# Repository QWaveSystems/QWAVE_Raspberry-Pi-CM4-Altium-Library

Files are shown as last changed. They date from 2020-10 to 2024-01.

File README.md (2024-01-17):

# QWAVE_Raspberry-Pi-CM4-Altium-Library
Raspberry Pi Compute Module 4 (CM4) Full Library, Design Template&amp;Guideline for Altium Designer

**If you find this package is useful, please consider supporting me.

# Contact me if you want customization. 
** Amornthep Phunsin amornthep@qwavesys.com

# Note:
**This library has been fully tested with various projects that I made refer below.**

# Demo Project: CM4 IoT Gateway,PCIe M2.SSD,Modbus 485/TCP,NB-IoT,GPS,WiFi,BT,DI/DO,Relay,AI (0-5/10)V.
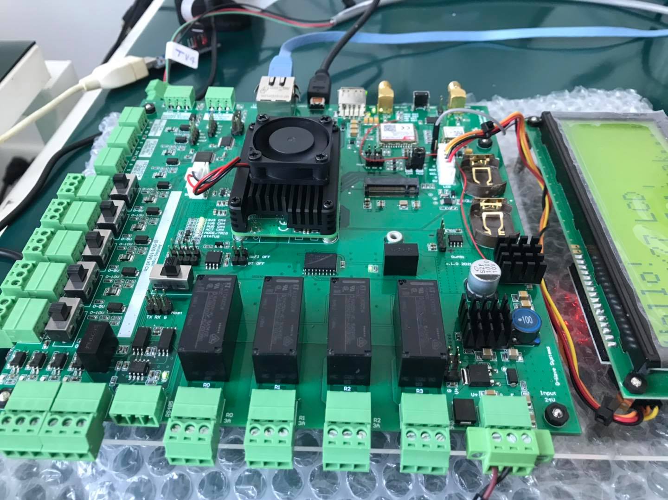
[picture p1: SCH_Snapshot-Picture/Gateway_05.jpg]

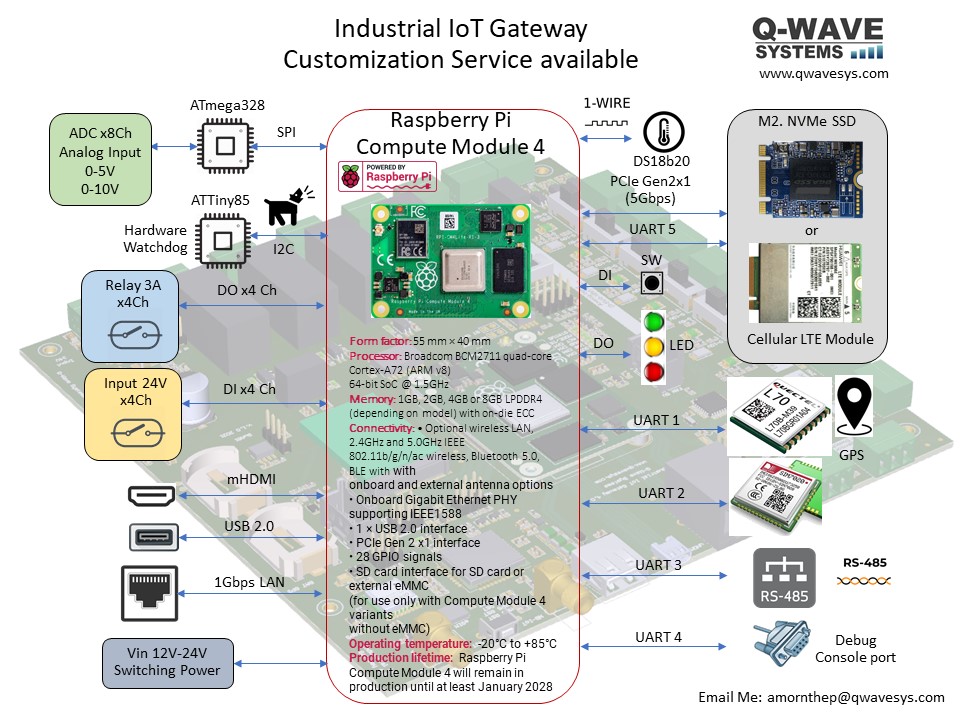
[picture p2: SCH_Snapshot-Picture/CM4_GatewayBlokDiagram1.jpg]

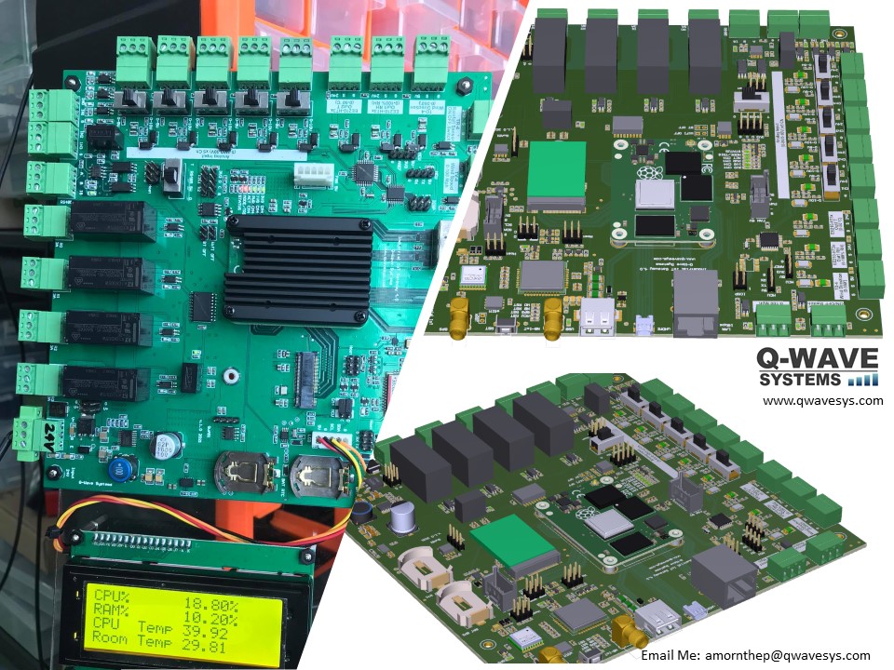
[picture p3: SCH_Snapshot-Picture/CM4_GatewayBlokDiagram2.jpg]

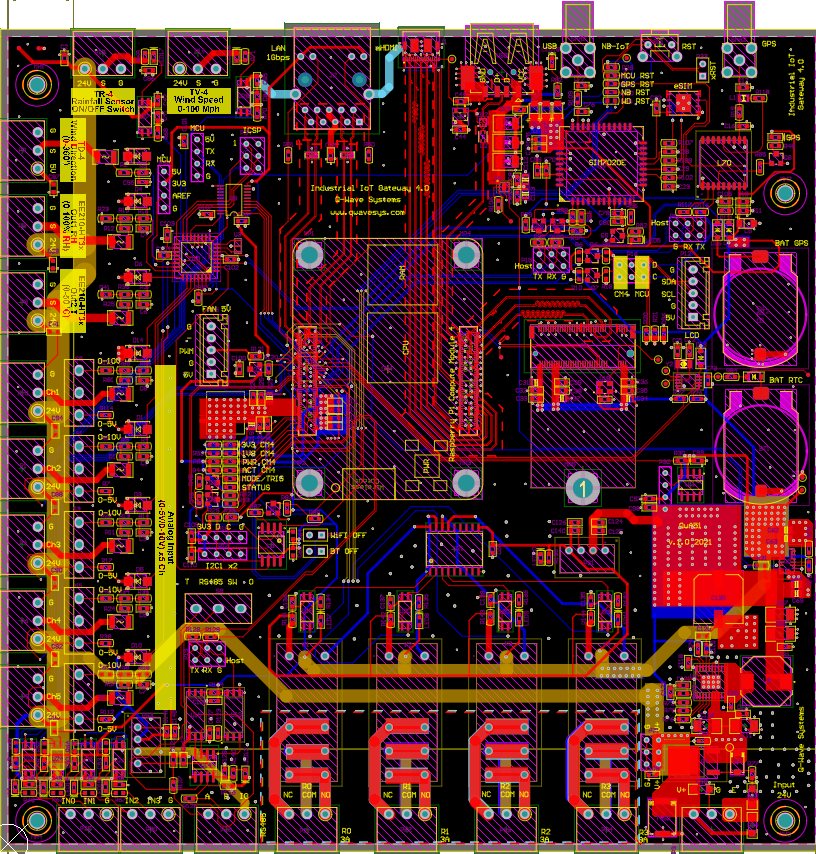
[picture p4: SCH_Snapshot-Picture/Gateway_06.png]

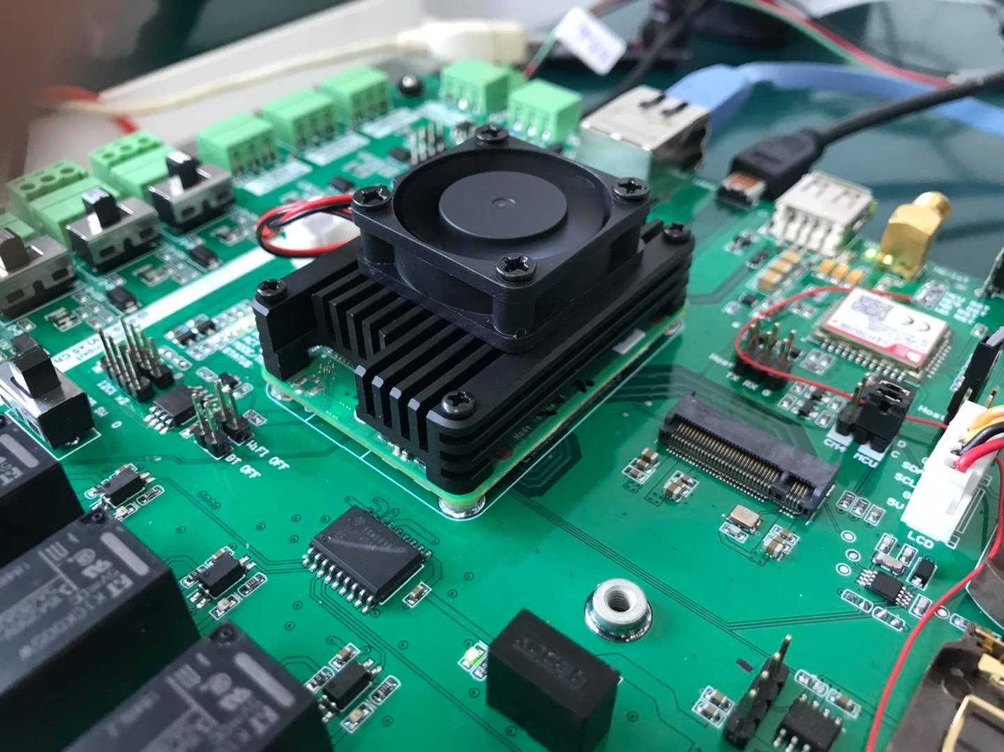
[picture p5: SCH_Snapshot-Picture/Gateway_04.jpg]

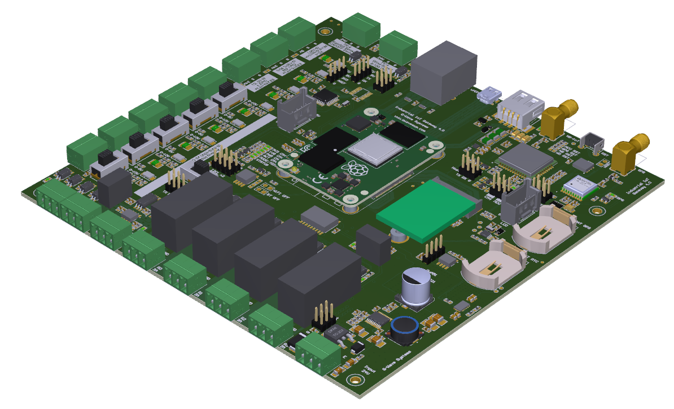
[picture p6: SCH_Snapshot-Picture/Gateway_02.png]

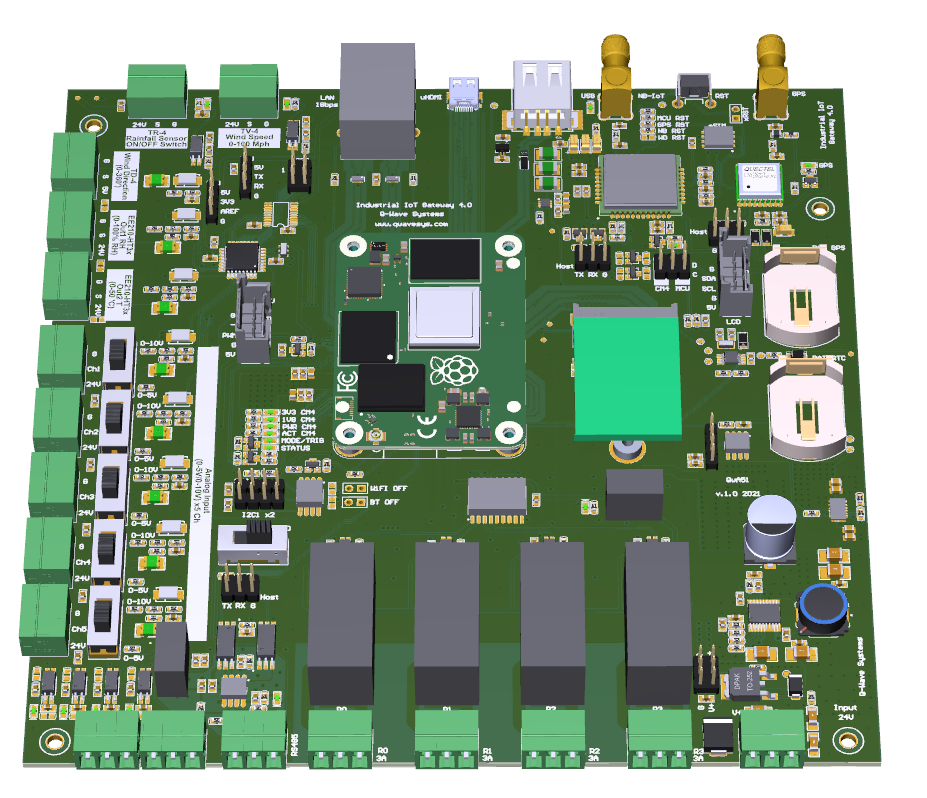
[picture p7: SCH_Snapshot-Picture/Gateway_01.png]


# Demo Project: CatsEYE Flasher - USB Flasher for CM4.
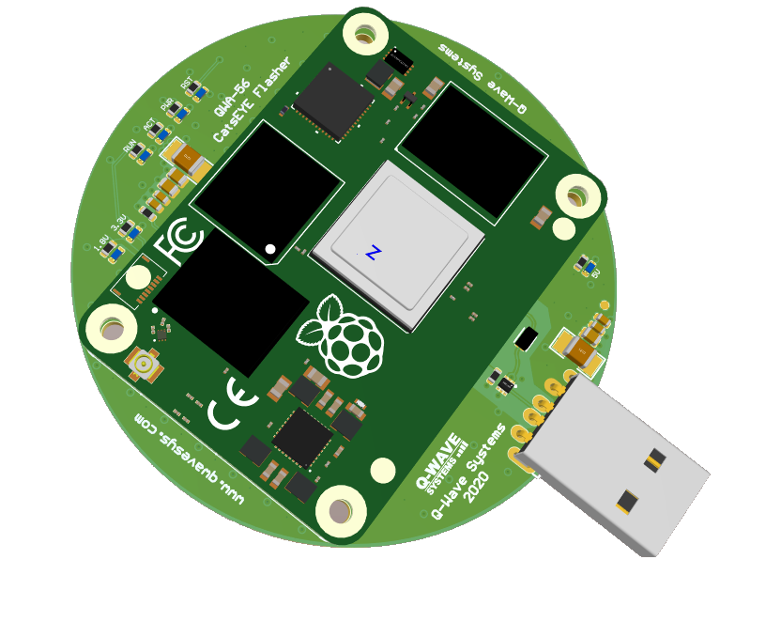
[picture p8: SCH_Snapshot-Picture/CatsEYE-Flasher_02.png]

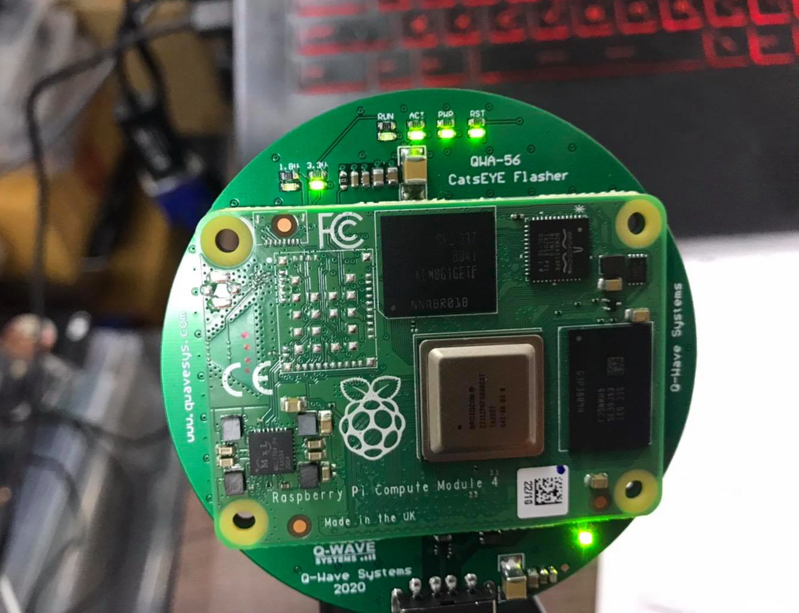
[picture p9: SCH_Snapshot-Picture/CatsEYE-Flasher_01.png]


# Demo Project: CatsPi Dev Board - Rpi CM4 dev board (85x56mm) compatible with standard HAT and enclosure.
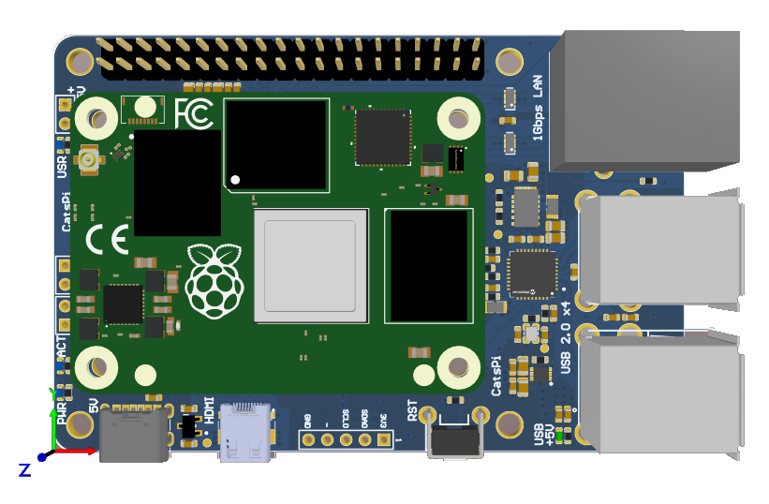
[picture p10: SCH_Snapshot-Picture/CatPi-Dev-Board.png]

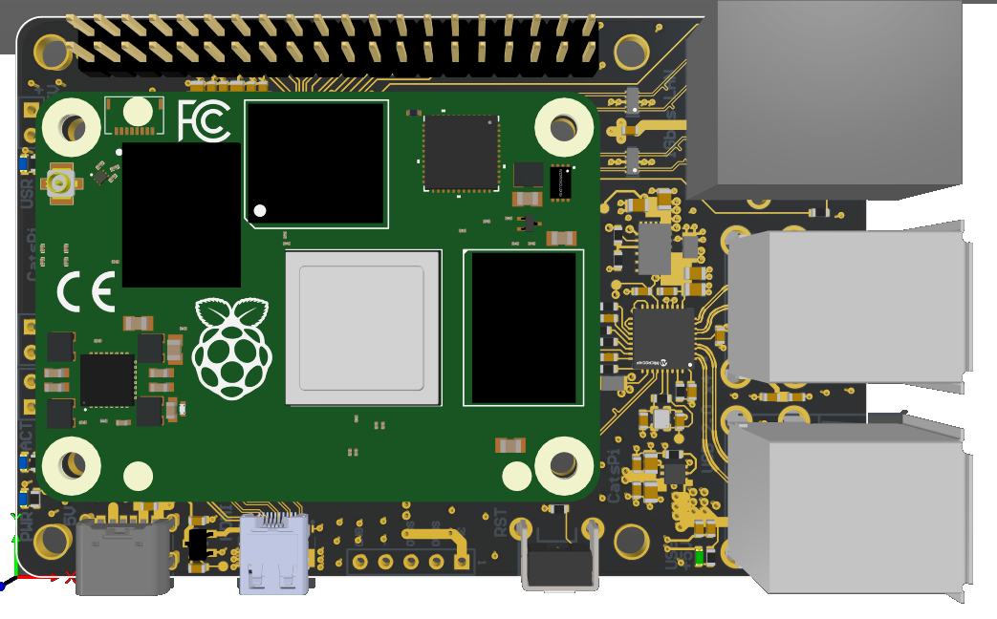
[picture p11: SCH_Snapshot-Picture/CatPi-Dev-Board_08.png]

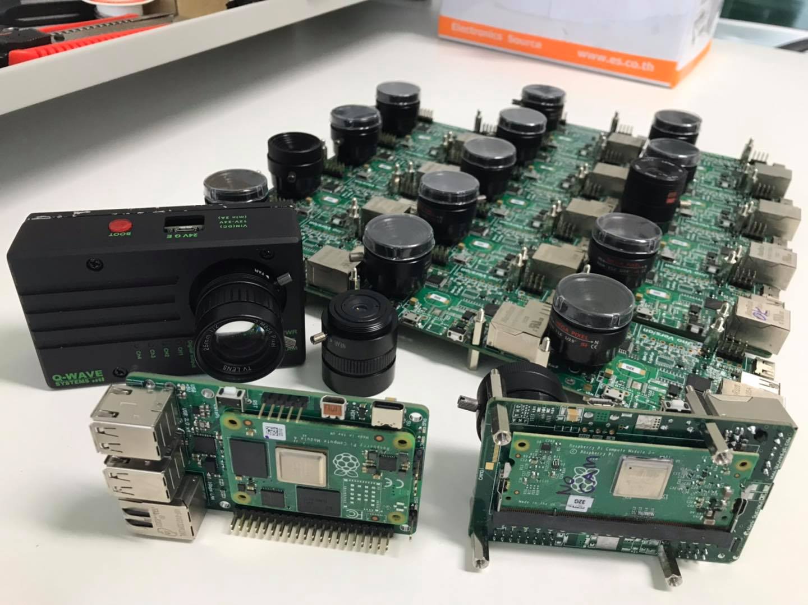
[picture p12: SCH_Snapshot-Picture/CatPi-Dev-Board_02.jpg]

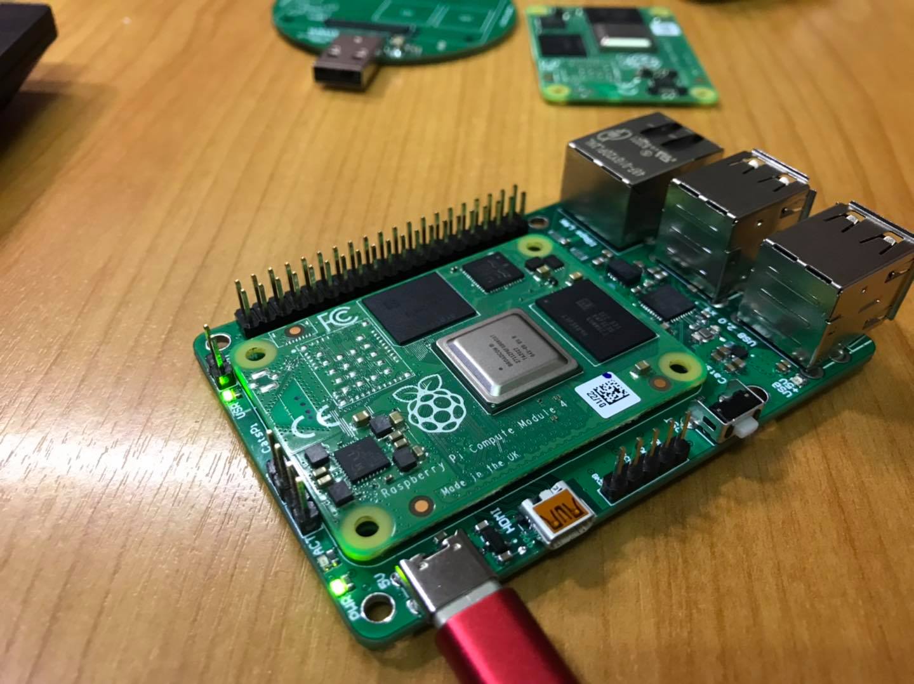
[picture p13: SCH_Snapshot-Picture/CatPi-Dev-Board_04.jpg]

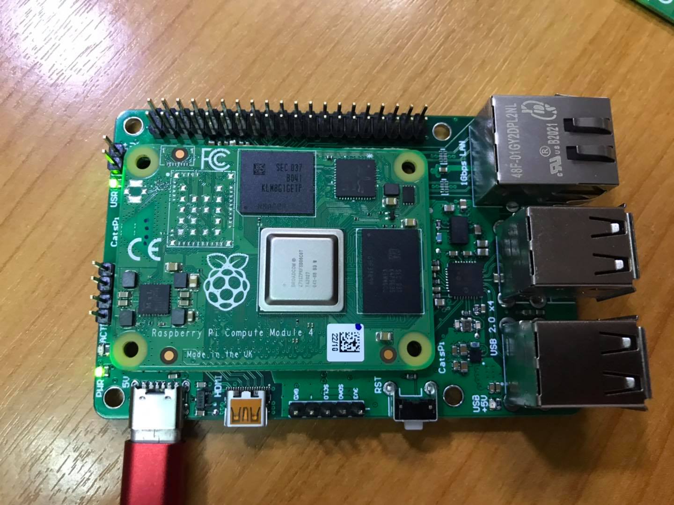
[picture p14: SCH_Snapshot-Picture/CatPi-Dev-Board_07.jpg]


# Demo Project: SeaBOX HDMI Stick using CM4.
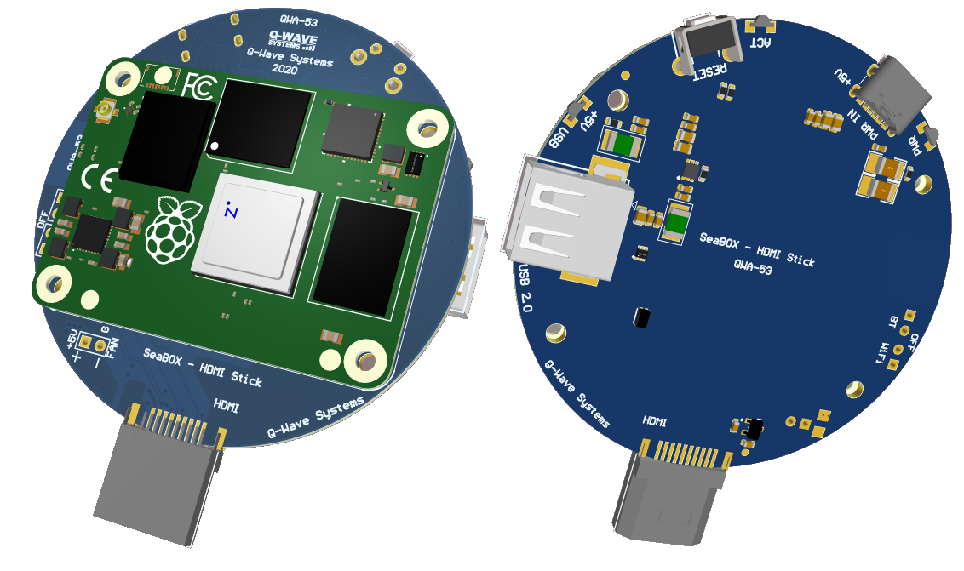
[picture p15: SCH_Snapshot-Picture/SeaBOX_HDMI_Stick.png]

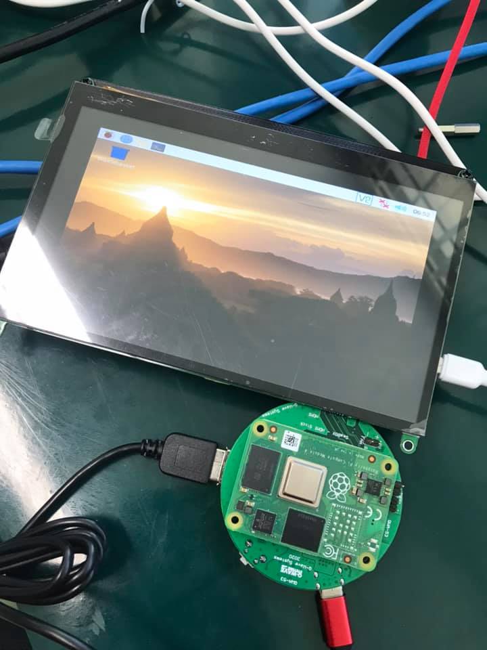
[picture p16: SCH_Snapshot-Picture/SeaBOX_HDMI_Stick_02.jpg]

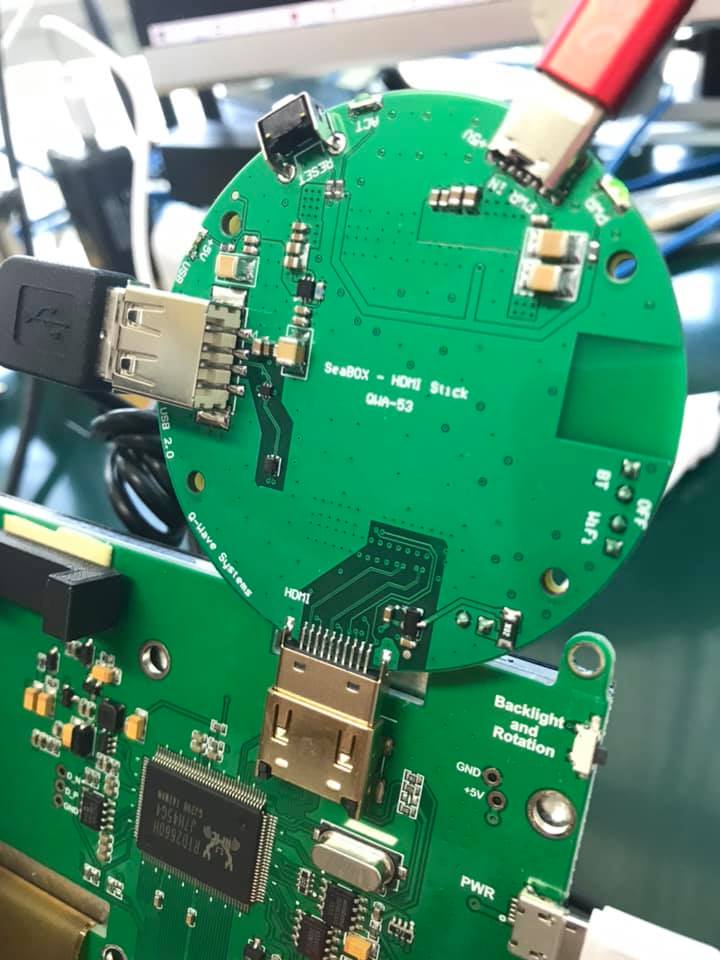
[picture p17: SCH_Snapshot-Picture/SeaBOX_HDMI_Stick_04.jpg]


# Demo Project: CatsPi HAT Flip Edition - compatible with standard HAT plug at bottom side.
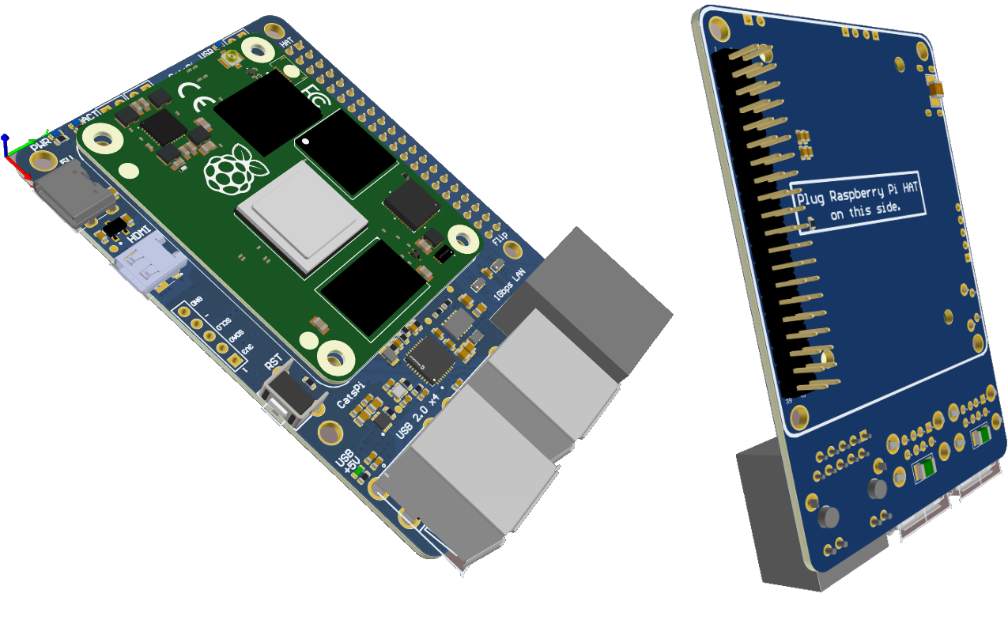
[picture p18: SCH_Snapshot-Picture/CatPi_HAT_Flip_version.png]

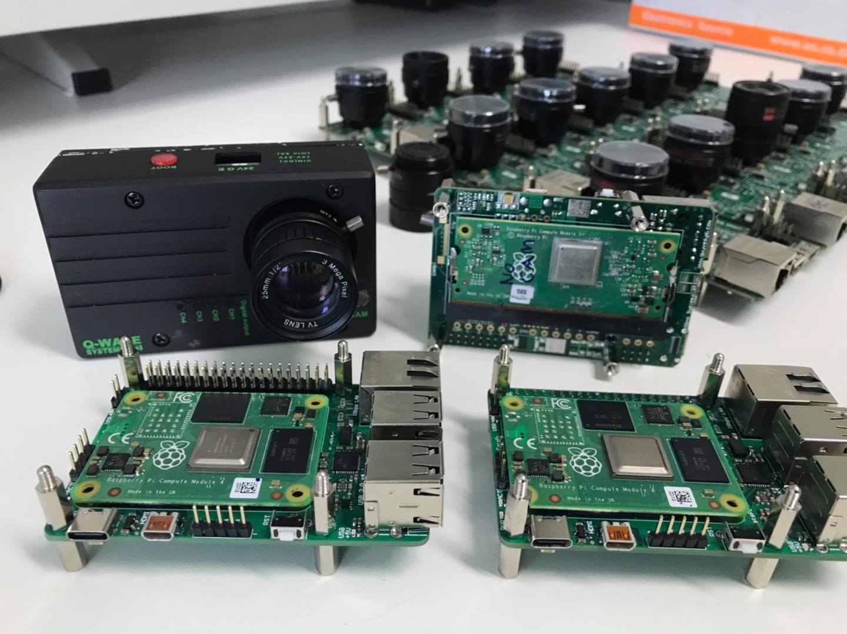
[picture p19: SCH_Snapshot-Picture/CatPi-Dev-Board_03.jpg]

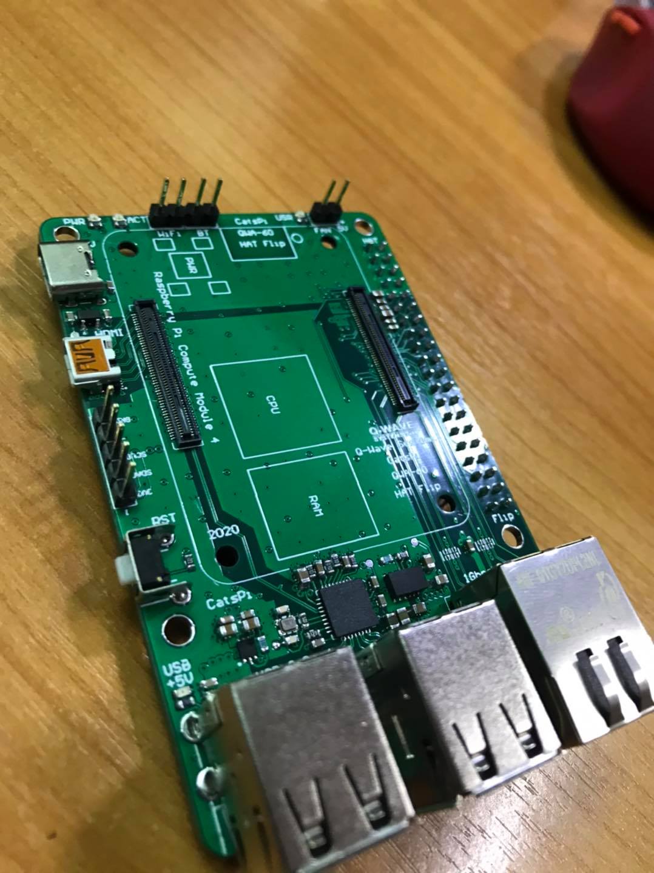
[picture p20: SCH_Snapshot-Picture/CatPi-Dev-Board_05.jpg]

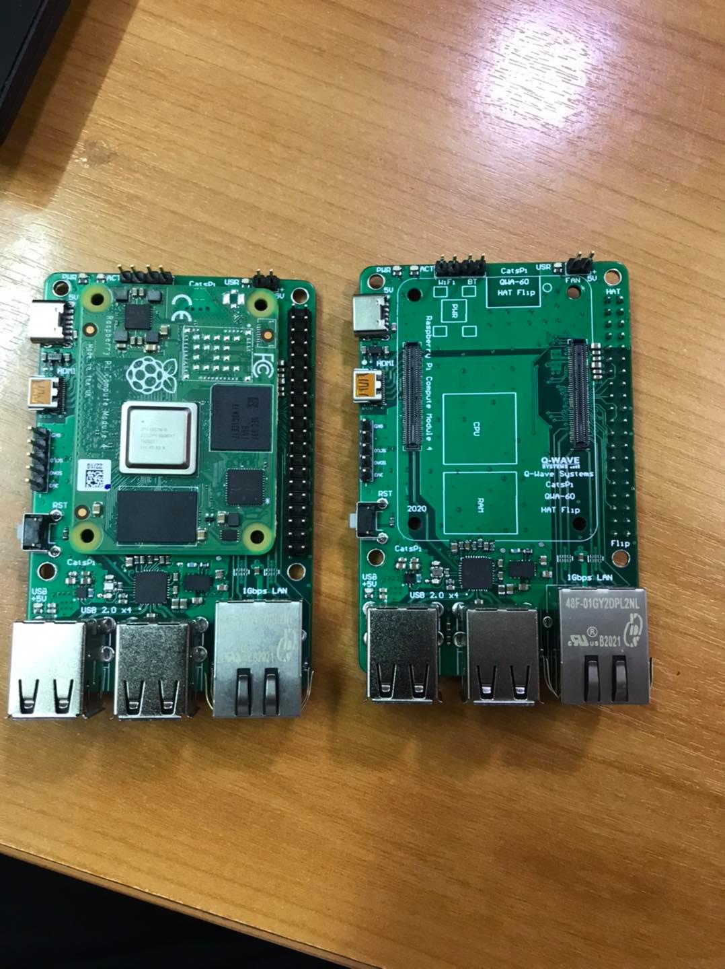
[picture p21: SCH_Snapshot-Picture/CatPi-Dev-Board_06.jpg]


# Demo Project: SeaBOX HDMI Stick PoE Edition.
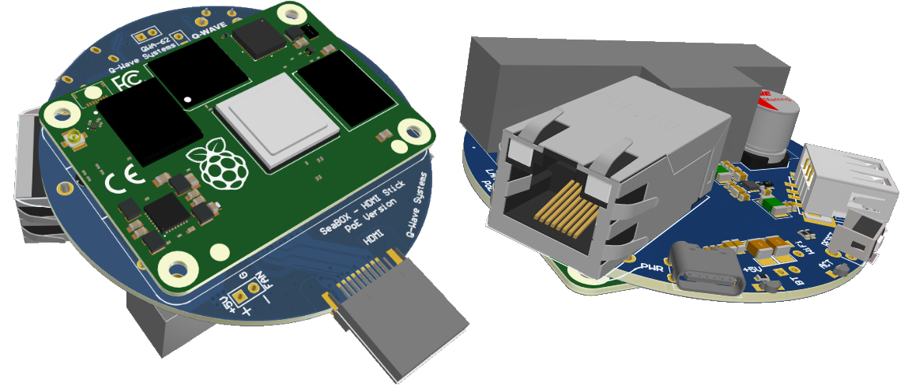
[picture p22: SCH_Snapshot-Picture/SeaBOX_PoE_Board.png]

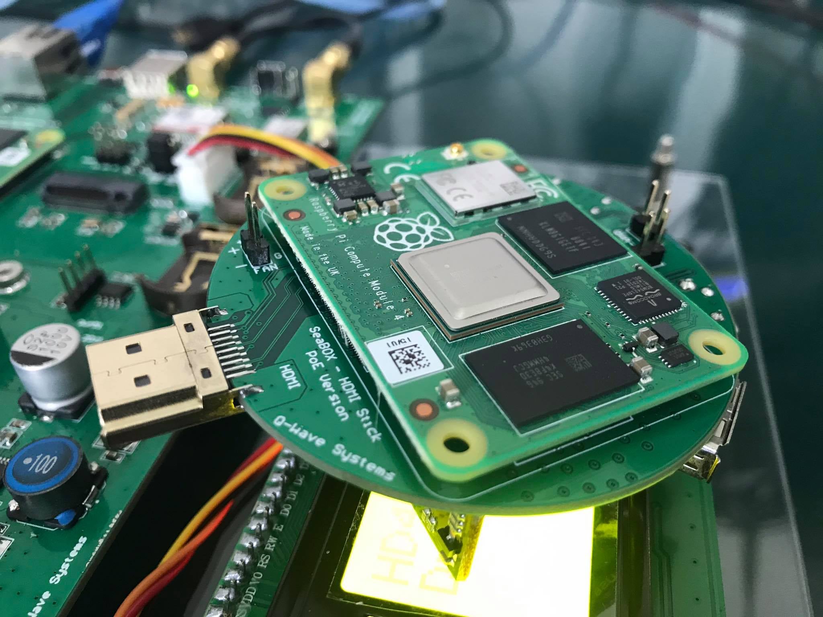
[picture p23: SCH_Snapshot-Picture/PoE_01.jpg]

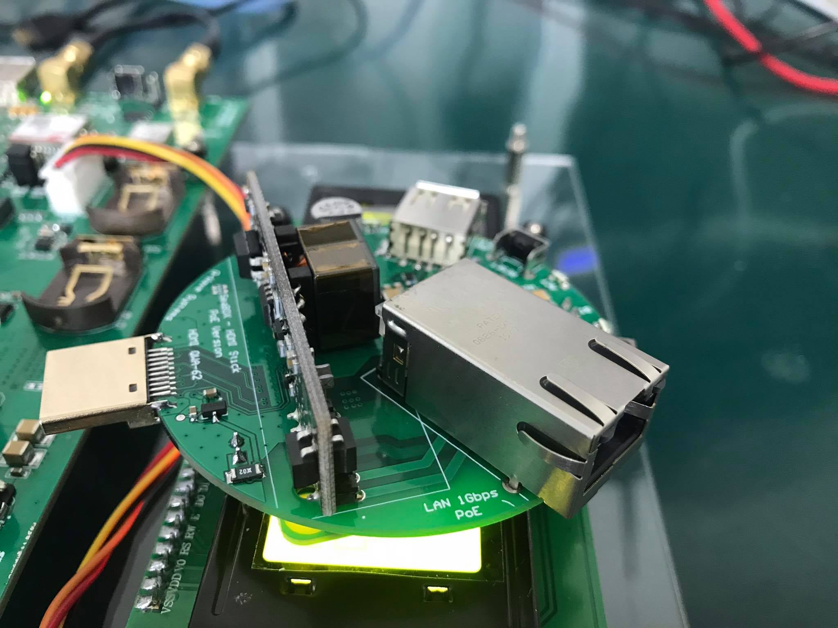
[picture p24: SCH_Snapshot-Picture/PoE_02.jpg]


# Official Raspberry Pi Document for CM4.

[Compute Module IO board design data](https://github.com/raspberrypi/documentation/blob/master/hardware/computemodule/designfiles.md)

[Compute Module 4 IO Board datasheet](http://datasheets.raspberrypi.org/cm4io/cm4io-datasheet.pdf)

[Compute Module 4 IO Board KiCAD PCB design](http://datasheets.raspberrypi.org/cm4io/CM4IO-KiCAD.zip)

[CM4 3D Model STEP File](https://datasheets.raspberrypi.org/cm4/CM4-step.zip)

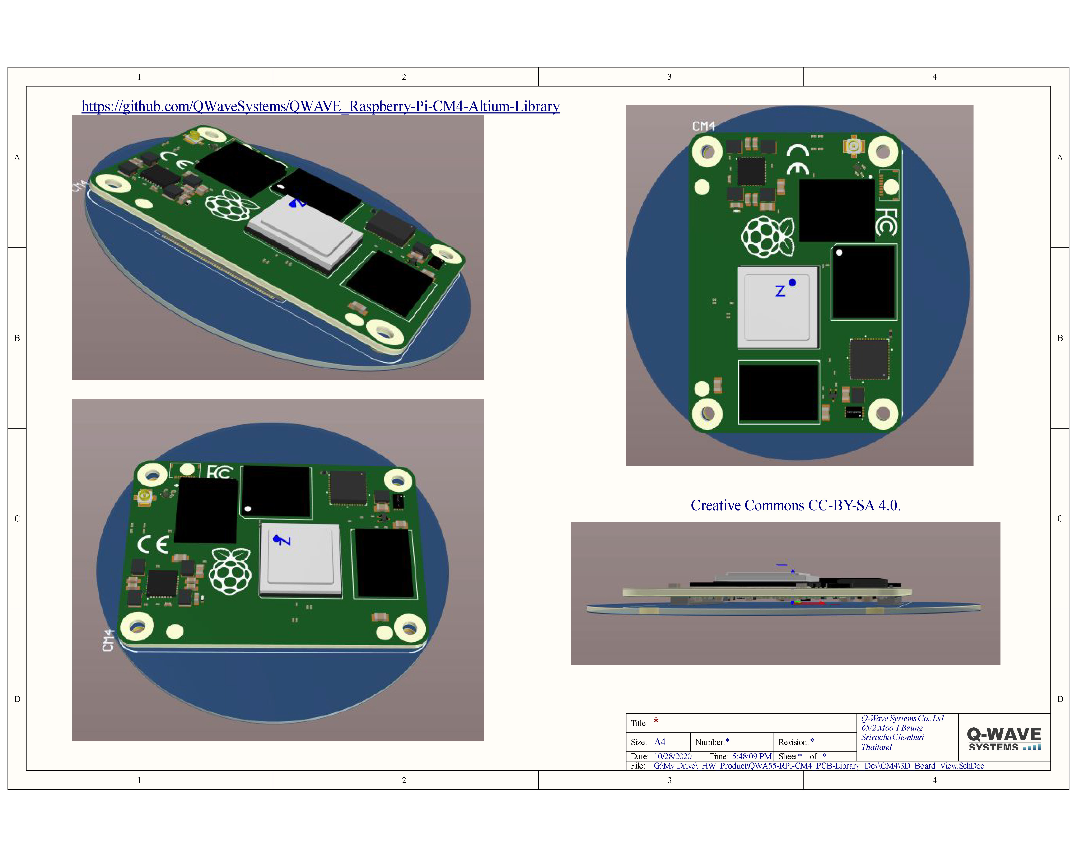
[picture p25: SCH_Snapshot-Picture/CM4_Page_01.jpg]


## Description:
These are the schematic libs,footprint libs,sch template,guideline for design custom carrier circuit board for Raspbeery Pi compute module 4 (CM4).

## License:
Raspberry Pi Compute Module 4 (CM4) Full Library for Altium Designer

Copyright (C) 2020 Amornthep Phunsin
Email: amornthep@qwavesys.com

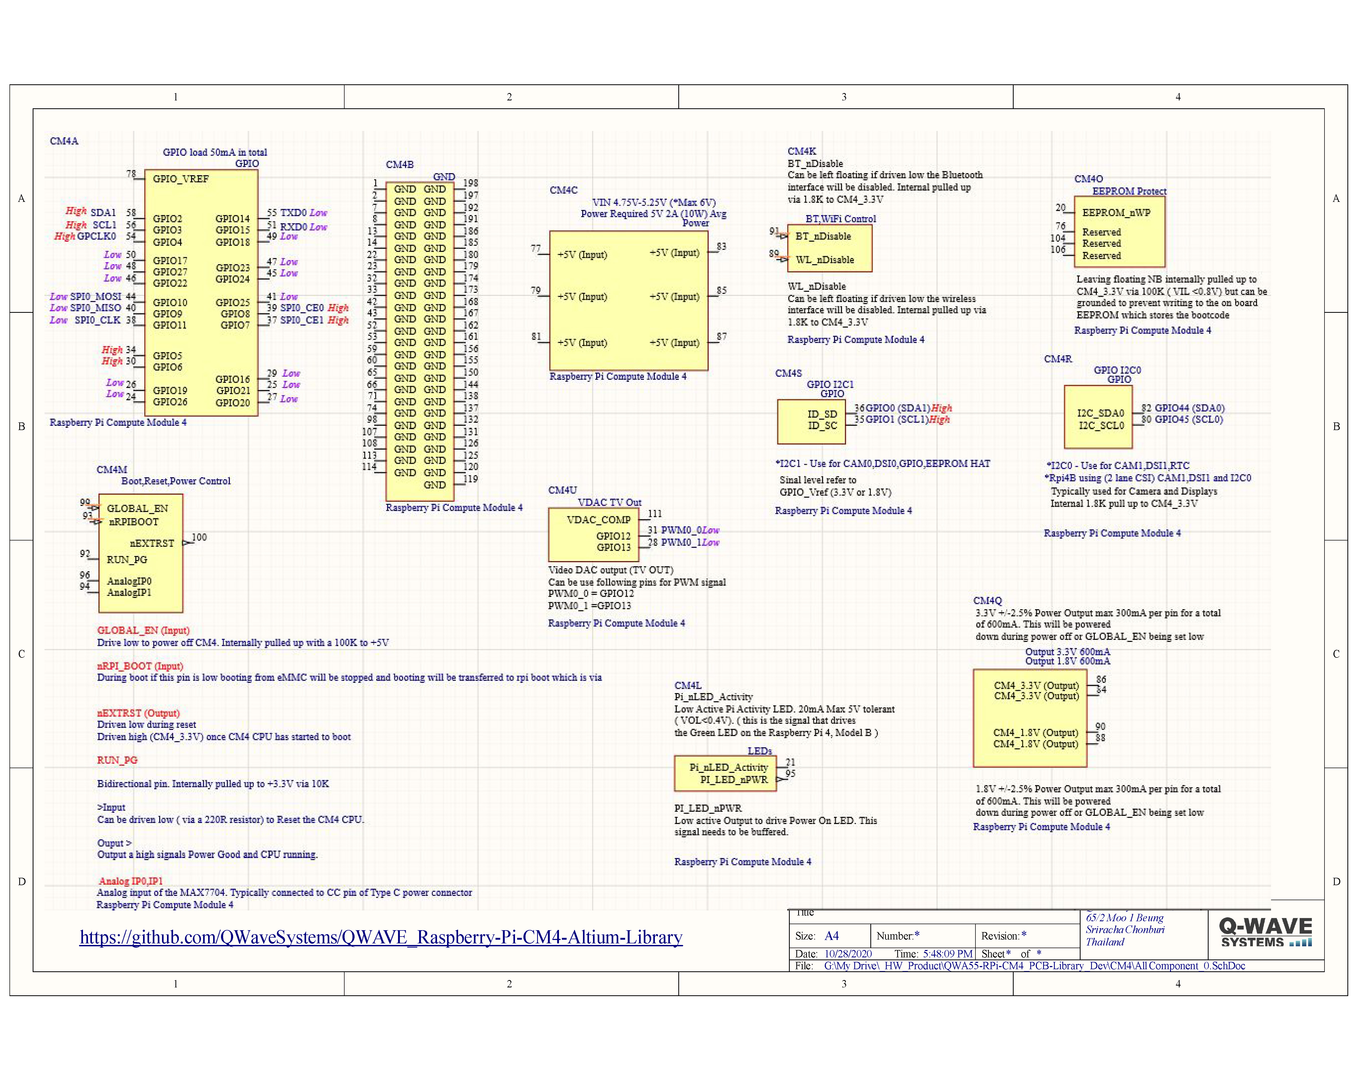
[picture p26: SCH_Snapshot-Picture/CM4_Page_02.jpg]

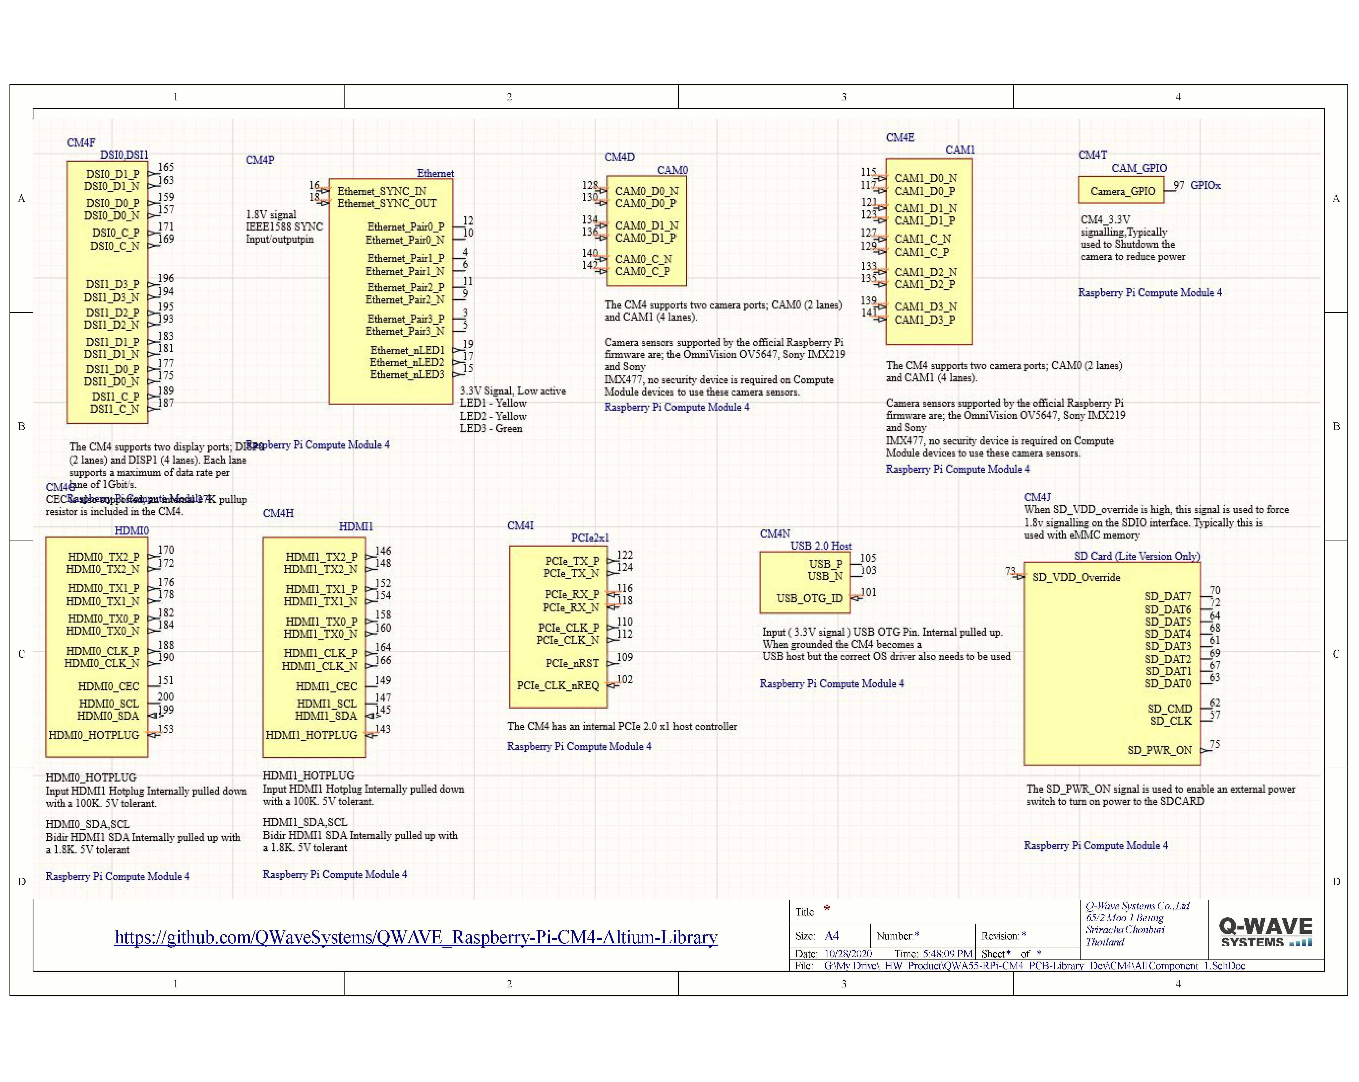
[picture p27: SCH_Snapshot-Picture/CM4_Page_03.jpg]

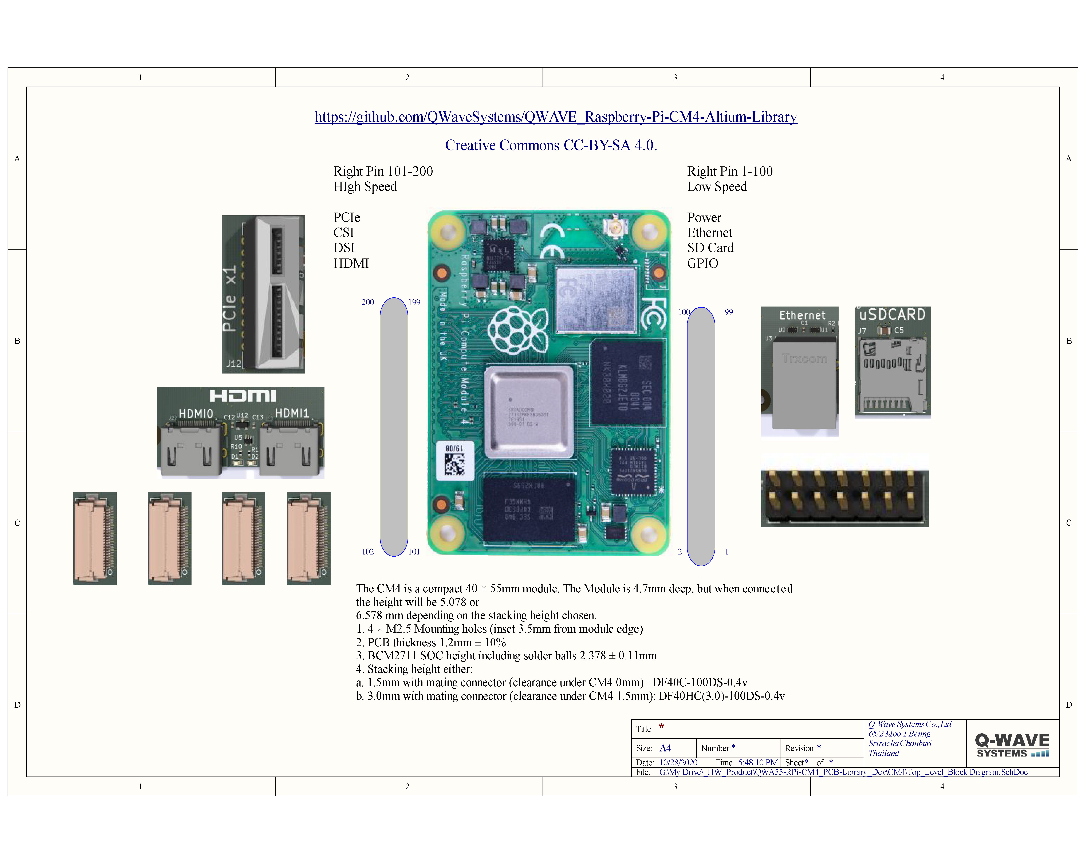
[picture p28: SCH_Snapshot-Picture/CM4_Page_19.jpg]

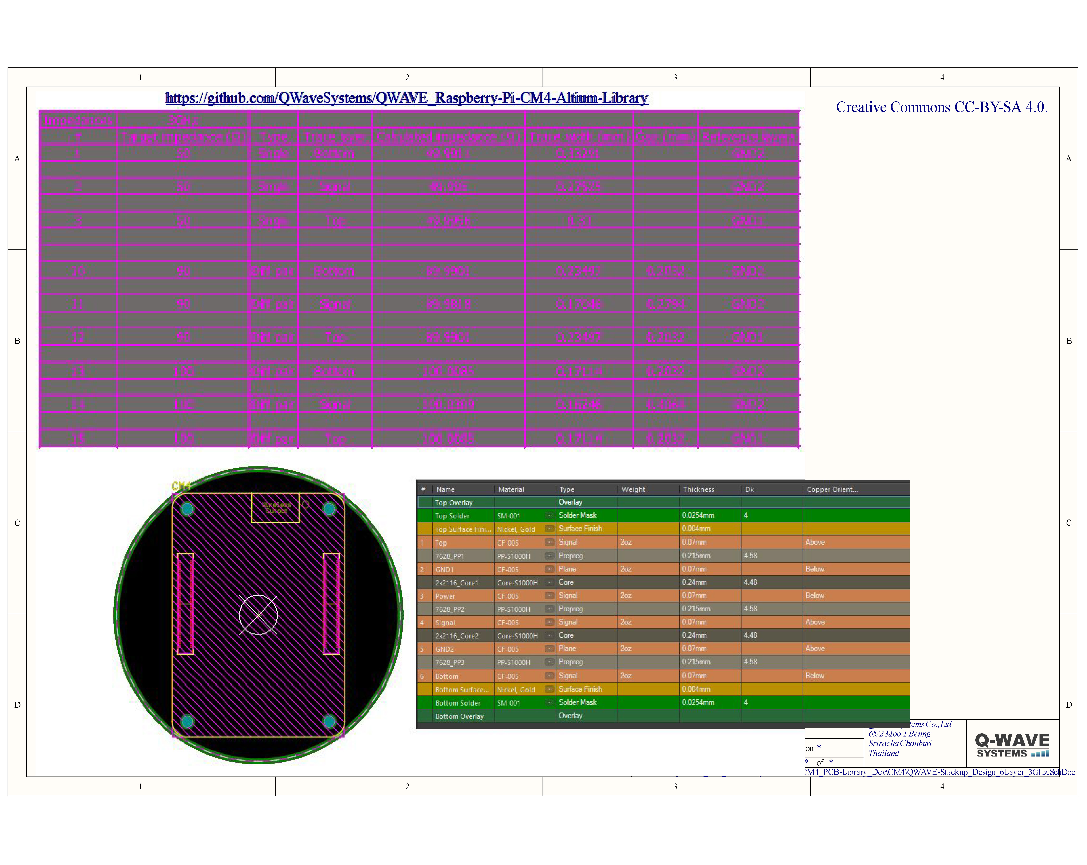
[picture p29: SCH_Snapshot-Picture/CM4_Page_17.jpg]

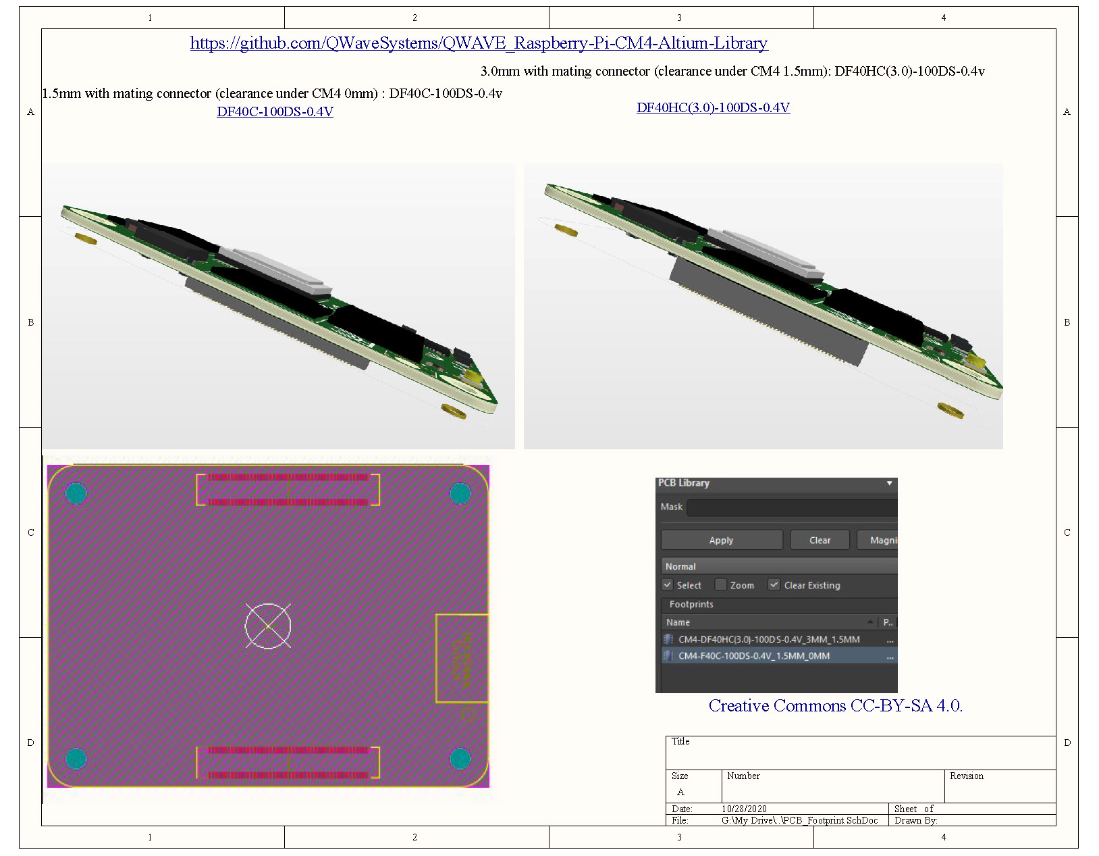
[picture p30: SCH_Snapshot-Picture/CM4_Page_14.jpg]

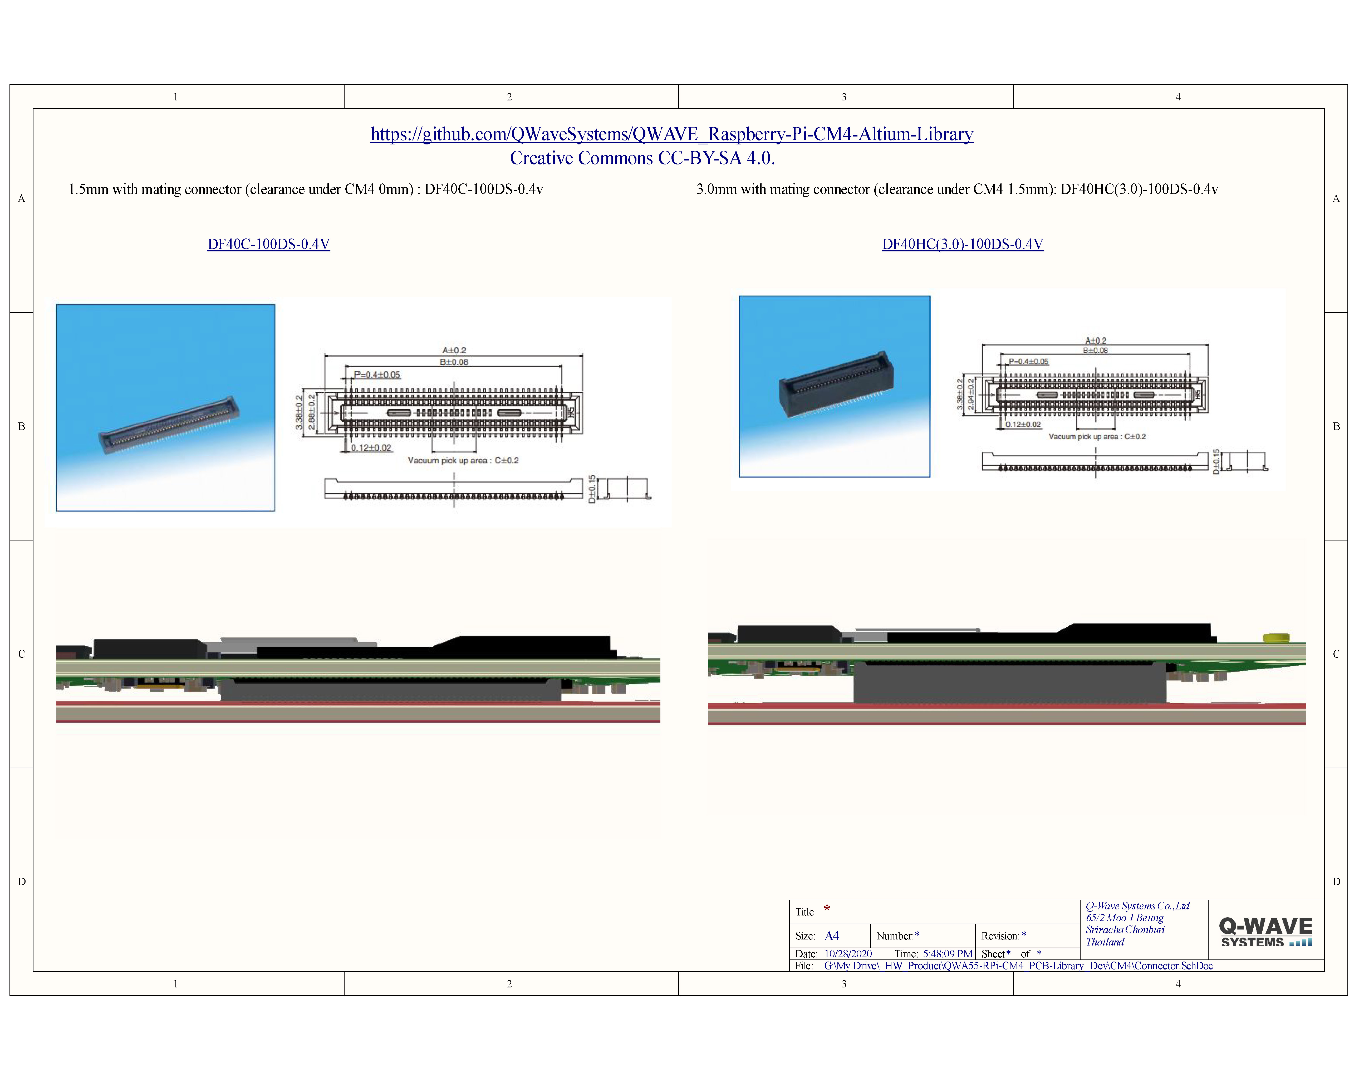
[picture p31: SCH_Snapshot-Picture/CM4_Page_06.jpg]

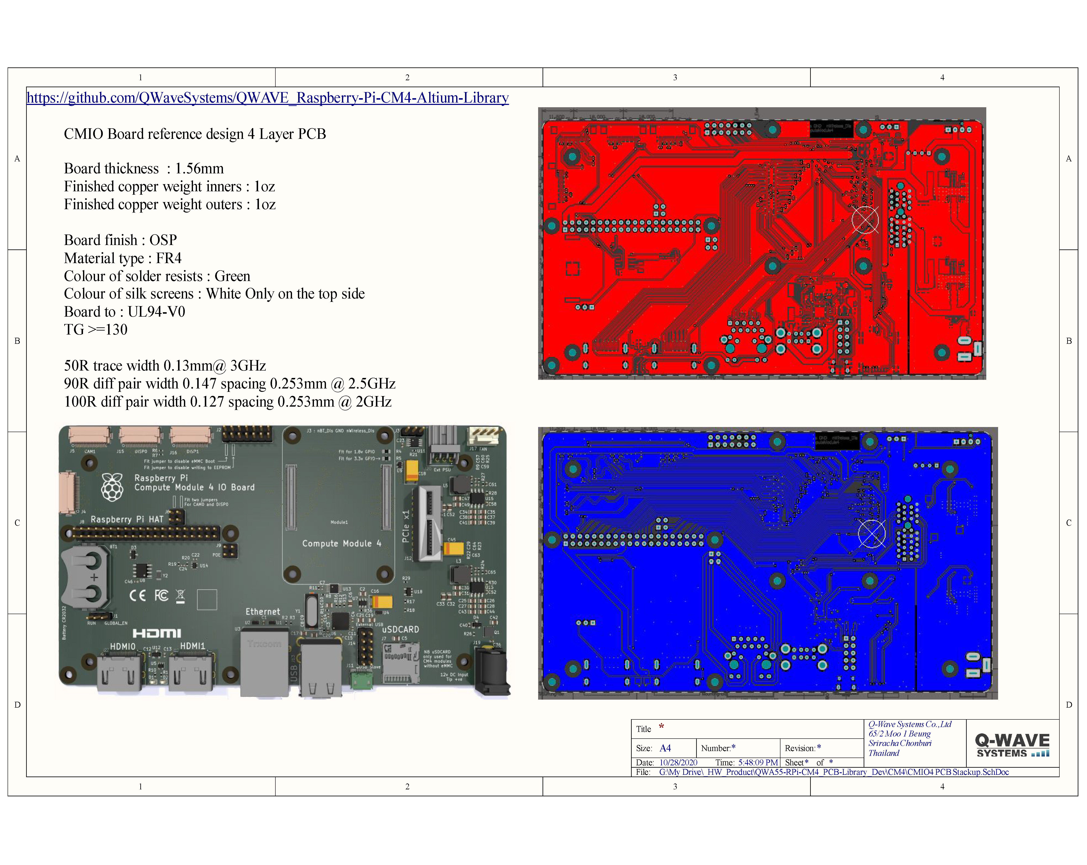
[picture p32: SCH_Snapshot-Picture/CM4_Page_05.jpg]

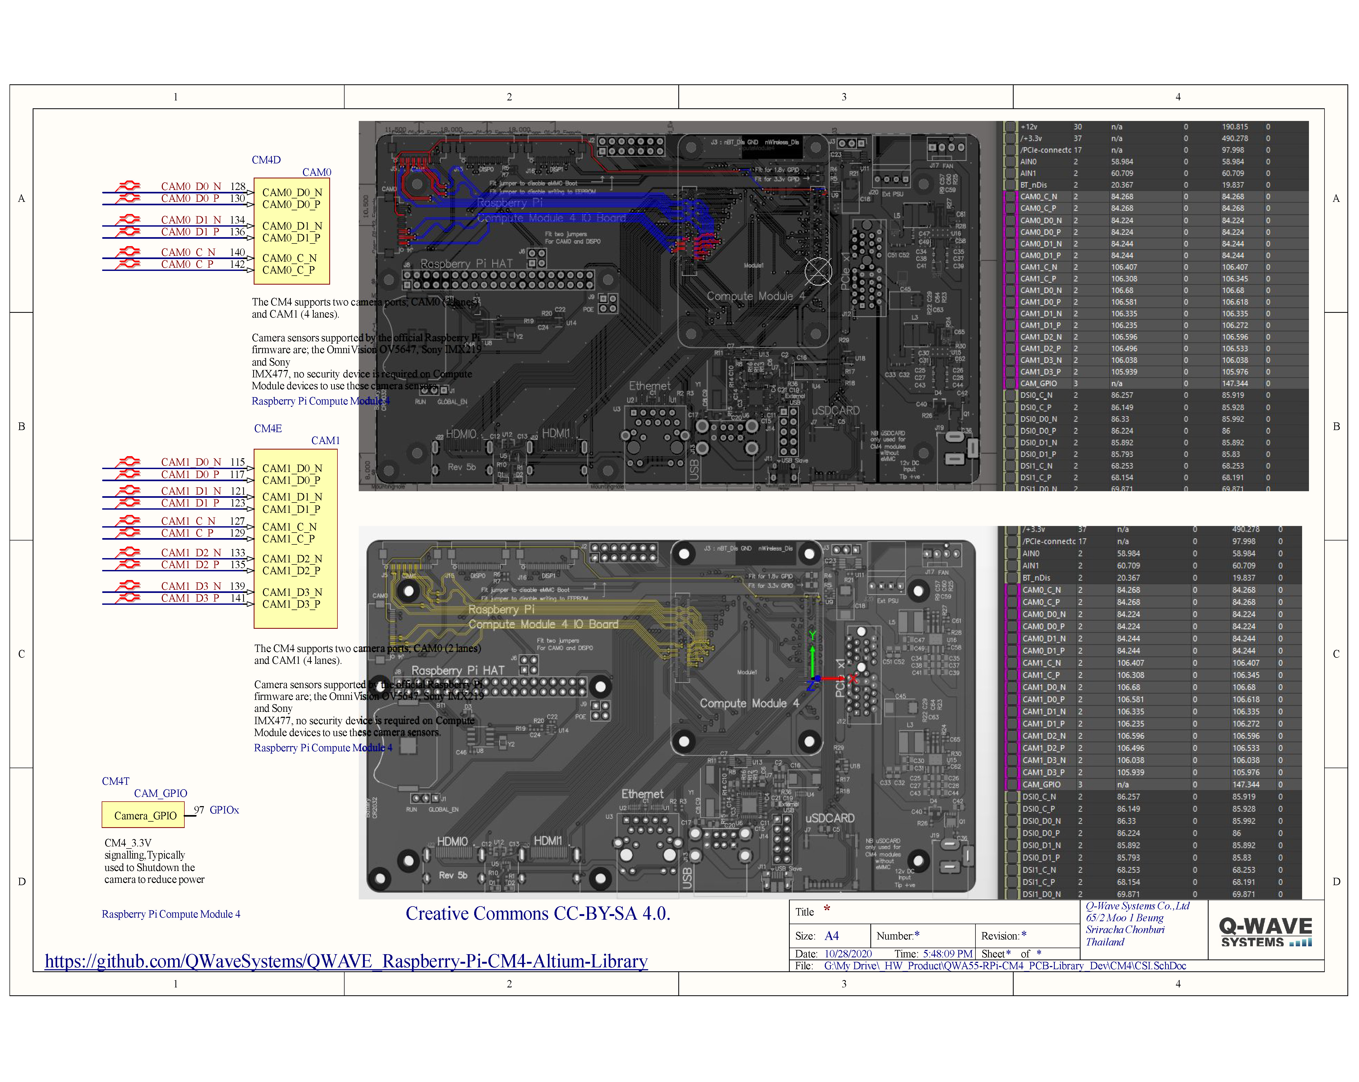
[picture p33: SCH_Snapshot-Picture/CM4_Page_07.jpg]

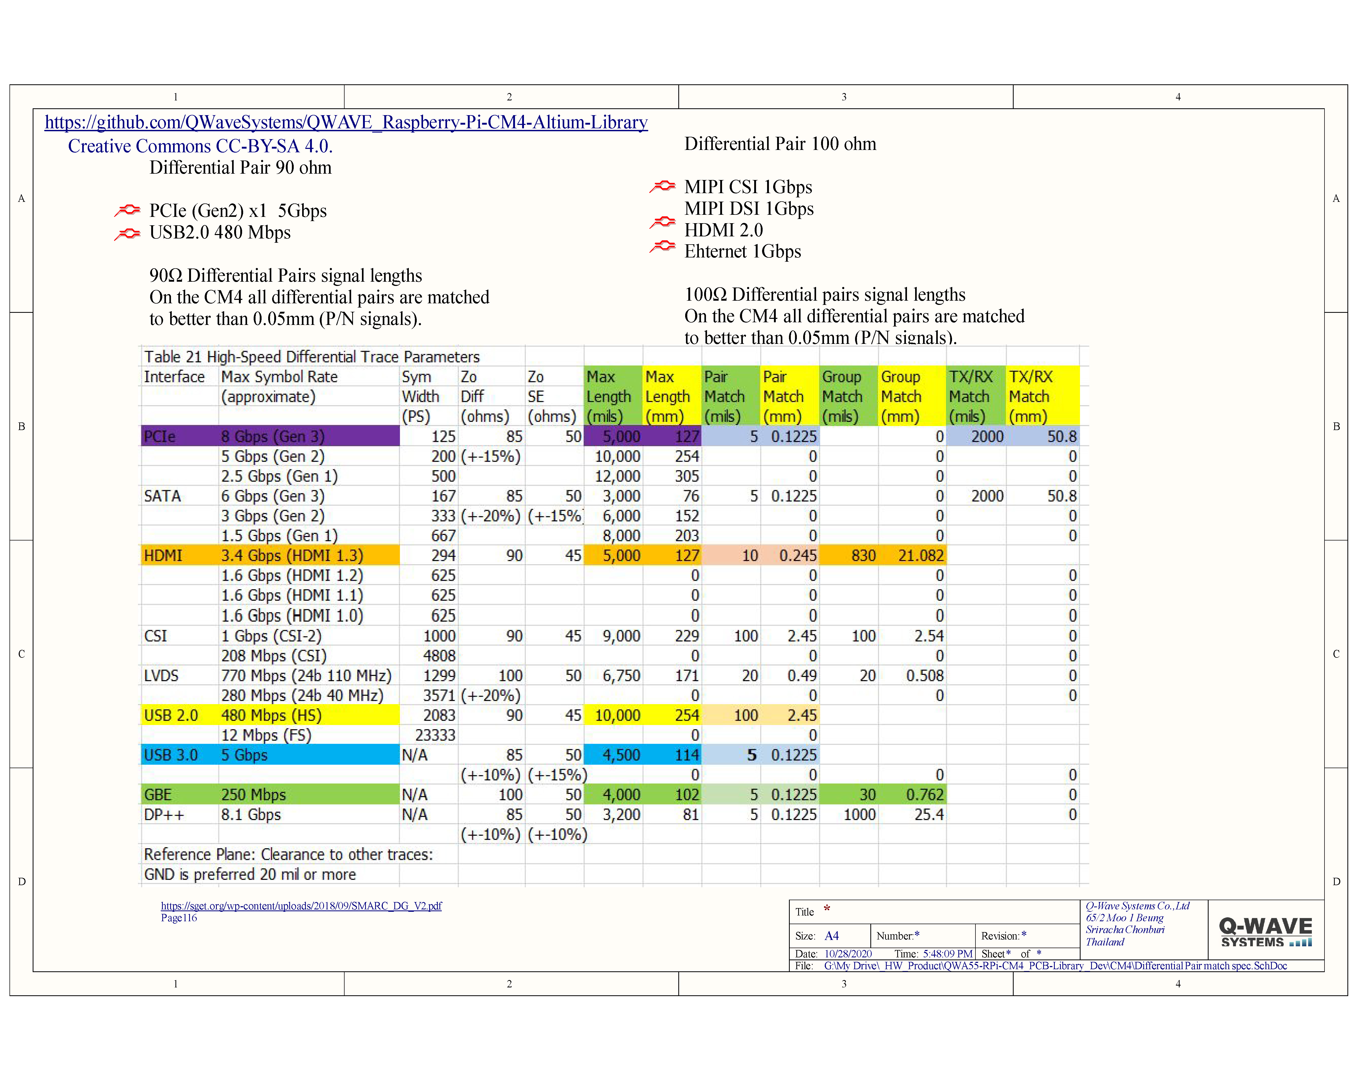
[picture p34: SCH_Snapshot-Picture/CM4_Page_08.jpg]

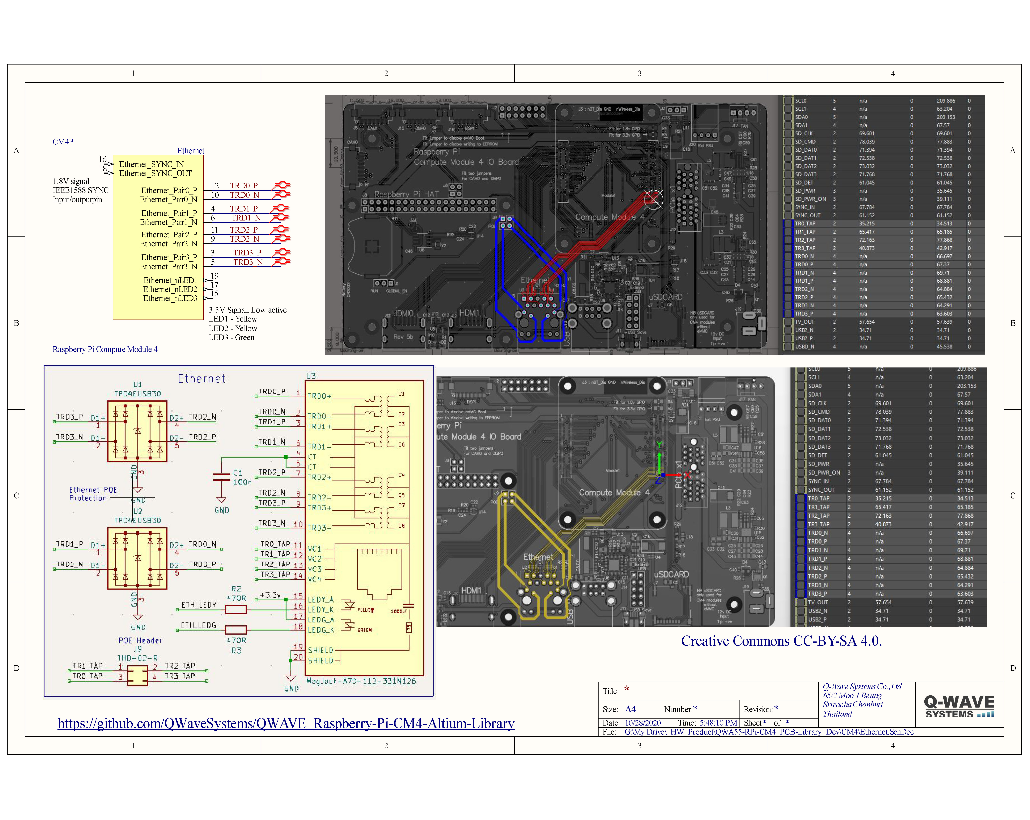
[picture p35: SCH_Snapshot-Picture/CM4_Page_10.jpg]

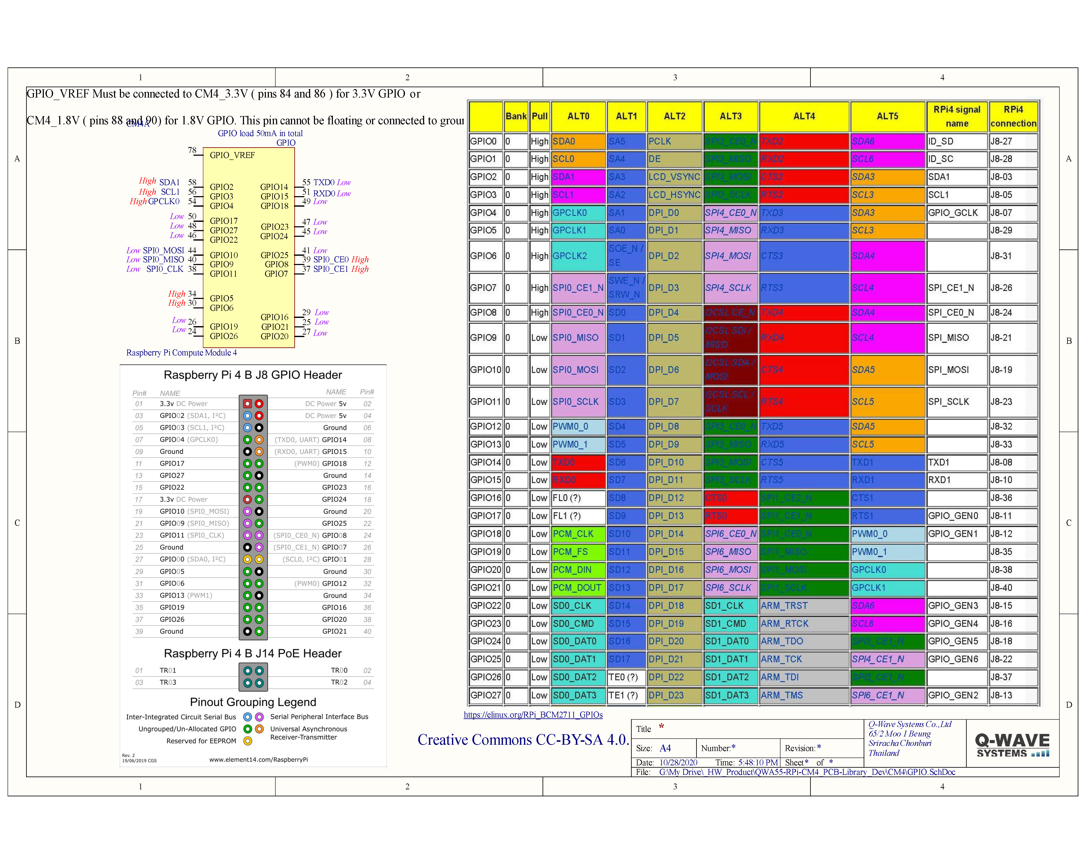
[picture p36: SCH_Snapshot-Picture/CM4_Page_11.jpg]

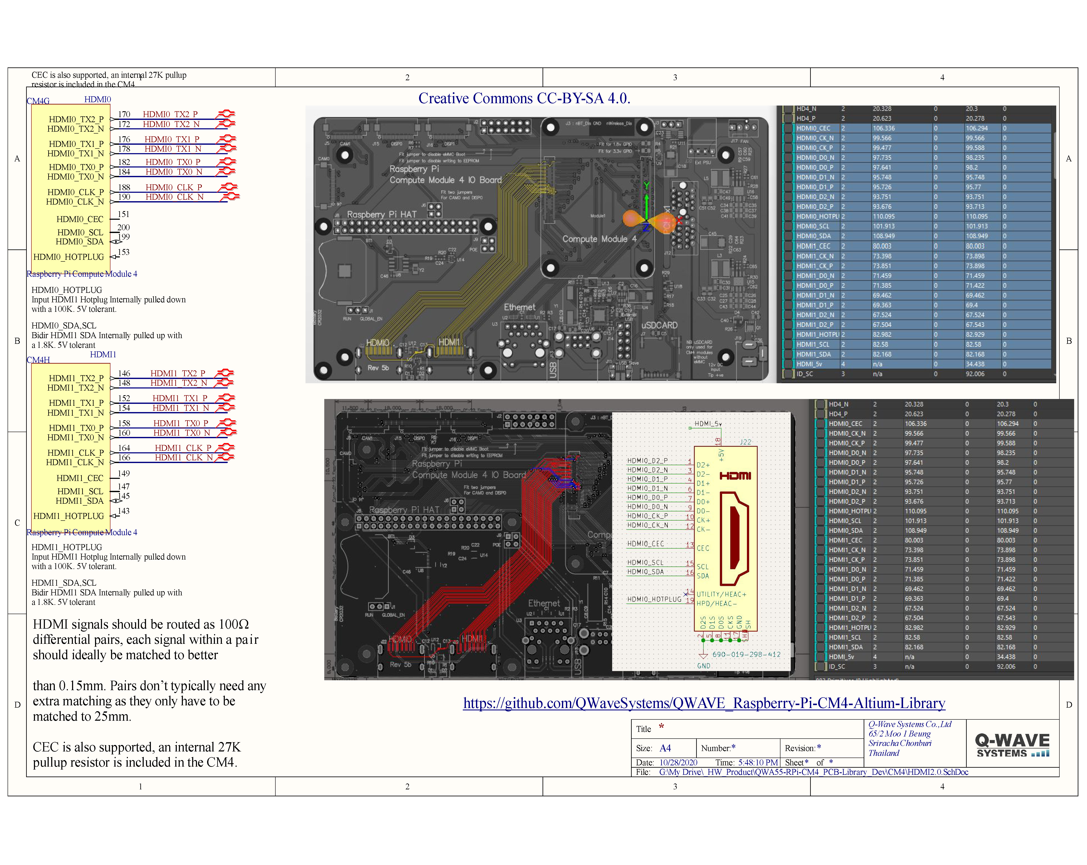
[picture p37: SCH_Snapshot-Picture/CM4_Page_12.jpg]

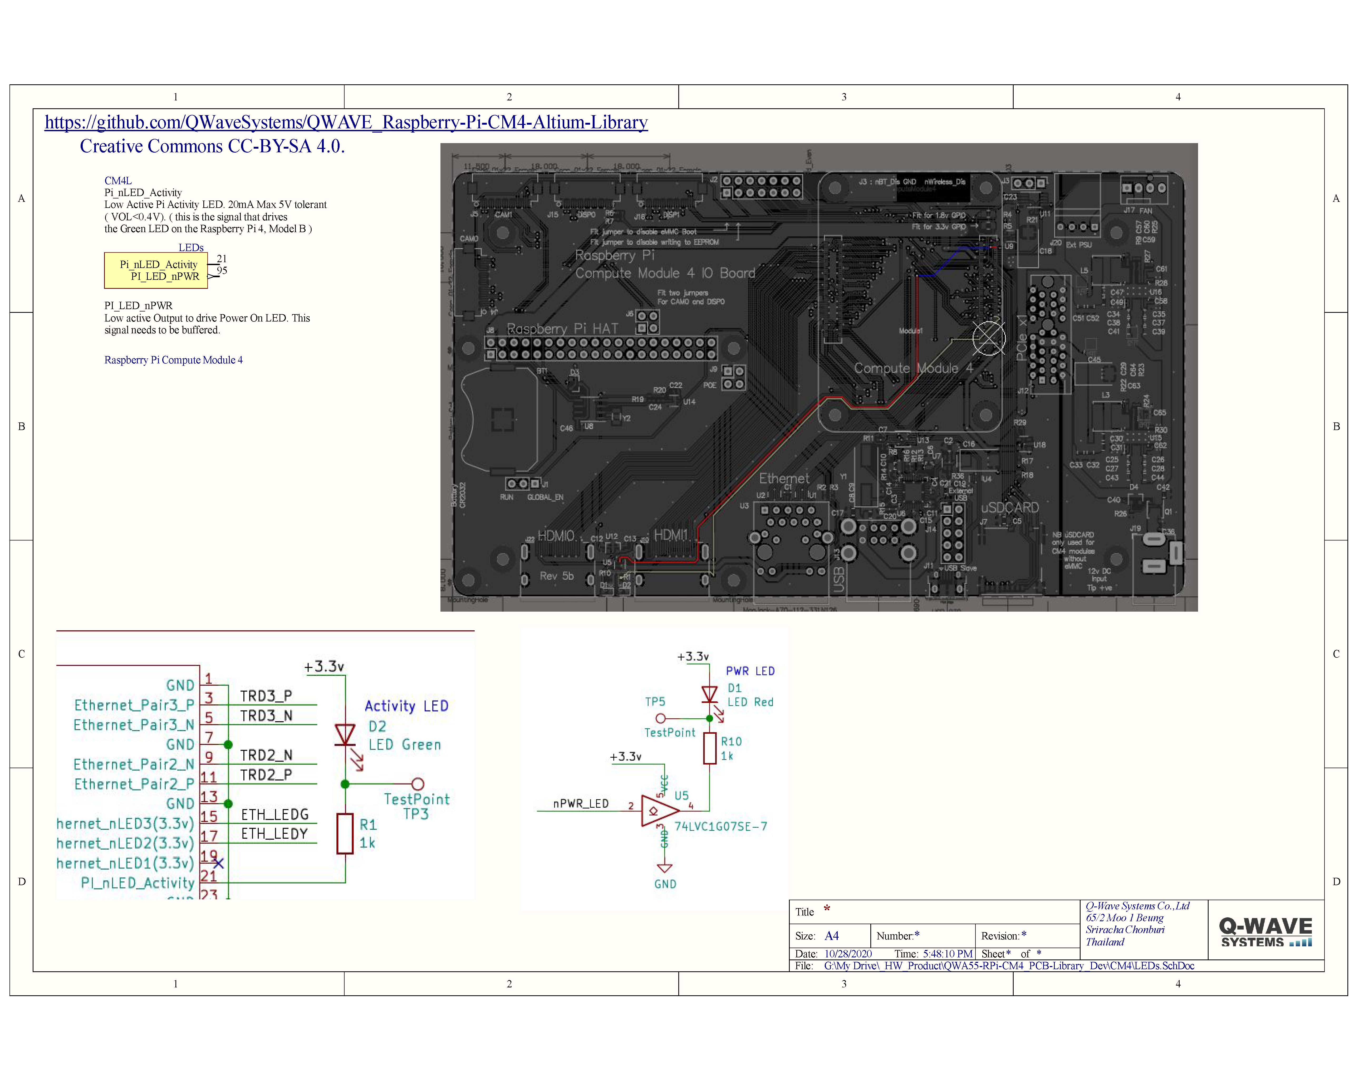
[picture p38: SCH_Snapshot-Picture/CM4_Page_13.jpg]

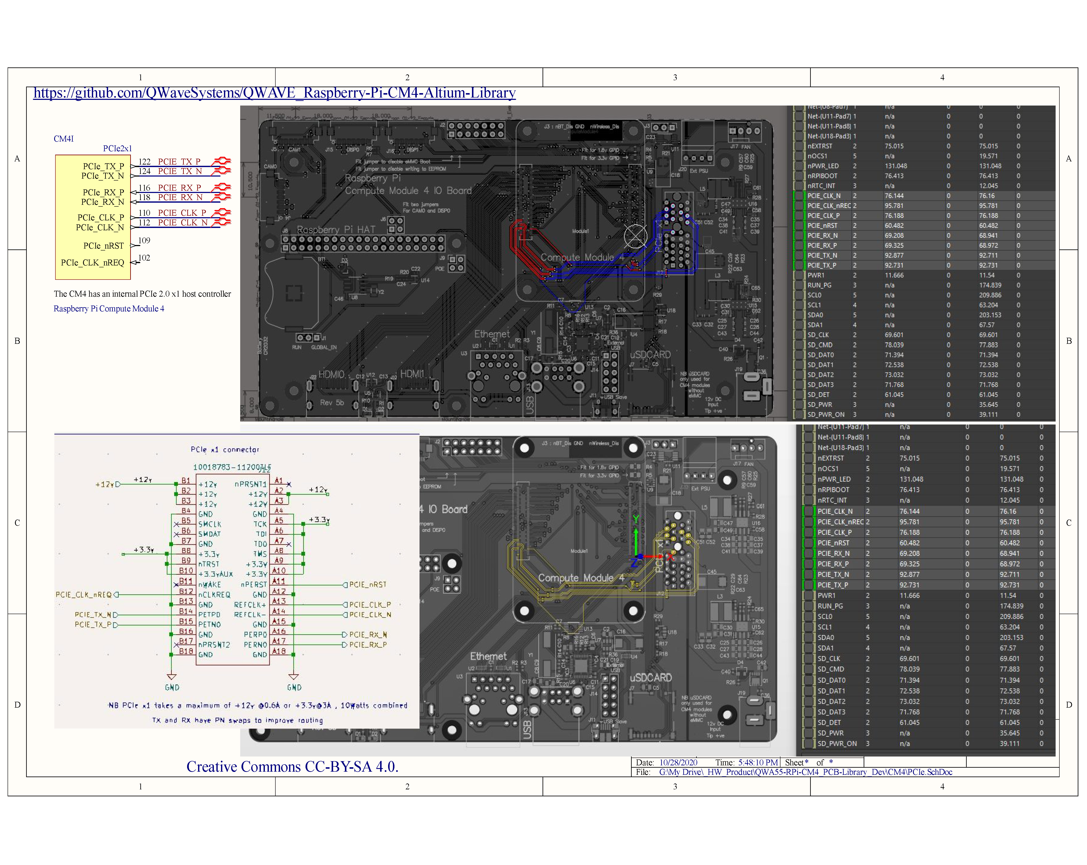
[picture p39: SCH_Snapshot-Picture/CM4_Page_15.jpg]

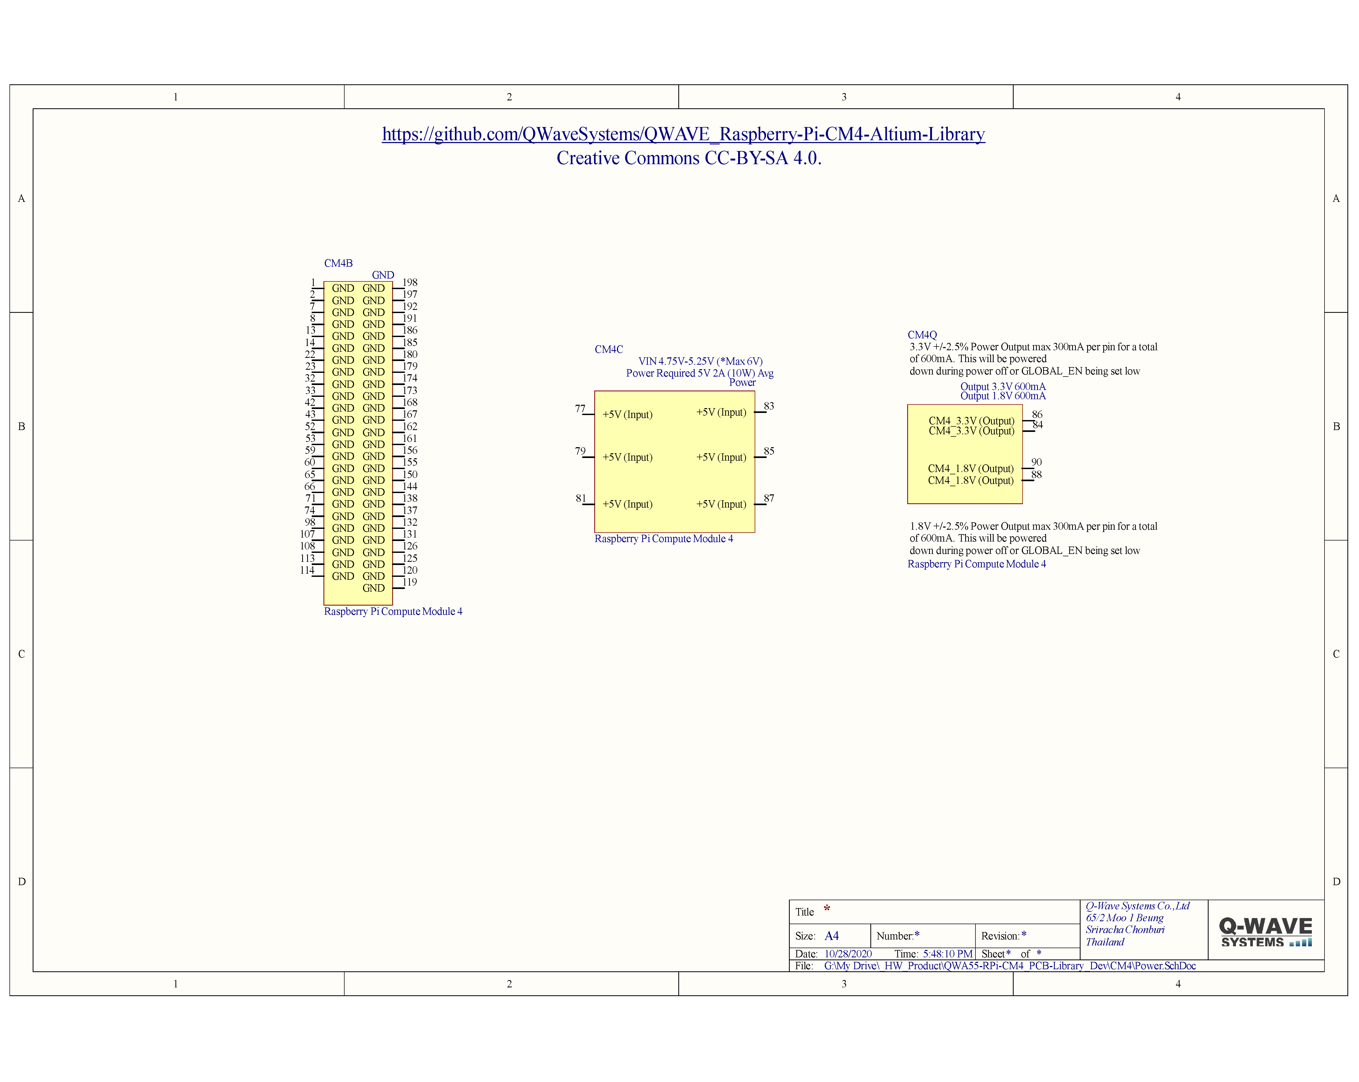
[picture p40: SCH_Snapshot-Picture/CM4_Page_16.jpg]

Device
Device
Device

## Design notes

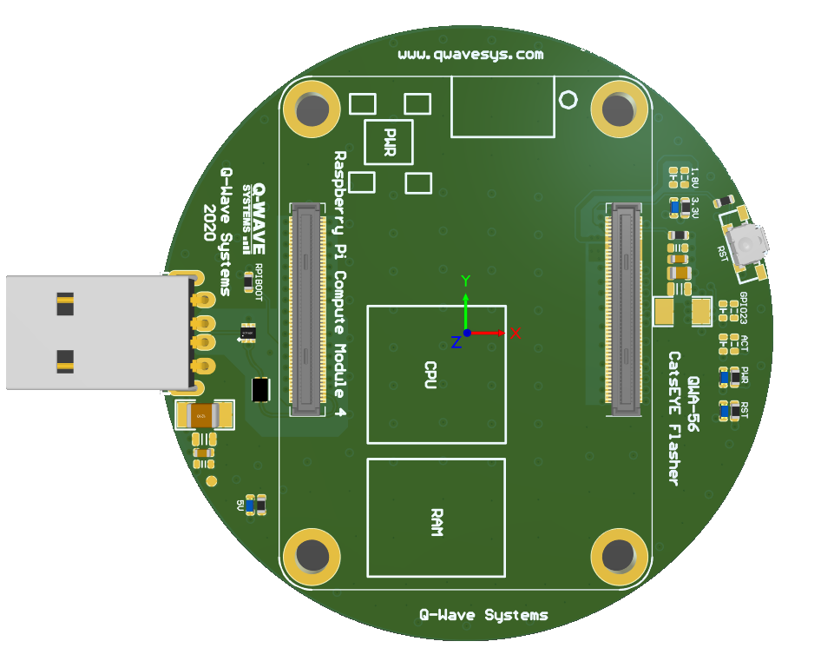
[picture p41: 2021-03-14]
CatsEYE-Flasher-USB Flasher-for-CM4/TOP_wo_CM4.png

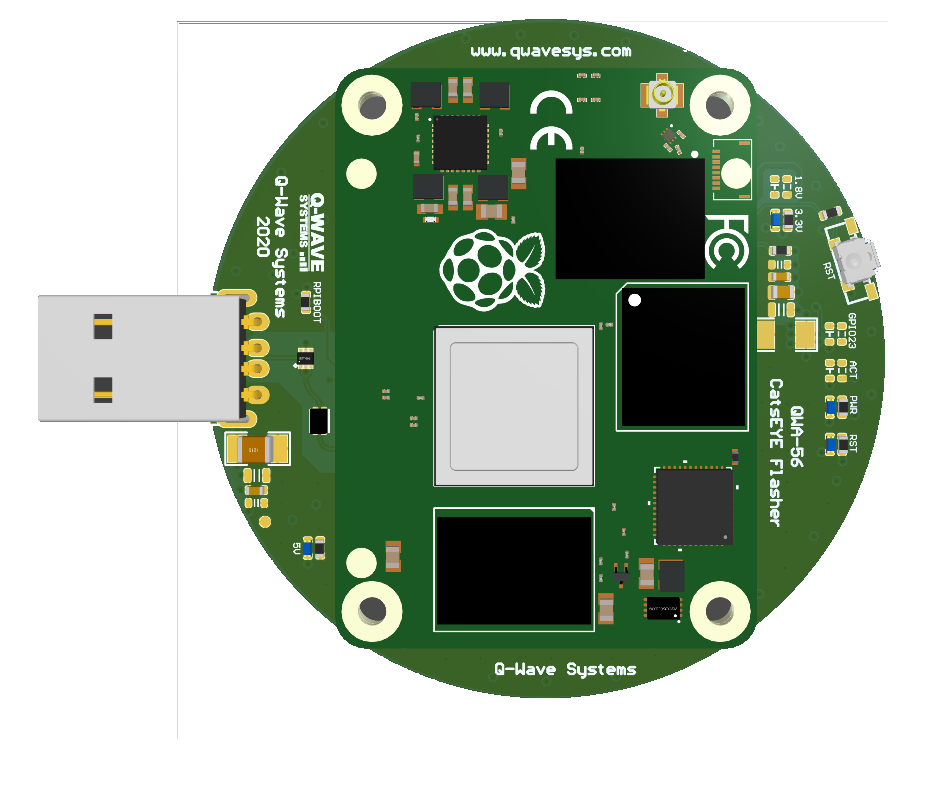
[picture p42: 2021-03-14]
CatsEYE-Flasher-USB Flasher-for-CM4/TOP_with_CM4.png

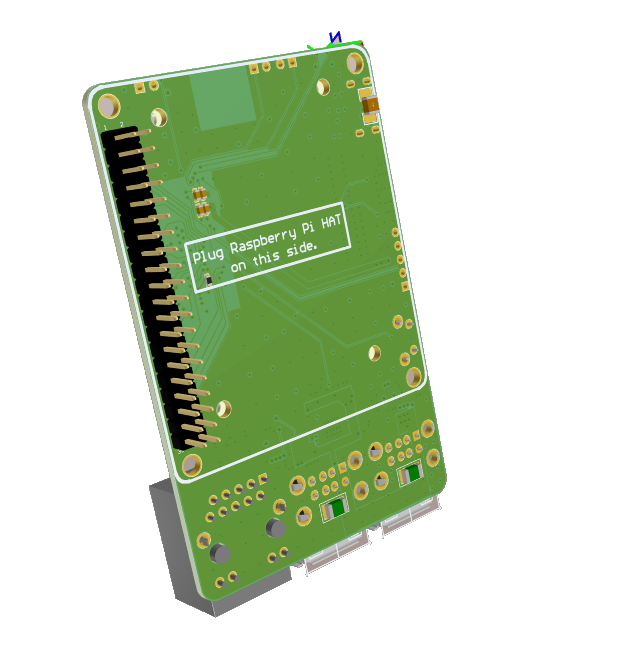
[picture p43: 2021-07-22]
CatsPi-Backflip-Board-using-CM4/CatPi_HAT_Flip_version-G02.png

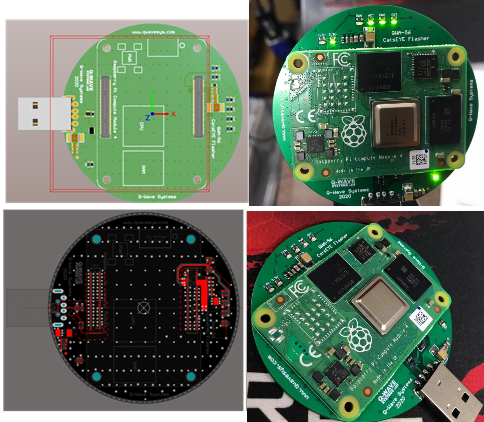
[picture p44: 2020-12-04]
SCH_Snapshot-Picture/CatsEYE-Flasher_03.png

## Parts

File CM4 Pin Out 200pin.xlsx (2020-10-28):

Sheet: RAW
1 | GND | Ground (0V)
2 | GND | Ground (0V)
3 | Ethernet_Pair3_P | Ethernet Pair 3 Positive ( connect to Transformer or MagJack)
4 | Ethernet_Pair1_P | Ethernet Pair 1 Positive ( connect to Transformer or MagJack)
5 | Ethernet_Pair3_N | Ethernet Pair 3 Negative ( connect to Transformer or MagJack)
6 | Ethernet_Pair1_N | Ethernet Pair 1 Negative ( connect to Transformer or MagJack)
7 | GND | Ground (0V)
8 | GND | Ground (0V)
9 | Ethernet_Pair2_N | Ethernet Pair 2 Negative ( connect to Transformer or MagJack)
10 | Ethernet_Pair0_N | Ethernet Pair 0 Negative ( connect to Transformer or MagJack)
11 | Ethernet_Pair2_P | Ethernet Pair 2 Positive ( connect to Transformer or MagJack)
12 | Ethernet_Pair0_P | Ethernet Pair 0 Positive ( connect to Transformer or MagJack)
13 | GND | Ground (0V)
14 | GND | Ground (0V)
15 | Ethernet_nLED3 | Low Active Ethernet Activity indicator ( 3.3V signal) Typically a Green LED is connected to this pin: IOL = 8mA @ VOL< 0.4V
16 | Ethernet_SYNC_IN | IEEE1588 SYNC Input pin ( 1.8V signal : IOL = 8mA @ VOL< 0.4V )
17 | Ethernet_nLED2 | Low Active Ethernet speed indicator ( 3.3V signal) Typically a Yellow LED is connected to this pin. A low State indicates the 1Gbit or 100Mbit Link : IOL = 8mA @ VOL< 0.4V
18 | Ethernet_SYNC_OUT | IEEE1588 SYNC Output pin ( 1.8V signal : IOL = 8mA @ VOL< 0.4V )
19 | Ethernet_nLED1 | Low Active Ethernet speed indicator ( 3.3V signal) Typically a Yellow LED is connected to this pin. A low State indicates the 1Gbit or 10Mbit Link : IOL = 8mA @ VOL< 0.4V
20 | EEPROM_nWP | Leaving floating NB internally pulled up to CM4_3.3V via 100K ( VIL <0.8V) but can be grounded to prevent writing to the on board EEPROM which stores the bootcode
21 | Pi_nLED_Activity | Low Active Pi Activity LED. 20mA Max 5V tolerant ( VOL<0.4V). ( this is the signal that drives the Green LED on the Raspberry Pi 4, Model B )
22 | GND | Ground (0V)
23 | GND | Ground (0V)
24 | GPIO26 | GPIO Typically a 3.3V signal but can be a 1.8V signal by connecting GPIO_Vref to 1.8V
25 | GPIO21 | GPIO Typically a 3.3V signal but can be a 1.8V signal by connecting GPIO_Vref to 1.8V
26 | GPIO19 | GPIO Typically a 3.3V signal but can be a 1.8V signal by connecting GPIO_Vref to 1.8V
27 | GPIO20 | GPIO Typically a 3.3V signal but can be a 1.8V signal by connecting GPIO_Vref to 1.8V
28 | GPIO13 | GPIO Typically a 3.3V signal but can be a 1.8V signal by connecting GPIO_Vref to 1.8V
29 | GPIO16 | GPIO Typically a 3.3V signal but can be a 1.8V signal by connecting GPIO_Vref to 1.8V
30 | GPIO6 | GPIO Typically a 3.3V signal but can be a 1.8V signal by connecting GPIO_Vref to 1.8V
31 | GPIO12 | GPIO Typically a 3.3V signal but can be a 1.8V signal by connecting GPIO_Vref to 1.8V
32 | GND | Ground (0V)
33 | GND | Ground (0V)
34 | GPIO5 | GPIO Typically a 3.3V signal but can be a 1.8V signal by connecting GPIO_Vref to 1.8V
35 | ID_SC | GPIO Typically a 3.3V signal but can be a 1.8V signal by connecting GPIO_Vref to 1.8V
36 | ID_SD | GPIO Typically a 3.3V signal but can be a 1.8V signal by connecting GPIO_Vref to 1.8V
37 | GPIO7 | GPIO Typically a 3.3V signal but can be a 1.8V signal by connecting GPIO_Vref to 1.8V
38 | GPIO11 | GPIO Typically a 3.3V signal but can be a 1.8V signal by connecting GPIO_Vref to 1.8V
39 | GPIO8 | GPIO Typically a 3.3V signal but can be a 1.8V signal by connecting GPIO_Vref to 1.8V
40 | GPIO9 | GPIO Typically a 3.3V signal but can be a 1.8V signal by connecting GPIO_Vref to 1.8V
41 | GPIO25 | GPIO Typically a 3.3V signal but can be a 1.8V signal by connecting GPIO_Vref to 1.8V
42 | GND | Ground (0V)
43 | GND | Ground (0V)
44 | GPIO10 | GPIO Typically a 3.3V signal but can be a 1.8V signal by connecting GPIO_Vref to 1.8V
45 | GPIO24 | GPIO Typically a 3.3V signal but can be a 1.8V signal by connecting GPIO_Vref to 1.8V
46 | GPIO22 | GPIO Typically a 3.3V signal but can be a 1.8V signal by connecting GPIO_Vref to 1.8V
47 | GPIO23 | GPIO Typically a 3.3V signal but can be a 1.8V signal by connecting GPIO_Vref to 1.8V
48 | GPIO27 | GPIO Typically a 3.3V signal but can be a 1.8V signal by connecting GPIO_Vref to 1.8V
49 | GPIO18 | GPIO Typically a 3.3V signal but can be a 1.8V signal by connecting GPIO_Vref to 1.8V
50 | GPIO17 | GPIO Typically a 3.3V signal but can be a 1.8V signal by connecting GPIO_Vref to 1.8V
51 | GPIO15 | GPIO Typically a 3.3V signal but can be a 1.8V signal by connecting GPIO_Vref to 1.8V
52 | GND | Ground (0V)
53 | GND | Ground (0V)
54 | GPIO4 | GPIO Typically a 3.3V signal but can be a 1.8V signal by connecting GPIO_Vref to 1.8V
55 | GPIO14 | GPIO Typically a 3.3V signal but can be a 1.8V signal by connecting GPIO_Vref to 1.8V
56 | GPIO3 | GPIO Typically a 3.3V signal but can be a 1.8V signal by connecting GPIO_Vref to 1.8V. Internal 1.8K pull up to GPIO_Vref
57 | SD_CLK | SDCARD Clock signal (only available on CM4Lite)
58 | GPIO2 | GPIO Typically a 3.3V signal but can be a 1.8V signal by connecting GPIO_Vref to 1.8V. Internal 1.8K pull up to GPIO_Vref
59 | GND | Ground (0V)
60 | GND | Ground (0V)
61 | SD_DAT3 | SDCARD/eMMC Data3 signal (only available on CM4Lite)
62 | SD_CMD | SDCARD/eMMC Command signal (only available on CM4Lite)
63 | SD_DAT0 | SDCARD/eMMC Data0 signal (only available on CM4Lite)
64 | SD_DAT5 | SDCARD/eMMC Data5 signal (only available on CM4Lite)
65 | GND | Ground (0V)
66 | GND | Ground (0V)
67 | SD_DAT1 | SDCARD/eMMC Data1 signal (only available on CM4Lite)
68 | SD_DAT4 | SDCARD/eMMC Data4 signal (only available on CM4Lite)
69 | SD_DAT2 | SDCARD/eMMC Data2 signal (only available on CM4Lite)
70 | SD_DAT7 | SDCARD/eMMC Data7 signal (only available on CM4Lite)
71 | GND | Ground (0V)
72 | SD_DAT6 | SDCARD/eMMC Data6 signal (only available on CM4Lite)
73 | SD_VDD_Override | Force SDCARD/eMMC interface to 1.8V signalling if set to 3.3V, otherwise leave unconnected. Typically only used if external eMMC is connected
74 | GND | Ground (0V)
75 | SD_PWR_ON | Output to Power switch for SDCARD. CM4 sets this pin High (3.3V) to signal that Power to the SDCARD should be turned on. If booting from the SDCARD is required then a pullup should be fitted (only available on CM4Lite)
76 | Reserved | Do not Connect anything to this pin.
77 | +5V (Input) | 4.75V-5.25V Main power input
78 | GPIO_VREF | Must be connected to CM4_3.3V ( pins 84 and 86 ) for 3.3V GPIO or CM4_1.8V ( pins 88 and 90) for 1.8V GPIO. This pin cannot be floating or connected to ground
79 | +5V (Input) | 4.75V-5.25V Main power input
80 | SCL0 | IIC Clock pin ( Raspberry Pi GPIO45) Typically used for Camera and Displays Internal 1.8K pull up to CM4_3.3V
81 | +5V (Input) | 4.75V-5.25V Main power input
82 | SDA0 | IIC Data pin ( Raspberry Pi GPIO44 ) Typically used for Camera and Displays Internal 1.8K pull up to CM4_3.3V
83 | +5V (Input) | 4.75V-5.25V Main power input
84 | CM4_3.3V (Output) | 3.3V +/-2.5% Power Output max 300mA per pin for a total of 600mA. This will be powered down during power off or GLOBAL_EN being set low
85 | +5V (Input) | 4.75V-5.25V Main power input
86 | CM4_3.3V (Output) | 3.3V +/-2.5% Power Output max 300mA per pin for a total of 600mA. This will be powered down during power off or GLOBAL_EN being set low
87 | +5V (Input) | 4.75V-5.25V Main power input
88 | CM4_1.8V (Output) | 1.8V +/-2.5% Power Output max 300mA per pin for a total of 600mA. This will be powered down during power off or GLOBAL_EN being set low
89 | WL_nDisable | Can be left floating if driven low the wireless interface will be disabled. Internal pulled up via 1.8K to CM4_3.3V
90 | CM4_1.8V (Output) | 1.8V +/-2.5% Power Output max 300mA per pin for a total of 600mA. This will be powered down during power off or GLOBAL_EN being set low
91 | BT_nDisable | Can be left floating if driven low the Bluetooth interface will be disabled. Internal pulled up via 1.8K to CM4_3.3V
92 | RUN_PG | Bidirectional pin. Can be driven low ( via a 220R resistor) to Reset the CM4 CPU. As an Output a high signals Power Good and CPU running. Internally pulled up to +3.3V via 10K
93 | nRPIBOOT | A low on this pin force booting from an RPI server ( e.g PC or a Raspberry Pi) if not used leave floating. Internally pulled via 10K to +3.3V
94 | AnalogIP1 | Analogue input of the MAX7704. Typically connected to CC pin of Type C power connector
95 | PI_LED_nPWR | Low active Output to drive Power On LED. This signal needs to be buffered.
96 | AnalogIP0 | Analogue input of the MAX7704. Typically connected to CC pin of Type C power connector
97 | Camera_GPIO | Typically used to Shutdown the camera to reduce power. Reassigning this pin to another function isn’t recommended. CM4_3.3V signalling
98 | GND | Ground (0V)
99 | GLOBAL_EN | Input. Drive low to power off CM4. Internally pulled up with a 100K to +5V
100 | nEXTRST | Output Driven low during reset Driven high (CM4_3.3V) once CM4 CPU has started to boot
101 | USB_OTG_ID | Input ( 3.3V signal ) USB OTG Pin. Internal pulled up. When grounded the CM4 becomes a USB host but the correct OS driver also needs to be used
102 | PCIe_CLK_nREQ | Input ( 3.3V signal) PCIe Clock request pin (low to request PCI clock). Internal pulled up
103 | USB_N | USB D-
104 | Reserved | Do not Connect anything to this pin.
105 | USB_P | USB D+
106 | Reserved | Do not Connect anything to this pin.
107 | GND | Ground (0V)
108 | GND | Ground (0V)
109 | PCIe_nRST | Output (+3.3V signal) PCIe Reset Low active
110 | PCIe_CLK_P | PCIe Clock Out Positive (100MHz) NB AC coupling Capacitor Included on CM4
111 | VDAC_COMP | Video DAC output (TV OUT)
112 | PCIe_CLK_N | PCIe Clock Out Negative (100MHz) NB AC coupling Capacitor Included on CM4
113 | GND | Ground (0V)
114 | GND | Ground (0V)
115 | CAM1_D0_N | Input Camera1 D0 Negative
116 | PCIe_RX_P | Input PCIe GEN 2 RX Positive NB External AC coupling Capacitor required
117 | CAM1_D0_P | Input Camera1 D0 Positive
118 | PCIe_RX_N | Input PCIe GEN 2 RX Negative NB External AC coupling Capacitor required
119 | GND | Ground (0V)
120 | GND | Ground (0V)
121 | CAM1_D1_N | Input Camera1 D1 Negative
122 | PCIe_TX_P | Output PCIe GEN 2 TX Positive NB AC coupling Capacitor Included on CM4
123 | CAM1_D1_P | Input Camera1 D1 Positive
124 | PCIe_TX_N | Output PCIe GEN 2 TX Positive NB AC coupling Capacitor Included on CM4
125 | GND | Ground (0V)
126 | GND | Ground (0V)
127 | CAM1_C_N | Input Camera1 Clock Negative
128 | CAM0_D0_N | Input Camera0 D0 Negative
129 | CAM1_C_P | Input Camera1 Clock Positive
130 | CAM0_D0_P | Input Camera0 D0 Positive
131 | GND | Ground (0V)
132 | GND | Ground (0V)
133 | CAM1_D2_N | Input Camera1 D2 Negative
134 | CAM0_D1_N | Input Camera0 D1 Negative
135 | CAM1_D2_P | Input Camera1 D2 Positive
136 | CAM0_D1_P | Input Camera0 D1 Positive
137 | GND | Ground (0V)
138 | GND | Ground (0V)
139 | CAM1_D3_N | Input Camera1 D3 Negative
140 | CAM0_C_N | Input Camera0 Clock Negative
141 | CAM1_D3_P | Input Camera1 D3 Positive
142 | CAM0_C_P | Input Camera0 Clock Positive
143 | HDMI1_HOTPLUG | Input HDMI1 Hotplug Internally pulled down with a 100K. 5V tolerant. (It can be connected directly to a HDMI connector a small amount of ESD protection is provided on the CM4 by an on board HDMI05-CL02F3)
144 | GND | Ground (0V)
145 | HDMI1_SDA | Bidir HDMI1 SDA Internally pulled up with a 1.8K. 5V tolerant. (It can be connected directly to a HDMI connector a small amount of ESD protection is provided on the CM4 by an on board HDMI05-CL02F3)
146 | HDMI1_TX2_P | Output HDMI1 TX2 Positive
147 | HDMI1_SCL | Input HDMI1 SCL Internally pulled up with a 1.8K. 5V tolerant. (It can be connected directly to a HDMI connector a small amount of ESD protection is provided on the CM4 by an on board HDMI05-CL02F3)
148 | HDMI1_TX2_N | Output HDMI1 TX2 Negative
149 | HDMI1_CEC | Input HDMI1 CEC Internally pulled up with a 27K. 5V tolerant. (It can be connected directly to a HDMI connector a small amount of ESD protection is provided on the CM4 by an on board HDMI05-CL02F3)
150 | GND | Ground (0V)
151 | HDMI0_CEC | Input HDMI0 CEC Internally pulled up with a 27K. 5V tolerant (It can be connected directly to a HDMI connector a small amount of ESD protection is provided on the CM4 by an on board HDMI05-CL02F3)
152 | HDMI1_TX1_P | Output HDMI1 TX1 Positive
153 | HDMI0_HOTPLUG | Input HDMI0 Hotplug Internally pulled down 100K. 5V tolerant. (It can be connected directly to a HDMI connector a small amount of ESD protection is provided on the CM4 by an on board HDMI05-CL02F3)
154 | HDMI1_TX1_N | Output HDMI1 TX1 Negative
155 | GND | Ground (0V)
156 | GND | Ground (0V)
157 | DSI0_D0_N | Output Display0 D0 Negative
158 | HDMI1_TX0_P | Output HDMI1 TX0 Positive
159 | DSI0_D0_P | Output Display0 D0 Positive
160 | HDMI1_TX0_N | Output HDMI1 TX0 Negative
161 | GND | Ground (0V)
162 | GND | Ground (0V)
163 | DSI0_D1_N | Output Display0 D1 Negative
164 | HDMI1_CLK_P | Output HDMI1 Clock Positive
165 | DSI0_D1_P | Output Display0 D1 Positive
166 | HDMI1_CLK_N | Output HDMI1 Clock Negative
167 | GND | Ground (0V)
168 | GND | Ground (0V)
169 | DSI0_C_N | Output Display0 Clock Negative
170 | HDMI0_TX2_P | Output HDMI0 TX2 Positive
171 | DSI0_C_P | Output Display0 Clock Positive
172 | HDMI0_TX2_N | Output HDMI0 TX2 Negative
173 | GND | Ground (0V)
174 | GND | Ground (0V)
175 | DSI1_D0_N | Output Display1 D0 Negative
176 | HDMI0_TX1_P | Output HDMI0 TX1 Positive
177 | DSI1_D0_P | Output Display1 D0 Positive
178 | HDMI0_TX1_N | Output HDMI0 TX1 Negative
179 | GND | Ground (0V)
180 | GND | Ground (0V)
181 | DSI1_D1_N | Output Display1 D1 Negative
182 | HDMI0_TX0_P | Output HDMI0 TX0 Positive
183 | DSI1_D1_P | Output Display1 D1 Positive
184 | HDMI0_TX0_N | Output HDMI0 TX0 Negative
185 | GND | Ground (0V)
186 | GND | Ground (0V)
187 | DSI1_C_N | Output Display1 Clock Negative
188 | HDMI0_CLK_P | Output HDMI0 Clock Positive
189 | DSI1_C_P | Output Display1 Clock Positive
190 | HDMI0_CLK_N | Output HDMI0 Clock Negative
191 | GND | Ground (0V)
192 | GND | Ground (0V)
193 | DSI1_D2_N | Output Display1 D2 Negative
194 | DSI1_D3_N | Output Display1 D3 Negative
195 | DSI1_D2_P | Output Display1 D2 Positive
196 | DSI1_D3_P | Output Display1 D3 Positive
197 | GND | Ground (0V)
198 | GND | Ground (0V)
199 | HDMI0_SDA | Bidir HDMI0 SDA Internally pulled up with a 1.8K. 5V tolerant. (It can be connected directly to a HDMI connector a small amount of ESD protection is provided on the CM4 by an on board HDMI05-CL02F3)
200 | HDMI0_SCL | Bidir HDMI0 SCL Internally pulled up with a 1.8K. 5V tolerant. (It can be connected directly to a HDMI connector a small amount of ESD protection is provided on the CM4 by an on board HDMI05-CL02F3)

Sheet: Ref ALL
_Designator | _Display Name | _Description | _Electrical Type
1 | GND | Ground (0V) | Power
2 | GND | Ground (0V) | Power
3 | Ethernet_Pair3_P | Ethernet Pair 3 Positive ( connect to Transformer or MagJack) | Passive
4 | Ethernet_Pair1_P | Ethernet Pair 1 Positive ( connect to Transformer or MagJack) | Passive
5 | Ethernet_Pair3_N | Ethernet Pair 3 Negative ( connect to Transformer or MagJack) | Passive
6 | Ethernet_Pair1_N | Ethernet Pair 1 Negative ( connect to Transformer or MagJack) | Passive
7 | GND | Ground (0V) | Power
8 | GND | Ground (0V) | Power
9 | Ethernet_Pair2_N | Ethernet Pair 2 Negative ( connect to Transformer or MagJack) | Passive
10 | Ethernet_Pair0_N | Ethernet Pair 0 Negative ( connect to Transformer or MagJack) | Passive
11 | Ethernet_Pair2_P | Ethernet Pair 2 Positive ( connect to Transformer or MagJack) | Passive
12 | Ethernet_Pair0_P | Ethernet Pair 0 Positive ( connect to Transformer or MagJack) | Passive
13 | GND | Ground (0V) | Power
14 | GND | Ground (0V) | Power
15 | Ethernet_nLED3 | Low Active Ethernet Activity indicator ( 3.3V signal) Typically a Green LED is connected to this pin: IOL = 8mA @ VOL< 0.4V | Output
16 | Ethernet_SYNC_IN | IEEE1588 SYNC Input pin ( 1.8V signal : IOL = 8mA @ VOL< 0.4V ) | Input
17 | Ethernet_nLED2 | Low Active Ethernet speed indicator ( 3.3V signal) Typically a Yellow LED is connected to this pin. A low State indicates the 1Gbit or 100Mbit Link : IOL = 8mA @ VOL< 0.4V | Output
18 | Ethernet_SYNC_OUT | IEEE1588 SYNC Output pin ( 1.8V signal : IOL = 8mA @ VOL< 0.4V ) | Input
19 | Ethernet_nLED1 | Low Active Ethernet speed indicator ( 3.3V signal) Typically a Yellow LED is connected to this pin. A low State indicates the 1Gbit or 10Mbit Link : IOL = 8mA @ VOL< 0.4V | Output
20 | EEPROM_nWP | Leaving floating NB internally pulled up to CM4_3.3V via 100K ( VIL <0.8V) but can be grounded to prevent writing to the on board EEPROM which stores the bootcode | Passive
21 | Pi_nLED_Activity | Low Active Pi Activity LED. 20mA Max 5V tolerant ( VOL<0.4V). ( this is the signal that drives the Green LED on the Raspberry Pi 4, Model B ) | Open Collector
22 | GND | Ground (0V) | Power
23 | GND | Ground (0V) | Power
24 | GPIO26 | GPIO Typically a 3.3V signal but can be a 1.8V signal by connecting GPIO_Vref to 1.8V | Passive
25 | GPIO21 | GPIO Typically a 3.3V signal but can be a 1.8V signal by connecting GPIO_Vref to 1.8V | Passive
26 | GPIO19 | GPIO Typically a 3.3V signal but can be a 1.8V signal by connecting GPIO_Vref to 1.8V | Passive
27 | GPIO20 | GPIO Typically a 3.3V signal but can be a 1.8V signal by connecting GPIO_Vref to 1.8V | Passive
28 | GPIO13 | GPIO Typically a 3.3V signal but can be a 1.8V signal by connecting GPIO_Vref to 1.8V | Passive
29 | GPIO16 | GPIO Typically a 3.3V signal but can be a 1.8V signal by connecting GPIO_Vref to 1.8V | Passive
30 | GPIO6 | GPIO Typically a 3.3V signal but can be a 1.8V signal by connecting GPIO_Vref to 1.8V | Passive
31 | GPIO12 | GPIO Typically a 3.3V signal but can be a 1.8V signal by connecting GPIO_Vref to 1.8V | Passive
32 | GND | Ground (0V) | Power
33 | GND | Ground (0V) | Power
34 | GPIO5 | GPIO Typically a 3.3V signal but can be a 1.8V signal by connecting GPIO_Vref to 1.8V | Passive
35 | ID_SC | GPIO Typically a 3.3V signal but can be a 1.8V signal by connecting GPIO_Vref to 1.8V | Passive
36 | ID_SD | GPIO Typically a 3.3V signal but can be a 1.8V signal by connecting GPIO_Vref to 1.8V | Passive
37 | GPIO7 | GPIO Typically a 3.3V signal but can be a 1.8V signal by connecting GPIO_Vref to 1.8V | Passive
38 | GPIO11 | GPIO Typically a 3.3V signal but can be a 1.8V signal by connecting GPIO_Vref to 1.8V | Passive
39 | GPIO8 | GPIO Typically a 3.3V signal but can be a 1.8V signal by connecting GPIO_Vref to 1.8V | Passive
40 | GPIO9 | GPIO Typically a 3.3V signal but can be a 1.8V signal by connecting GPIO_Vref to 1.8V | Passive
41 | GPIO25 | GPIO Typically a 3.3V signal but can be a 1.8V signal by connecting GPIO_Vref to 1.8V | Passive
42 | GND | Ground (0V) | Power
43 | GND | Ground (0V) | Power
44 | GPIO10 | GPIO Typically a 3.3V signal but can be a 1.8V signal by connecting GPIO_Vref to 1.8V | Passive
45 | GPIO24 | GPIO Typically a 3.3V signal but can be a 1.8V signal by connecting GPIO_Vref to 1.8V | Passive
46 | GPIO22 | GPIO Typically a 3.3V signal but can be a 1.8V signal by connecting GPIO_Vref to 1.8V | Passive
47 | GPIO23 | GPIO Typically a 3.3V signal but can be a 1.8V signal by connecting GPIO_Vref to 1.8V | Passive
48 | GPIO27 | GPIO Typically a 3.3V signal but can be a 1.8V signal by connecting GPIO_Vref to 1.8V | Passive
49 | GPIO18 | GPIO Typically a 3.3V signal but can be a 1.8V signal by connecting GPIO_Vref to 1.8V | Passive
50 | GPIO17 | GPIO Typically a 3.3V signal but can be a 1.8V signal by connecting GPIO_Vref to 1.8V | Passive
51 | GPIO15 | GPIO Typically a 3.3V signal but can be a 1.8V signal by connecting GPIO_Vref to 1.8V | Passive
52 | GND | Ground (0V) | Power
53 | GND | Ground (0V) | Power
54 | GPIO4 | GPIO Typically a 3.3V signal but can be a 1.8V signal by connecting GPIO_Vref to 1.8V | Passive
55 | GPIO14 | GPIO Typically a 3.3V signal but can be a 1.8V signal by connecting GPIO_Vref to 1.8V | Passive
56 | GPIO3 | GPIO Typically a 3.3V signal but can be a 1.8V signal by connecting GPIO_Vref to 1.8V. Internal 1.8K pull up to GPIO_Vref | Passive
57 | SD_CLK | SDCARD Clock signal (only available on CM4Lite) | Passive
58 | GPIO2 | GPIO Typically a 3.3V signal but can be a 1.8V signal by connecting GPIO_Vref to 1.8V. Internal 1.8K pull up to GPIO_Vref | Passive
59 | GND | Ground (0V) | Power
60 | GND | Ground (0V) | Power
61 | SD_DAT3 | SDCARD/eMMC Data3 signal (only available on CM4Lite) | Passive
62 | SD_CMD | SDCARD/eMMC Command signal (only available on CM4Lite) | Passive
63 | SD_DAT0 | SDCARD/eMMC Data0 signal (only available on CM4Lite) | Passive
64 | SD_DAT5 | SDCARD/eMMC Data5 signal (only available on CM4Lite) | Passive
65 | GND | Ground (0V) | Power
66 | GND | Ground (0V) | Power
67 | SD_DAT1 | SDCARD/eMMC Data1 signal (only available on CM4Lite) | Passive
68 | SD_DAT4 | SDCARD/eMMC Data4 signal (only available on CM4Lite) | Passive
69 | SD_DAT2 | SDCARD/eMMC Data2 signal (only available on CM4Lite) | Passive
70 | SD_DAT7 | SDCARD/eMMC Data7 signal (only available on CM4Lite) | Passive
71 | GND | Ground (0V) | Power
72 | SD_DAT6 | SDCARD/eMMC Data6 signal (only available on CM4Lite) | Passive
73 | SD_VDD_Override | Force SDCARD/eMMC interface to 1.8V signalling if set to 3.3V, otherwise leave unconnected. Typically only used if external eMMC is connected | Input
74 | GND | Ground (0V) | Power
75 | SD_PWR_ON | Output to Power switch for SDCARD. CM4 sets this pin High (3.3V) to signal that Power to the SDCARD should be turned on. If booting from the SDCARD is required then a pullup should be fitted (only available on CM4Lite) | Output
76 | Reserved | Do not Connect anything to this pin. | Passive
77 | +5V (Input) | 4.75V-5.25V Main power input | Power
78 | GPIO_VREF | Must be connected to CM4_3.3V ( pins 84 and 86 ) for 3.3V GPIO or CM4_1.8V ( pins 88 and 90) for 1.8V GPIO. This pin cannot be floating or connected to ground | Power
79 | +5V (Input) | 4.75V-5.25V Main power input | Power
80 | I2C_SCL0 | IIC Clock pin ( Raspberry Pi GPIO45) Typically used for Camera and Displays Internal 1.8K pull up to CM4_3.3V | Passive
81 | +5V (Input) | 4.75V-5.25V Main power input | Power
82 | I2C_SDA0 | IIC Data pin ( Raspberry Pi GPIO44 ) Typically used for Camera and Displays Internal 1.8K pull up to CM4_3.3V | Passive
83 | +5V (Input) | 4.75V-5.25V Main power input | Power
84 | CM4_3.3V (Output) | 3.3V +/-2.5% Power Output max 300mA per pin for a total of 600mA. This will be powered down during power off or GLOBAL_EN being set low | Power
85 | +5V (Input) | 4.75V-5.25V Main power input | Power
86 | CM4_3.3V (Output) | 3.3V +/-2.5% Power Output max 300mA per pin for a total of 600mA. This will be powered down during power off or GLOBAL_EN being set low | Power
87 | +5V (Input) | 4.75V-5.25V Main power input | Power
88 | CM4_1.8V (Output) | 1.8V +/-2.5% Power Output max 300mA per pin for a total of 600mA. This will be powered down during power off or GLOBAL_EN being set low | Power
89 | WL_nDisable | Can be left floating if driven low the wireless interface will be disabled. Internal pulled up via 1.8K to CM4_3.3V | Input
90 | CM4_1.8V (Output) | 1.8V +/-2.5% Power Output max 300mA per pin for a total of 600mA. This will be powered down during power off or GLOBAL_EN being set low | Power
91 | BT_nDisable | Can be left floating if driven low the Bluetooth interface will be disabled. Internal pulled up via 1.8K to CM4_3.3V | Input
92 | RUN_PG | Bidirectional pin. Can be driven low ( via a 220R resistor) to Reset the CM4 CPU. As an Output a high signals Power Good and CPU running. Internally pulled up to +3.3V via 10K | Passive
93 | nRPIBOOT | A low on this pin force booting from an RPI server ( e.g PC or a Raspberry Pi) if not used leave floating. Internally pulled via 10K to +3.3V | Input
94 | AnalogIP1 | Analogue input of the MAX7704. Typically connected to CC pin of Type C power connector | Passive
95 | PI_LED_nPWR | Low active Output to drive Power On LED. This signal needs to be buffered. | Output
96 | AnalogIP0 | Analogue input of the MAX7704. Typically connected to CC pin of Type C power connector | Passive
97 | Camera_GPIO | Typically used to Shutdown the camera to reduce power. Reassigning this pin to another function isn’t recommended. CM4_3.3V signalling | Passive
98 | GND | Ground (0V) | Power
99 | GLOBAL_EN | Input. Drive low to power off CM4. Internally pulled up with a 100K to +5V | Input
100 | nEXTRST | Output Driven low during reset Driven high (CM4_3.3V) once CM4 CPU has started to boot | Output
101 | USB_OTG_ID | Input ( 3.3V signal ) USB OTG Pin. Internal pulled up. When grounded the CM4 becomes a USB host but the correct OS driver also needs to be used | Input
102 | PCIe_CLK_nREQ | Input ( 3.3V signal) PCIe Clock request pin (low to request PCI clock). Internal pulled up | Input
103 | USB_N | USB D- | Passive
104 | Reserved | Do not Connect anything to this pin. | Passive
105 | USB_P | USB D+ | Passive
106 | Reserved | Do not Connect anything to this pin. | Passive
107 | GND | Ground (0V) | Power
108 | GND | Ground (0V) | Power
109 | PCIe_nRST | Output (+3.3V signal) PCIe Reset Low active | Output
110 | PCIe_CLK_P | PCIe Clock Out Positive (100MHz) NB AC coupling Capacitor Included on CM4 | Output
111 | VDAC_COMP | Video DAC output (TV OUT) | Passive
112 | PCIe_CLK_N | PCIe Clock Out Negative (100MHz) NB AC coupling Capacitor Included on CM4 | Output
113 | GND | Ground (0V) | Power
114 | GND | Ground (0V) | Power
115 | CAM1_D0_N | Input Camera1 D0 Negative | Input
116 | PCIe_RX_P | Input PCIe GEN 2 RX Positive NB External AC coupling Capacitor required | Input
117 | CAM1_D0_P | Input Camera1 D0 Positive | Input
118 | PCIe_RX_N | Input PCIe GEN 2 RX Negative NB External AC coupling Capacitor required | Input
119 | GND | Ground (0V) | Power
120 | GND | Ground (0V) | Power
121 | CAM1_D1_N | Input Camera1 D1 Negative | Input
122 | PCIe_TX_P | Output PCIe GEN 2 TX Positive NB AC coupling Capacitor Included on CM4 | Output
123 | CAM1_D1_P | Input Camera1 D1 Positive | Input
124 | PCIe_TX_N | Output PCIe GEN 2 TX Positive NB AC coupling Capacitor Included on CM4 | Output
125 | GND | Ground (0V) | Power
126 | GND | Ground (0V) | Power
127 | CAM1_C_N | Input Camera1 Clock Negative | Input
128 | CAM0_D0_N | Input Camera0 D0 Negative | Input
129 | CAM1_C_P | Input Camera1 Clock Positive | Input
130 | CAM0_D0_P | Input Camera0 D0 Positive | Input
131 | GND | Ground (0V) | Power
132 | GND | Ground (0V) | Power
133 | CAM1_D2_N | Input Camera1 D2 Negative | Input
134 | CAM0_D1_N | Input Camera0 D1 Negative | Input
135 | CAM1_D2_P | Input Camera1 D2 Positive | Input
136 | CAM0_D1_P | Input Camera0 D1 Positive | Input
137 | GND | Ground (0V) | Power
138 | GND | Ground (0V) | Power
139 | CAM1_D3_N | Input Camera1 D3 Negative | Input
140 | CAM0_C_N | Input Camera0 Clock Negative | Input
141 | CAM1_D3_P | Input Camera1 D3 Positive | Input
142 | CAM0_C_P | Input Camera0 Clock Positive | Input
143 | HDMI1_HOTPLUG | Input HDMI1 Hotplug Internally pulled down with a 100K. 5V tolerant. (It can be connected directly to a HDMI connector a small amount of ESD protection is provided on the CM4 by an on board HDMI05-CL02F3) | Input
144 | GND | Ground (0V) | Power
145 | HDMI1_SDA | Bidir HDMI1 SDA Internally pulled up with a 1.8K. 5V tolerant. (It can be connected directly to a HDMI connector a small amount of ESD protection is provided on the CM4 by an on board HDMI05-CL02F3) | Bidirectional
146 | HDMI1_TX2_P | Output HDMI1 TX2 Positive | Output
147 | HDMI1_SCL | Input HDMI1 SCL Internally pulled up with a 1.8K. 5V tolerant. (It can be connected directly to a HDMI connector a small amount of ESD protection is provided on the CM4 by an on board HDMI05-CL02F3) | Open Collector
148 | HDMI1_TX2_N | Output HDMI1 TX2 Negative | Output
149 | HDMI1_CEC | Input HDMI1 CEC Internally pulled up with a 27K. 5V tolerant. (It can be connected directly to a HDMI connector a small amount of ESD protection is provided on the CM4 by an on board HDMI05-CL02F3) | Open Collector
150 | GND | Ground (0V) | Power
151 | HDMI0_CEC | Input HDMI0 CEC Internally pulled up with a 27K. 5V tolerant (It can be connected directly to a HDMI connector a small amount of ESD protection is provided on the CM4 by an on board HDMI05-CL02F3) | Open Collector
152 | HDMI1_TX1_P | Output HDMI1 TX1 Positive | Output
153 | HDMI0_HOTPLUG | Input HDMI0 Hotplug Internally pulled down 100K. 5V tolerant. (It can be connected directly to a HDMI connector a small amount of ESD protection is provided on the CM4 by an on board HDMI05-CL02F3) | Output
154 | HDMI1_TX1_N | Output HDMI1 TX1 Negative | Output
155 | GND | Ground (0V) | Power
156 | GND | Ground (0V) | Power
157 | DSI0_D0_N | Output Display0 D0 Negative | Output
158 | HDMI1_TX0_P | Output HDMI1 TX0 Positive | Output
159 | DSI0_D0_P | Output Display0 D0 Positive | Output
160 | HDMI1_TX0_N | Output HDMI1 TX0 Negative | Output
161 | GND | Ground (0V) | Power
162 | GND | Ground (0V) | Power
163 | DSI0_D1_N | Output Display0 D1 Negative | Output
164 | HDMI1_CLK_P | Output HDMI1 Clock Positive | Output
165 | DSI0_D1_P | Output Display0 D1 Positive | Output
166 | HDMI1_CLK_N | Output HDMI1 Clock Negative | Output
167 | GND | Ground (0V) | Power
168 | GND | Ground (0V) | Power
169 | DSI0_C_N | Output Display0 Clock Negative | Output
170 | HDMI0_TX2_P | Output HDMI0 TX2 Positive | Output
171 | DSI0_C_P | Output Display0 Clock Positive | Output
172 | HDMI0_TX2_N | Output HDMI0 TX2 Negative | Output
173 | GND | Ground (0V) | Power
174 | GND | Ground (0V) | Power
175 | DSI1_D0_N | Output Display1 D0 Negative | Output
176 | HDMI0_TX1_P | Output HDMI0 TX1 Positive | Output
177 | DSI1_D0_P | Output Display1 D0 Positive | Output
178 | HDMI0_TX1_N | Output HDMI0 TX1 Negative | Output
179 | GND | Ground (0V) | Power
180 | GND | Ground (0V) | Power
181 | DSI1_D1_N | Output Display1 D1 Negative | Output
182 | HDMI0_TX0_P | Output HDMI0 TX0 Positive | Output
183 | DSI1_D1_P | Output Display1 D1 Positive | Output
184 | HDMI0_TX0_N | Output HDMI0 TX0 Negative | Output
185 | GND | Ground (0V) | Power
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

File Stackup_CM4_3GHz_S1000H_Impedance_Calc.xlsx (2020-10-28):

Impedances | 3GHz
# | Target (Ω) | Type | Trace layer | Calculated (Ω) | Trace width (mm) | Gap (mm) | Reference layers
1 | 50 | Single | Bottom | 49.9911 | 0.33291 |  | GND2
2 | 50 | Single | Signal | 49.995 | 0.27525 |  | GND2
3 | 50 | Single | Top | 49.9956 | 0.33 |  | GND1
10 | 90 | Diff pair | Bottom | 89.9901 | 0.23497 | 0.2032 | GND2
11 | 90 | Diff pair | Signal | 89.9818 | 0.17046 | 0.2794 | GND2
12 | 90 | Diff pair | Top | 89.9901 | 0.23497 | 0.2032 | GND1
13 | 100 | Diff pair | Bottom | 100.0085 | 0.17114 | 0.2032 | GND2
14 | 100 | Diff pair | Signal | 100.0309 | 0.16246 | 0.4064 | GND2
15 | 100 | Diff pair | Top | 100.0085 | 0.17114 | 0.2032 | GND1

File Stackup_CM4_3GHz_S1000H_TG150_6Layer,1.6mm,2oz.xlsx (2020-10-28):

Board Layer Stack
Number | Name | Type | Manufacturer | Material | Process | Thickness (mm) | Weight (oz) | Dk | Df | Orientation | Copper Orientation | Pullback distance (mm) | Description | Color | Constructions | Solid (%) | Resin (%) | Frequency (GHz) | GlassTransTemp (°C)
 | Top Overlay | Overlay
 | Top Solder | Solder Mask | Altium Designer | SM-001 |  | 0.0254 |  | 4 | 0.03 |  |  |  | Solder Mask | #FF008000 |  | 1 |  | 1 | 125
 | Top Surface Finish | Surface Finish |  | Nickel | Gold | ENIG | 0.004 |  |  |  |  |  |  |  | #FFFFC400
1 | Top | Signal | Altium Designer | CF-005 | ED | 0.07 | 2 |  |  | Top | Above |  | Copper Foil
 | 7628_PP1 | Prepreg | Shengyi | PP-S1000H |  | 0.215 |  | 4.58 | 0.016 |  |  |  |  |  | 7628 |  | 50 | 3 | 160
2 | GND1 | Plane | Altium Designer | CF-005 | ED | 0.07 | 2 |  |  |  | Below | 0.508 | Copper Foil
 | 2x2116_Core1 | Core | Shengyi | Core-S1000H |  | 0.24 |  | 4.48 | 0.017 |  |  |  |  |  | 2x2116 |  | 54 | 3 | 160
3 | Power | Signal | Altium Designer | CF-005 | ED | 0.07 | 2 |  |  | Top | Below |  | Copper Foil
 | 7628_PP2 | Prepreg | Shengyi | PP-S1000H |  | 0.215 |  | 4.58 | 0.016 |  |  |  |  |  | 7628 |  | 50 | 3 | 160
4 | Signal | Signal | Altium Designer | CF-005 | ED | 0.07 | 2 |  |  | Top | Above |  | Copper Foil
 | 2x2116_Core2 | Core | Shengyi | Core-S1000H |  | 0.24 |  | 4.48 | 0.017 |  |  |  |  |  | 2x2116 |  | 54 | 3 | 160
5 | GND2 | Plane | Altium Designer | CF-005 | ED | 0.07 | 2 |  |  |  | Above | 0.508 | Copper Foil
 | 7628_PP3 | Prepreg | Shengyi | PP-S1000H |  | 0.215 |  | 4.58 | 0.016 |  |  |  |  |  | 7628 |  | 50 | 3 | 160
6 | Bottom | Signal | Altium Designer | CF-005 | ED | 0.07 | 2 |  |  | Bottom | Below |  | Copper Foil
 | Bottom Surface Finish | Surface Finish |  | Nickel | Gold | ENIG | 0.004 |  |  |  |  |  |  |  | #FFFFC400
 | Bottom Solder | Solder Mask | Altium Designer | SM-001 |  | 0.0254 |  | 4 | 0.03 |  |  |  | Solder Mask | #FF008000 |  | 1 |  | 1 | 125
 | Bottom Overlay | Overlay
Impedances
# | Target impedance (Ω) | Type | Trace layer | Calculated impedance (Ω) | Trace width (mm) | Gap (mm) | Reference layers | Stack
1 | 50 | Single | Bottom | 49.9911 | 0.33291 |  | GND2 | Board Layer Stack
2 | 50 | Single | Signal | 49.995 | 0.27525 |  | GND2 | Board Layer Stack
3 | 50 | Single | Top | 49.9956 | 0.33 |  | GND1 | Board Layer Stack
4 | 80 | Diff pair | Bottom | 80.0208 | 0.31918 | 0.2032 | GND2 | Board Layer Stack
5 | 80 | Diff pair | Signal | 80.0004 | 0.18518 | 0.2032 | GND2 | Board Layer Stack
6 | 80 | Diff pair | Top | 80.0208 | 0.31918 | 0.2032 | GND1 | Board Layer Stack
7 | 85 | Diff pair | Bottom | 85.0178 | 0.27369 | 0.2032 | GND2 | Board Layer Stack
8 | 85 | Diff pair | Signal | 85.0067 | 0.16979 | 0.2286 | GND2 | Board Layer Stack
9 | 85 | Diff pair | Top | 85.0178 | 0.27369 | 0.2032 | GND1 | Board Layer Stack
10 | 90 | Diff pair | Bottom | 89.9901 | 0.23497 | 0.2032 | GND2 | Board Layer Stack
11 | 90 | Diff pair | Signal | 89.9818 | 0.17046 | 0.2794 | GND2 | Board Layer Stack
12 | 90 | Diff pair | Top | 89.9901 | 0.23497 | 0.2032 | GND1 | Board Layer Stack
13 | 100 | Diff pair | Bottom | 100.0085 | 0.17114 | 0.2032 | GND2 | Board Layer Stack
14 | 100 | Diff pair | Signal | 100.0309 | 0.16246 | 0.4064 | GND2 | Board Layer Stack
15 | 100 | Diff pair | Top | 100.0085 | 0.17114 | 0.2032 | GND1 | Board Layer Stack
Via types
# | Name | Type | Layers | Stack
1 | Thru 1:6 | Thru | Top-Bottom | Board Layer Stack
No back drills

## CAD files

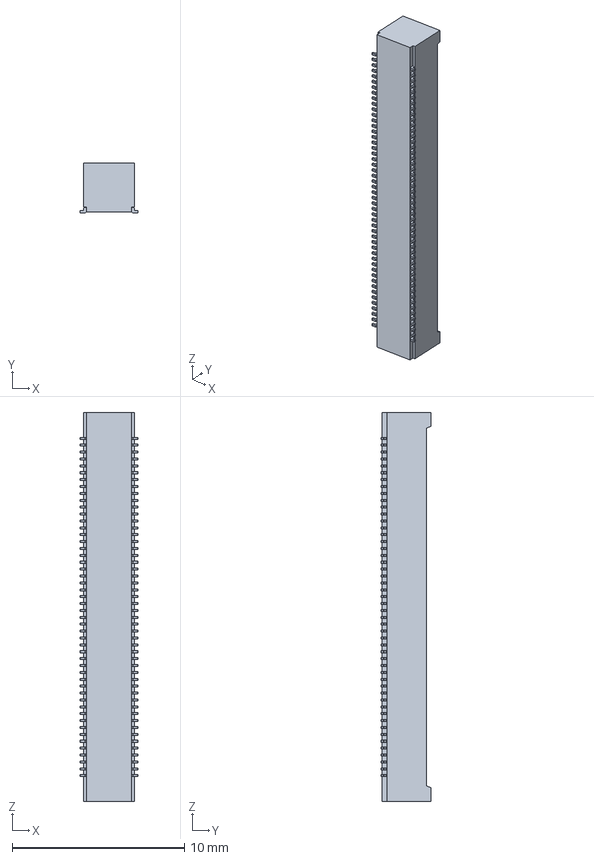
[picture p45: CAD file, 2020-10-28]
DF40HC(3.0)-100DS-0.4V.stp
3.38 x 2.90 x 22.6 mm

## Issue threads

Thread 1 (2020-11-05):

Compute Module 4 as a unique component

estevaofv, 2020-11-05:
;Hello, first of all thanks for sharing!

We made a very similar thing as you importing the compute module 4 to Altium, as one component, but after some thought we find some possible problems:
- How to get the exact reference and coordinates for the 2 connectors that will be used to plug the CM4 to the base board? I'm referring to the receptacle connector (DF40C-100DS-0.4V(51)) how to find and define their individual coordinates since we use two per boards and the reference is in the center of the CM4 as in the picture:

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

- Also is there a way to work with Altium besides to manually insert the DF40C-100DS-0.4V(51) in the BOM, since for each CM4 in the BOM we will need 2 x DF40C-100DS-0.4V(51) connectors?

Do these points make sense? How did you plan to face this situation?
What we are planning to do is to "break" the CM4 in 2 parts associating each half with one DF40C-100DS-0.4V(51) connector, so we will have its exactly center coordinate that will be used in the assembly

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

and the hard part will be to match the exact distance and alignment of the two separate connectors to match the CM4, we will do it based on the footprints imported from KIcad. Do you think this approach makes sense for you?

Thanks in advance and thanks one more time for sharing!

Amornthep-Phunsin, 2020-11-05:
I got your point and thanks for raise this issue up,

1. Base on physical dimension page 4 as this link you can find exectly dimension or got them form STEP file.
[https://datasheets.raspberrypi.org/cm4/cm4-product-brief.pdf](https://datasheets.raspberrypi.org/cm4/cm4-product-brief.pdf)

2.I agreed with you if imported to Altium as single component, it is required to manually edit BOM list to added 2xconnector.
Agreed that your solution should solved this by break to 2 component, the one for Low speed another one for highspeed, I would suggest added one more PCB compont as connector guideline in Mech layer, (*use this only for alignment position of both connectors)

Closed 2020-12-30.

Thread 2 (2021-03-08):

not able to check gpio pins via 'gpio readall' also not able to write in '/dev/ttyS0' using 'picocom /dev/ttyS0' command

pradipmudi, 2021-03-08:
Hi community,
Need help with my **RPI Compute Module 4**
I have WiringPI library installed of version 2.52
My PI firmware is also upto date.

Getting this error while executing the command below :

**$ gpio readall**
_Oops - unable to determine board type... model: 20_

Also not able to write anything '/dev/ttyS0' using 'picocom /dev/ttyS0' command

Here are my configurations from  **/boot/config.txt** and **/boot/cmdline.txt** respectively :
<code>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</code>
<code>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</code>

Please help me identify if I have configured with any wrong configurations or not. I'm able to open the /dev/ttyS0 port but I'm not able to send any commands and get any response for the same.

Closed 2021-03-14.

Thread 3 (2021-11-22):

Pick & Place

WayneManoni, 2021-11-22:
Only 1 pick and place location is generated and component requires 2 connectors.

Amornthep-Phunsin, 2021-12-09:
1. At CM4 Schematic sheet at Property > General > Type > Standard (NO BOM)
2.Add J1,J2 for DF40 connector with dummy footprint place at center of actual connector location.

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

Closed 2021-12-09.

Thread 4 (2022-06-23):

High and low question

ahmadfarisfs, 2022-06-23:
Hi first of all thank for sharing this amazing work! I have question regarding the high and low you mentioned here. What does that mean ? maybe you could add more information on the schematic as well ? Thank you in advance

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

Amornthep-Phunsin, 2022-07-21:
there are default pin state of original RPI GPIO driver.

Closed 2022-07-21.

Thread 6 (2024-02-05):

CM4 and conenctors in bom and pnp file

freppac, 2024-02-05:
Hi
Tried the CM4 library for Altium and like it...but nothing ends up in the BOM. Is that possible? and how about the pnp file for the DF40C-100DS-0.4v connectors?

Amornthep-Phunsin, 2025-04-07:
https://github.com/QWaveSystems/QWAVE_Raspberry-Pi-CM4-Altium-Library/issues/3

Closed 2025-04-07.

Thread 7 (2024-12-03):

Connector distance

lasselj, 2024-12-03:
Hello,

Out of curiosity, why are the 100 pin connectors in the footprint 33.92mm apart instead of 34mm? I don't think it's a "real" issue, but why did you do it?

All the best,

Lasse

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

Amornthep-Phunsin, 2024-12-05:
Hi Lasse

Your are right. The connector distance is 33.92mm. This is a mistake it the PCB library. Thanks for pointing out this issue.

Closed 2025-04-07.

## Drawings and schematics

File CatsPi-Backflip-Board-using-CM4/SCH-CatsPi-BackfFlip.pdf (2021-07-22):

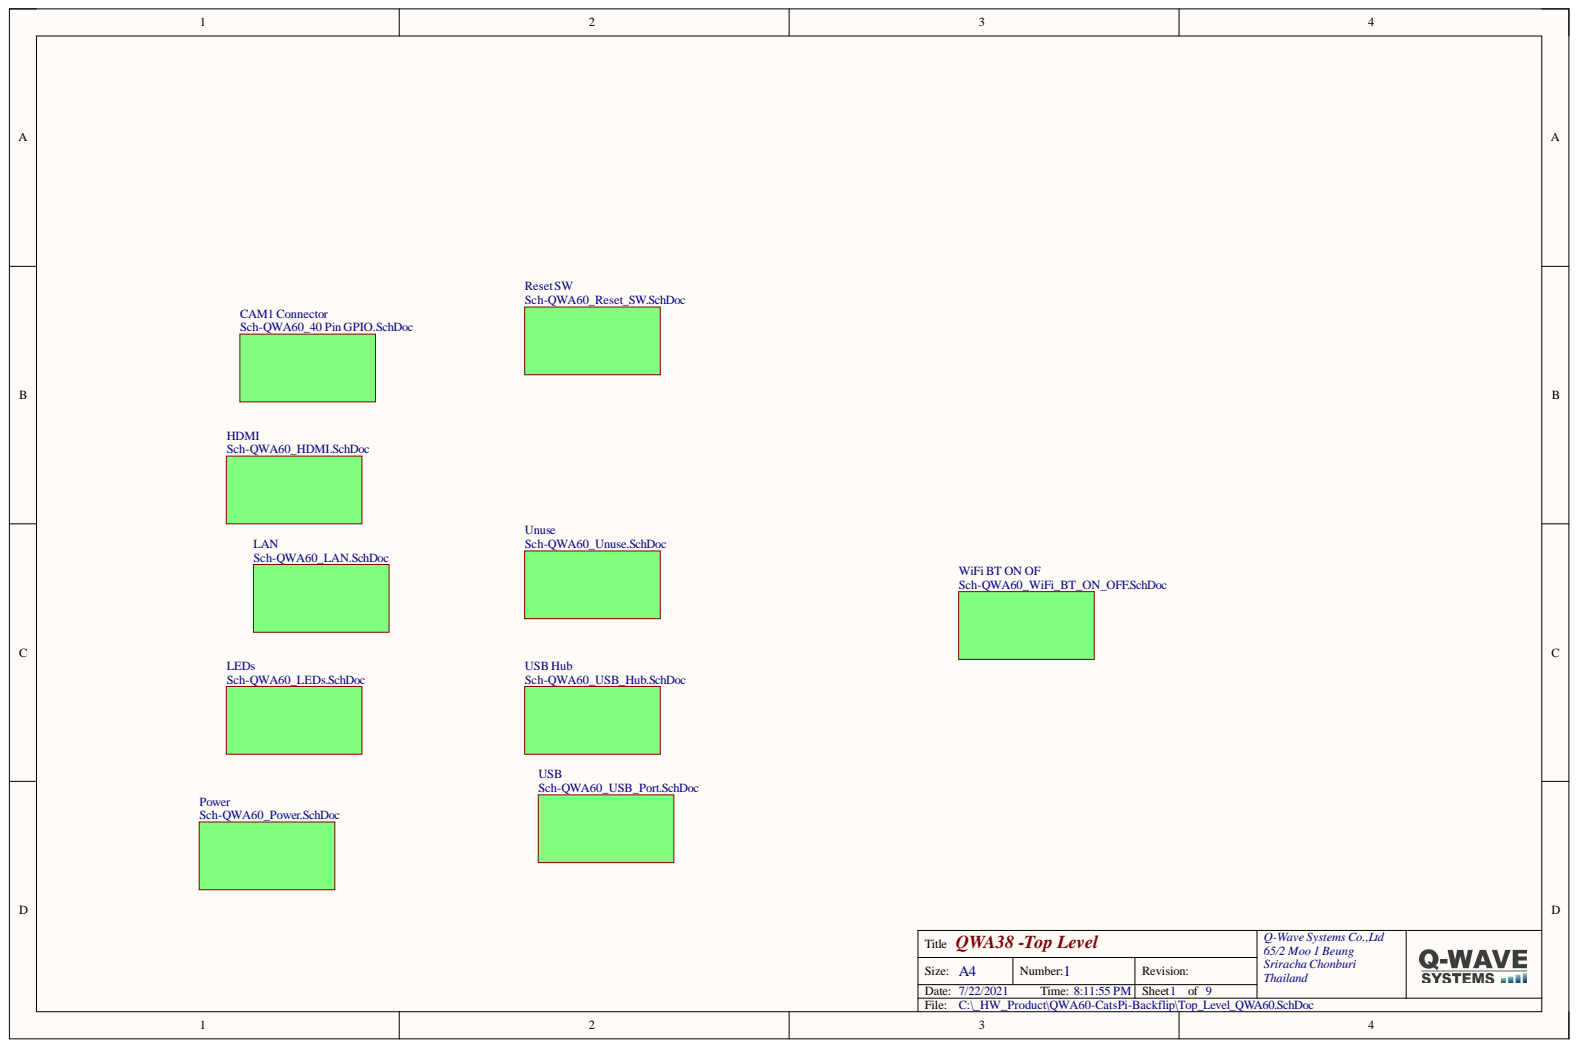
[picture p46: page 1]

CAM1 Connector
Sch-QWA60_40 Pin GPIO.SchDoc

WiFi BT ON OF
Sch-QWA60_WiFi_BT_ON_OFF.SchDoc

QWA38 -Top Level Title | Q-Wave Systems Co.,Ltd 65/2 Moo 1 Beung Sriracha Chonburi Thailand

A4 Size: | 1 Number: | Revision:

Date: 7/22/2021 Time: 8:11:55 PM | | Sheet 1 of 9

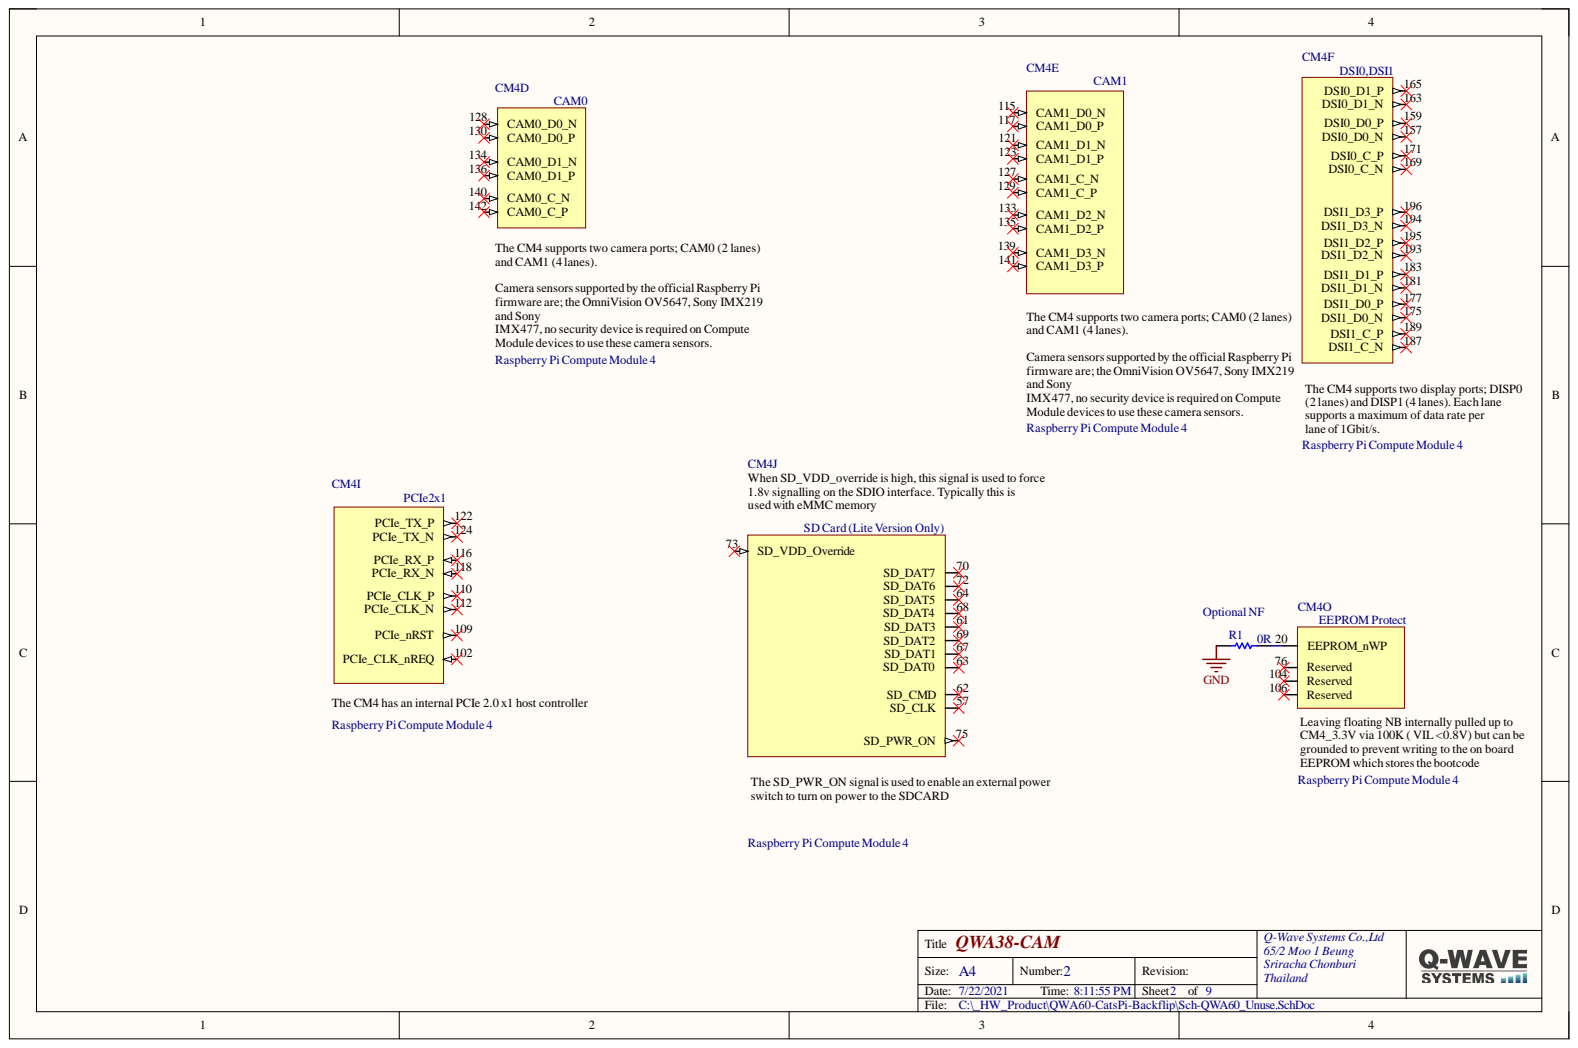
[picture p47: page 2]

lane of 1Gbit/s. CM4F Raspberry Pi Compute Module

a sensors supported by the official

curity devic
es to use these

CM4 supports two display ports; DI
a maximum of data

ride is high, this signal is used to

rnally pulled up to

event writing to the on boa
es the bootcode

switch to turn on powe

R_ON signal is used to

Q WA38-CAM Titl e | Q-Wav e Systems Co. , Ltd 65/2 Moo 1 Beung Sriracha Chonbur i Thailan d

A4 Siz e : | 2 Numbe r : | R evision :

Da te : 7/22/202 1 Time : 8:11:55 P M | | She e t 2 o f 9

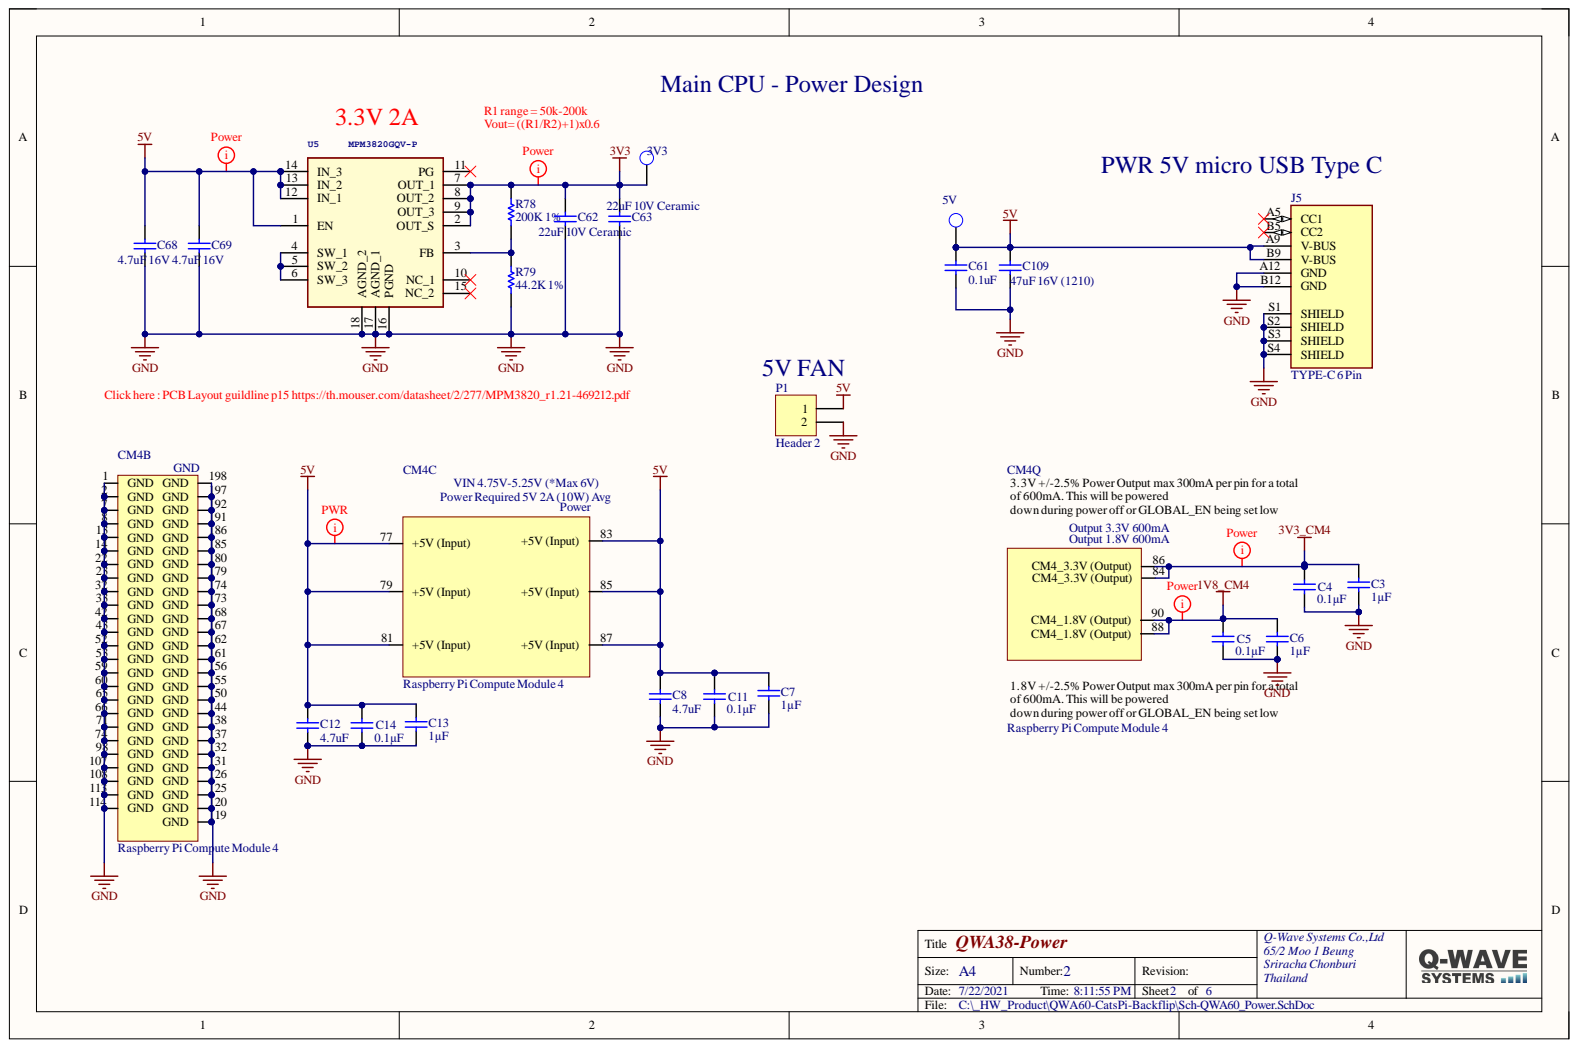
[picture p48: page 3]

Main CPU - Power Design

BLayout guildline p15 https://th.mouse

600mA. This will be powe
wn during powe

r off or GLOBAL_EN being set low

Compute Module

Q Titl e | Q-Wav e Systems Co. , Ltd 65/2 Moo 1 Beung Sriracha Chonbur i Thailan d

A4 Siz e : | Numbe r : | R evision :

Da te : 7/22/202 1 Time : 8:11:55 P M | | She e t 2 o f 6

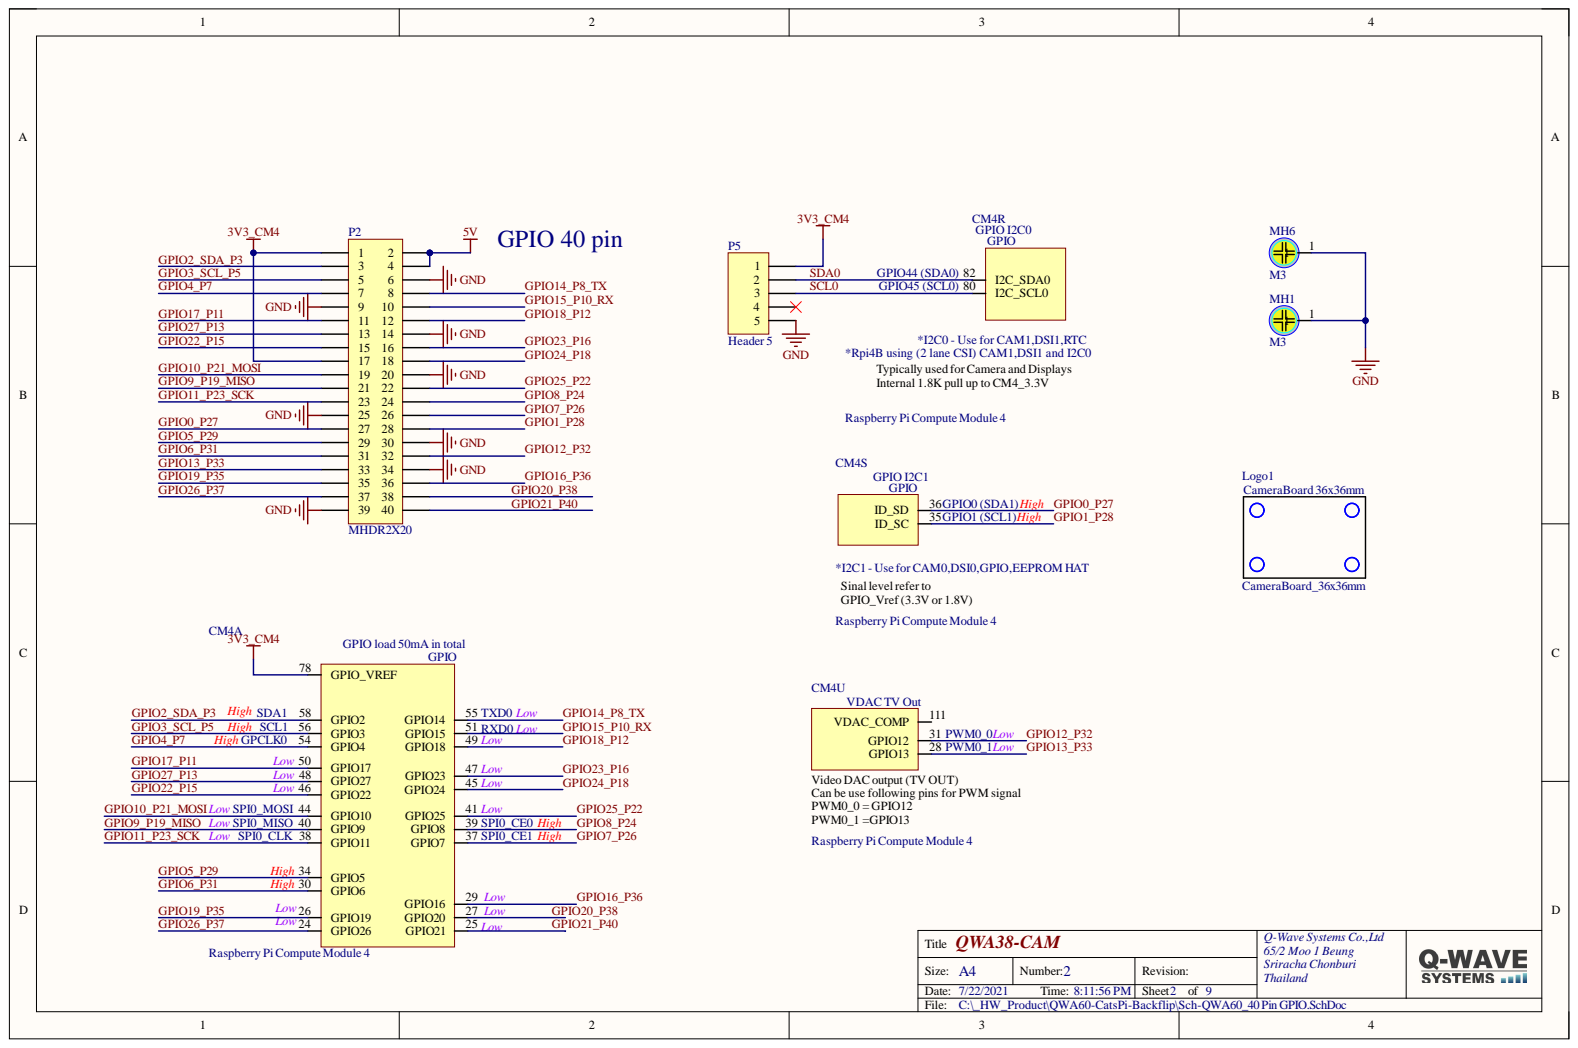
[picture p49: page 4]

rnal 1.8K pull up to

IO load 50mA in tota

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

A4 Siz e : | 2 Numbe r : | R evision :

Da te : 7/22/202 1 Time : 8:11:56 P M | | She e t 2 o f 9

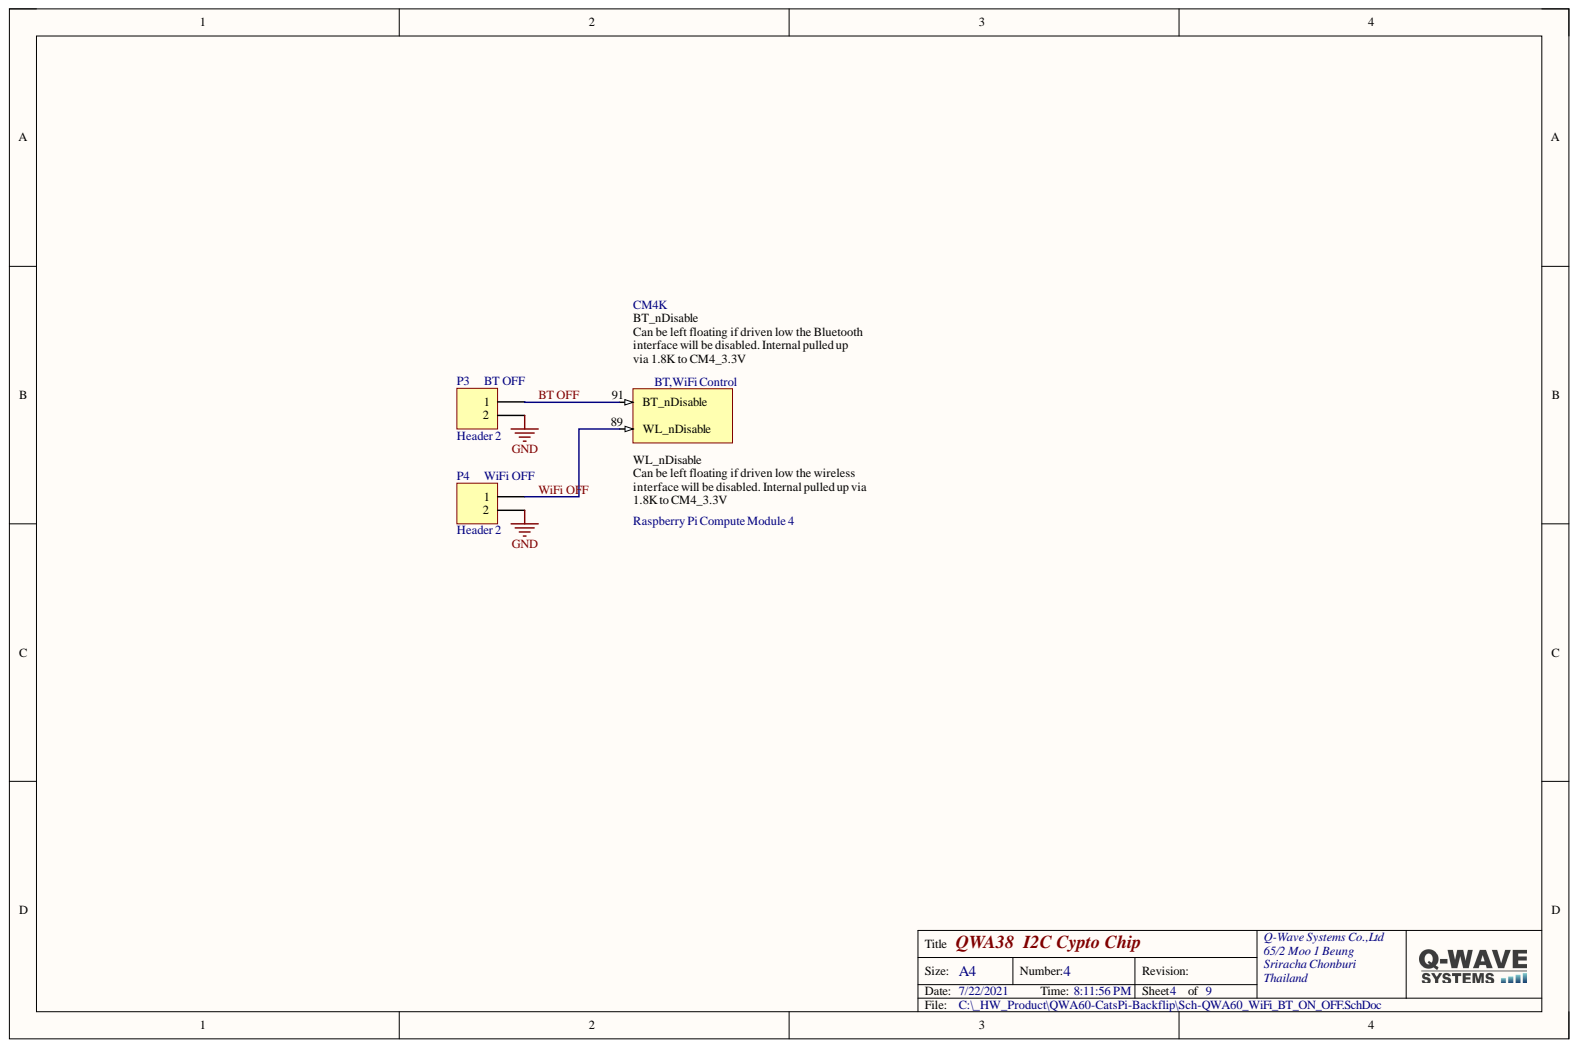
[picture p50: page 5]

BT_nDisable
Can be left floating if driven low the Bluetooth
interface will be disabled.Internal pulled up
via 1.8K to CM4_3.3V

WL_nDisable
Can be left floating if driven low the wireless
interface will be disabled.Internal pulled up via
1.8Kto CM4_3.3V

Raspberry Pi Compute Module 4

QWA38 I2C Cypto Chip Title | Q-Wave Systems Co.,Ltd 65/2 Moo 1 Beung Sriracha Chonburi Thailand

A4 Size: | 4 Number: | Revision:

Date: 7/22/2021 Time: 8:11:56 PM | | Sheet 4 of 9

C:\_HW_Product\QWA60-CatsPi-Backflip\Sch-QWA60_WiFi_BT_ON_OFF.SchDoc

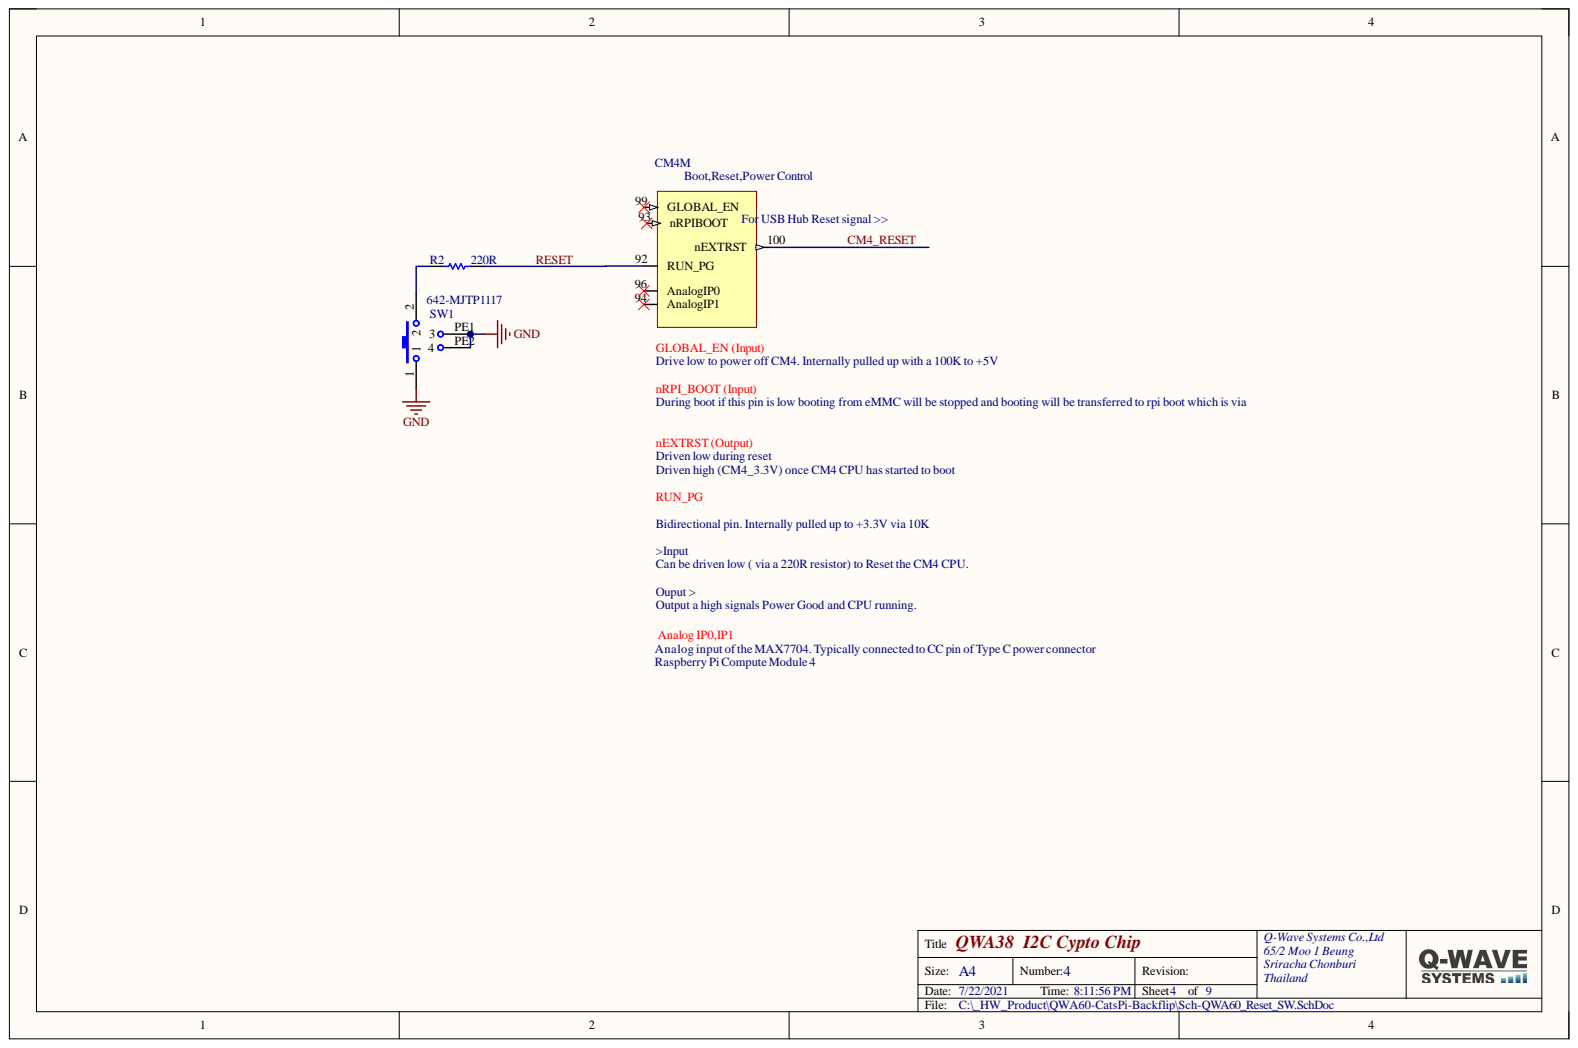
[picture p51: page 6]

GLOBAL_EN
Drive low to powe

rnally pulled up with

During boot if this pin is low booting

eMMC will be stopped

and booting will be tr

rpi boot which is via

rnally pulled up to

Input Can be driven low

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

A4 Siz e : | Numbe r : | R evision :

Da te : 7/22/202 1 Time : 8:11:56 P M | | She e t 4 o f 9

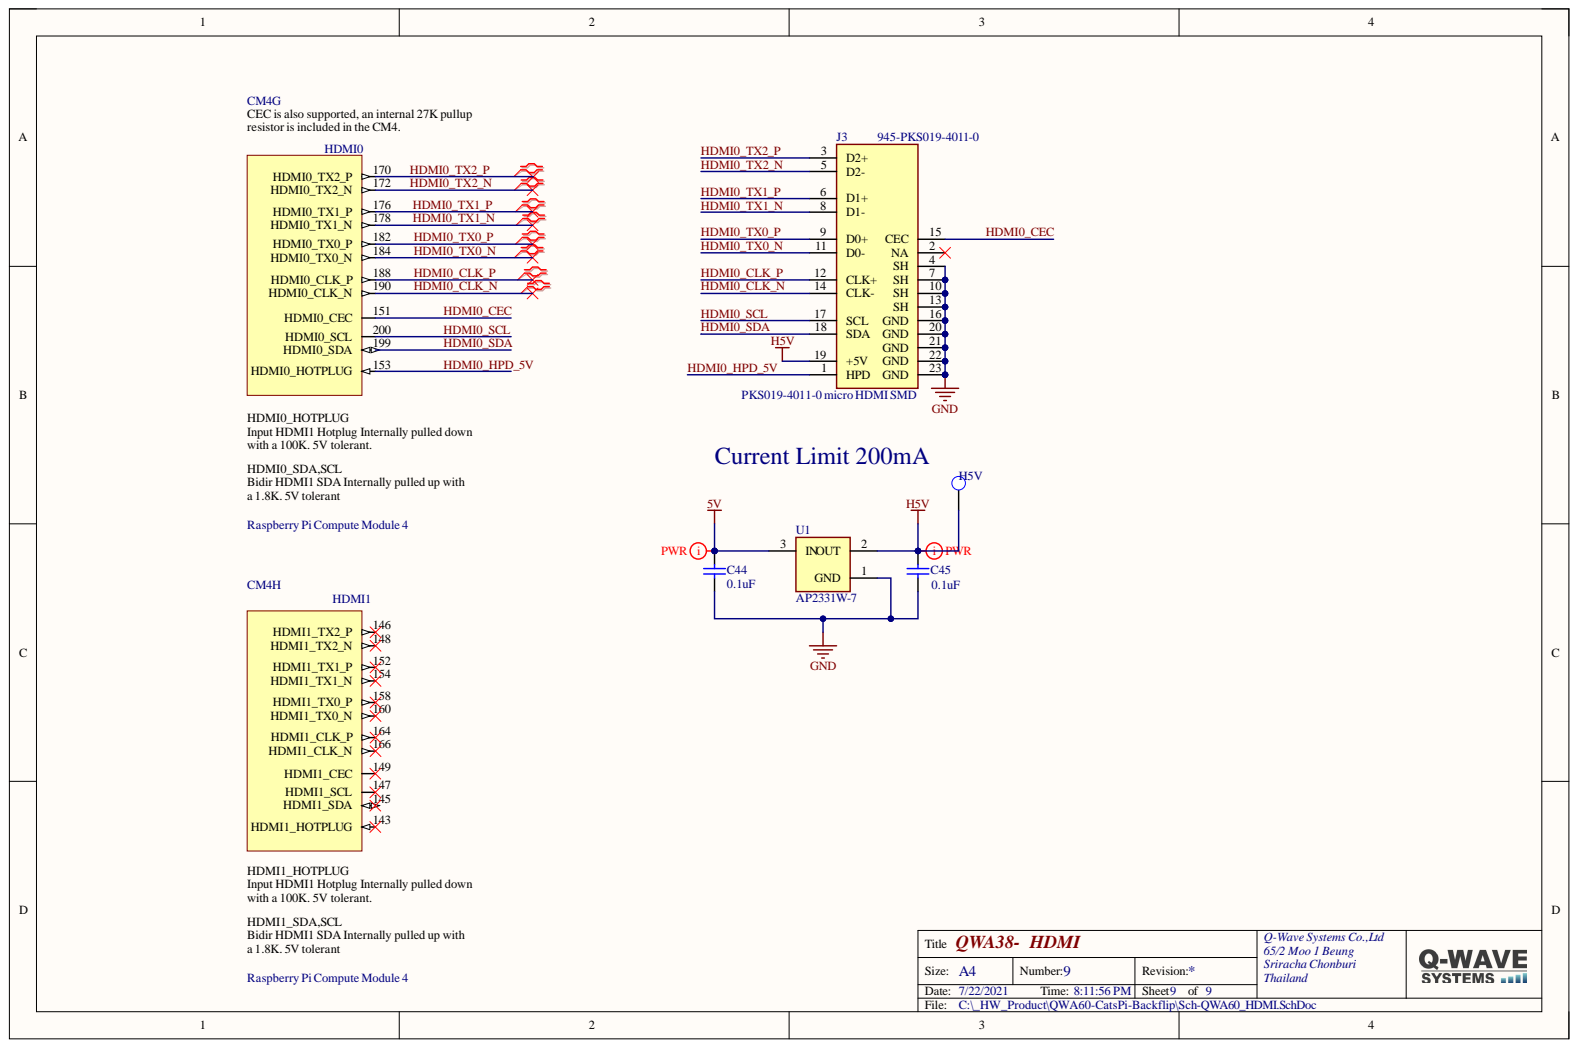
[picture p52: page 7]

CEC is also supported, an internal 27K pullup
resistor is included in the CM4.

HDMI0_HOTPLUG
Input HDMI1 Hotplug Internally pulled down
with a 100K. 5V tolerant.

HDMI0_SDA,SCL
Bidir HDMI1 SDA Internally pulled up with
a 1.8K. 5V tolerant

Raspberry Pi Compute Module 4

HDMI1_HOTPLUG

HDMI1_SDA,SCL

QWA38- HDMI Title | Q-Wave Systems Co.,Ltd 65/2 Moo 1 Beung Sriracha Chonburi Thailand

A4 Size: | 9 Number: | * Revision:

Date: 7/22/2021 Time: 8:11:56 PM | | Sheet 9 of 9

C:\_HW_Product\QWA60-CatsPi-Backflip\Sch-QWA60_HDMI.SchDoc

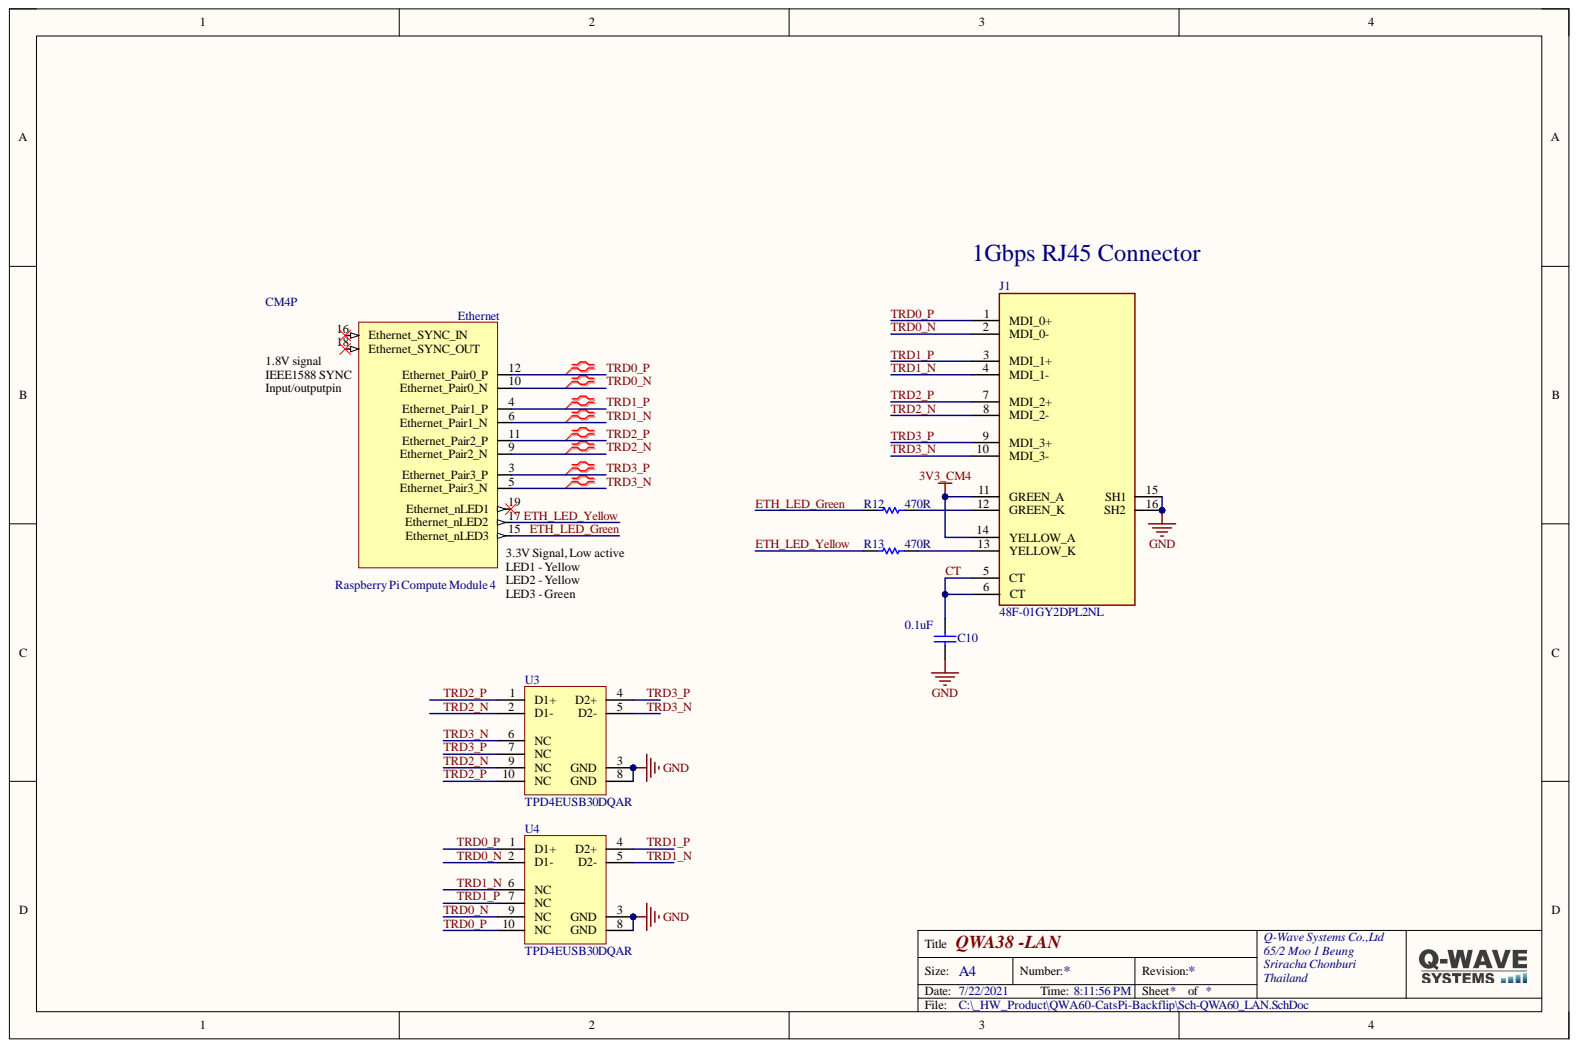
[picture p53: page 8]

A4 Siz e : | * Numbe r : | * R evision :

Da te : 7/22/202 1 Time : 8:11:56 P M | | She e t * o f *

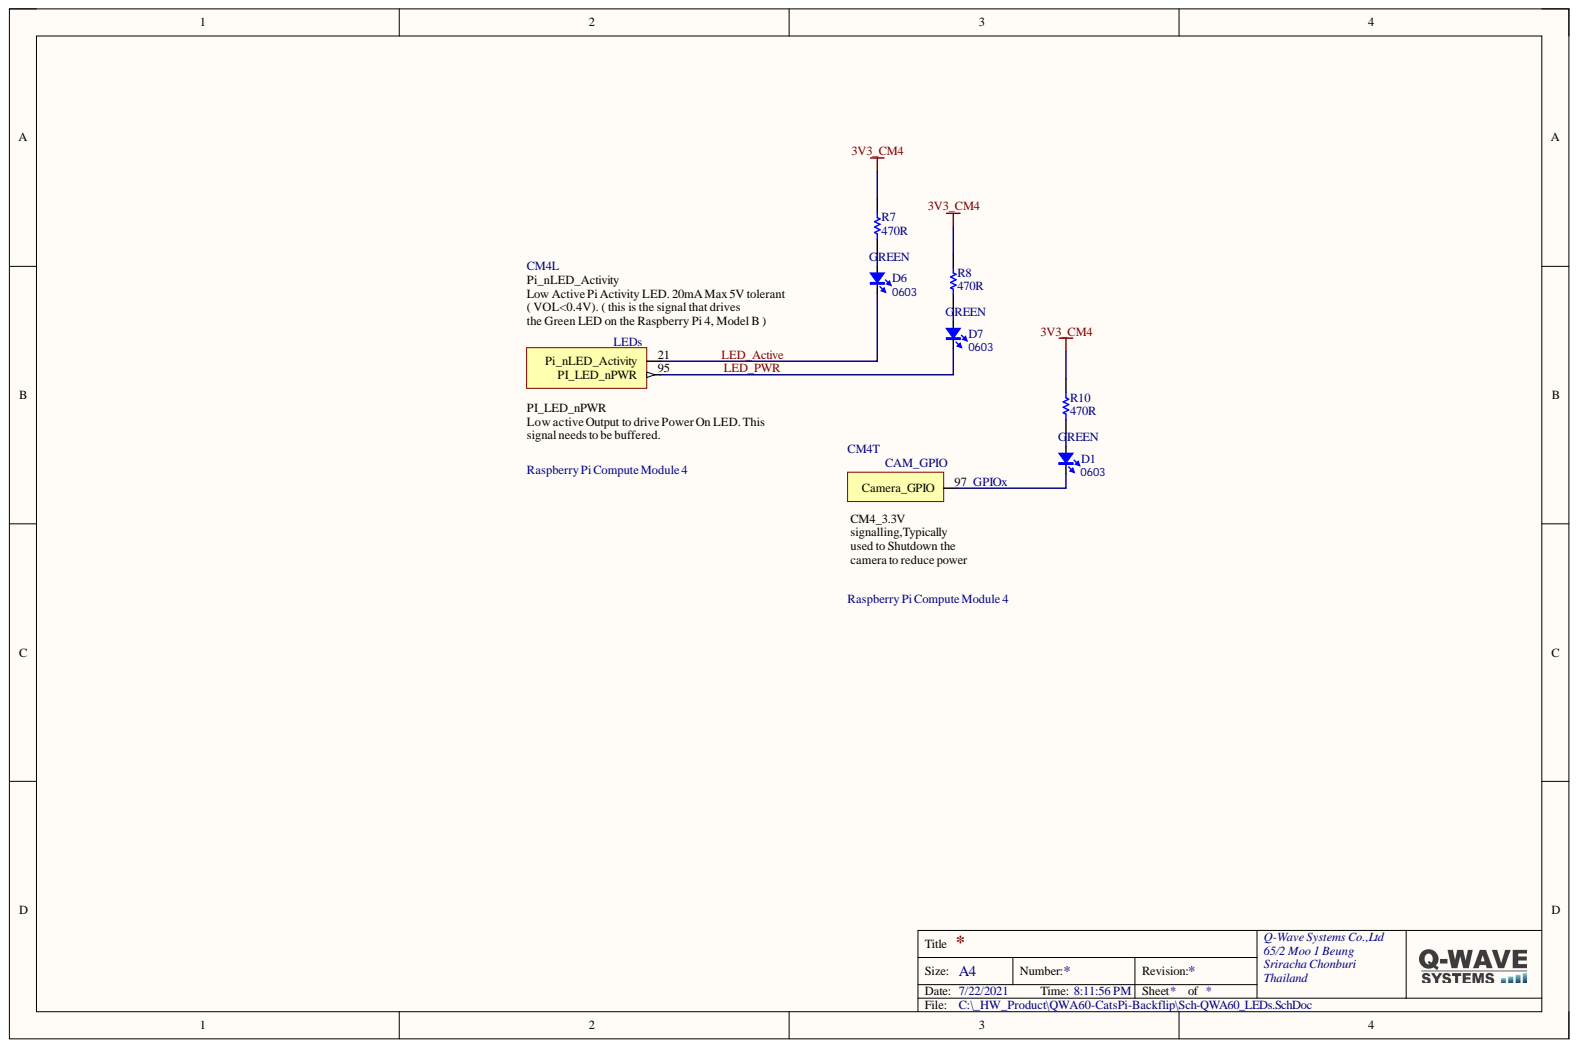
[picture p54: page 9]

Pi Activity LED. 20mAMax 5V tole
en LED on the

( this is the signal that drive

ctive Output to drive

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

A4 Siz e : | * Numbe r : | * R evision :

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

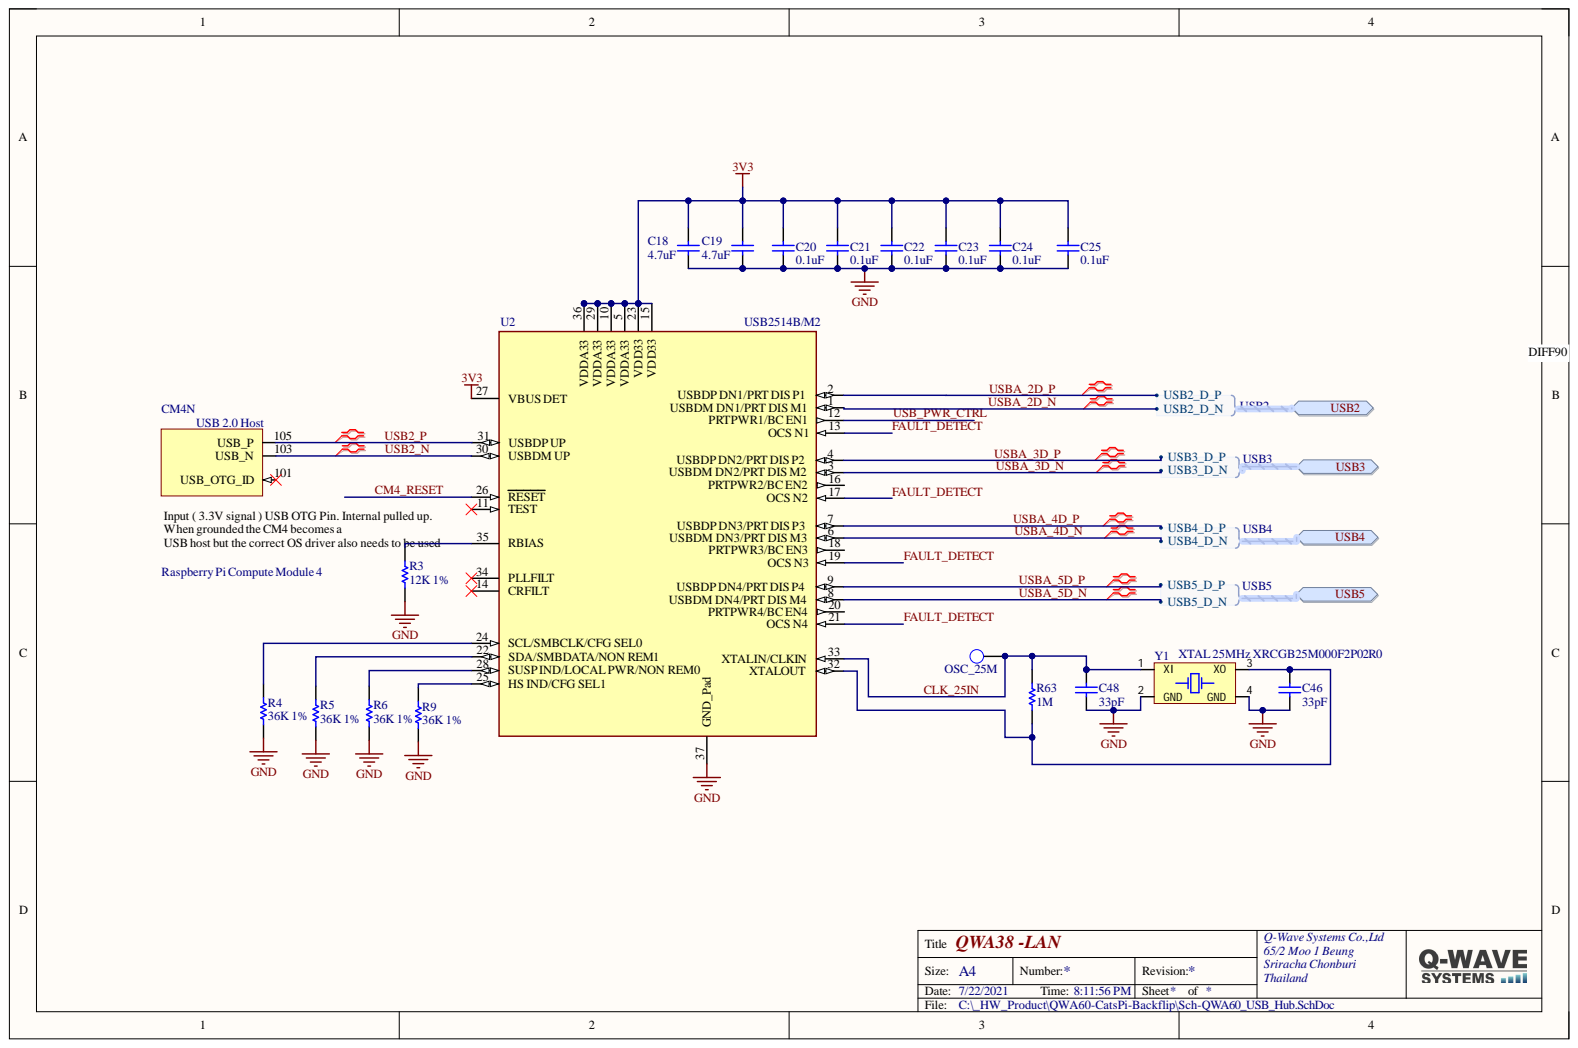
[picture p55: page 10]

eds to be use

XI GND | GND

Q WA38 -LAN Titl e | Q-Wav e Systems Co. , Ltd 65/2 Moo 1 Beung Sriracha Chonbur i Thailan d

A4 Siz e : | * Numbe r : | * R evision :

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

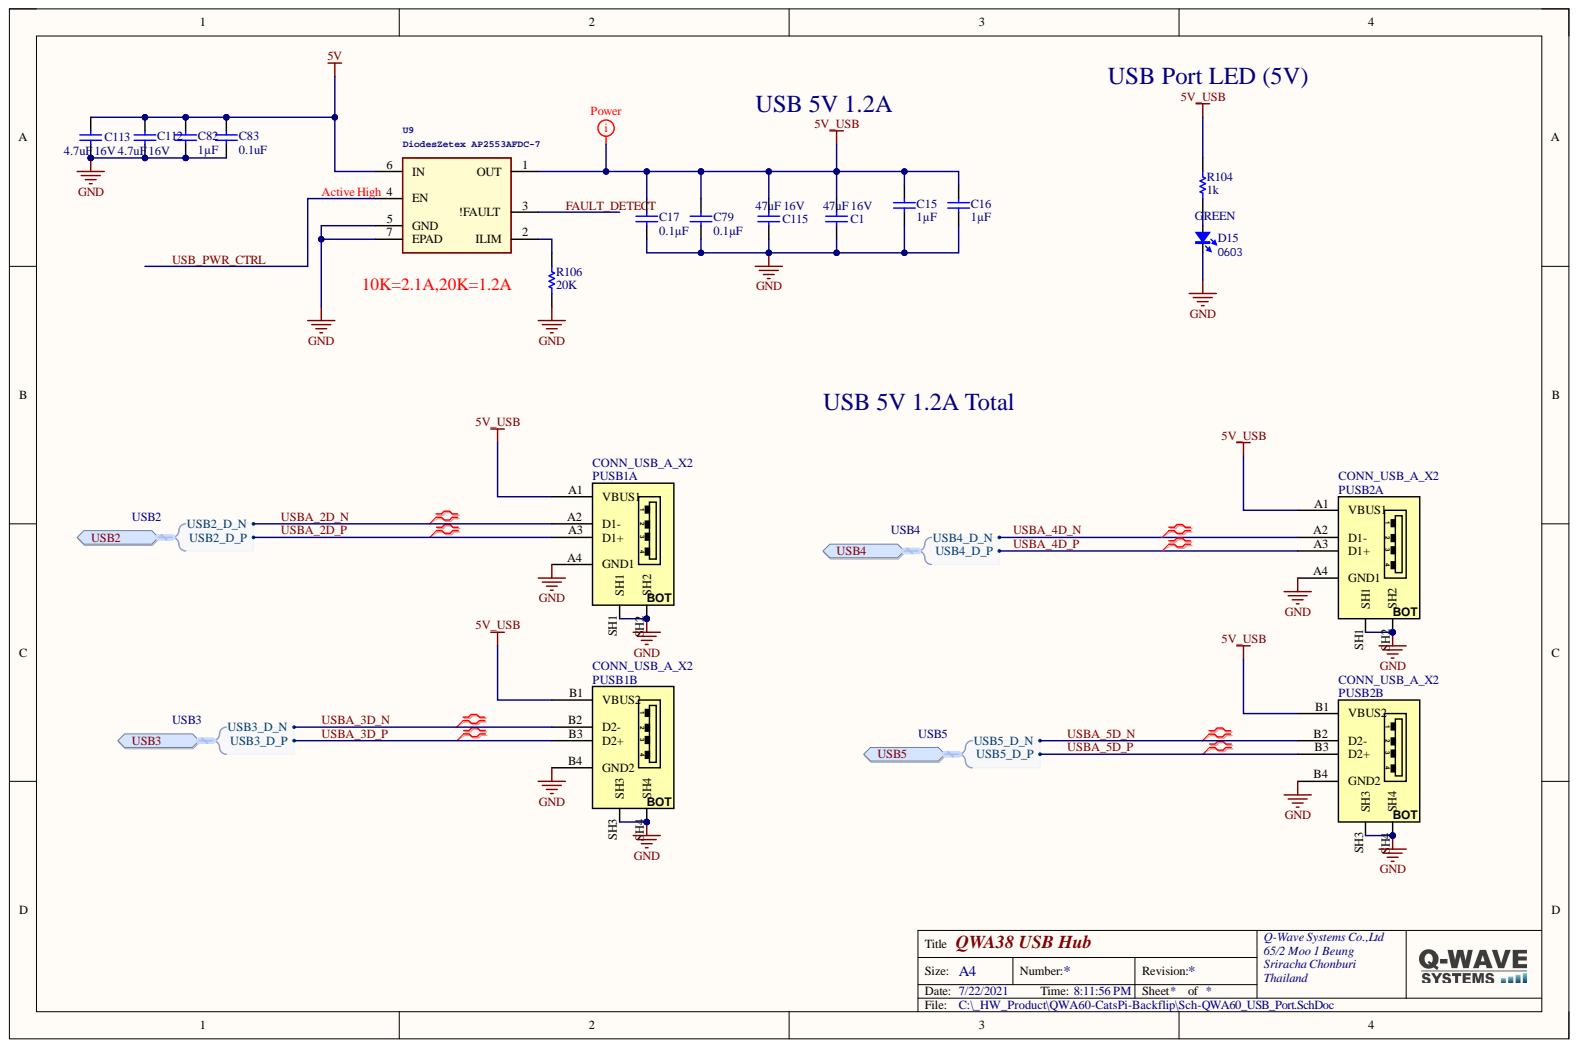
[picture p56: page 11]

QWA38 USB Hub Title | Q-Wave Systems Co.,Ltd 65/2 Moo 1 Beung Sriracha Chonburi Thailand

A4 Size: | * Number: | * Revision:

Date: 7/22/2021 Time: 8:11:56 PM | | Sheet * of *

C:\_HW_Product\QWA60-CatsPi-Backflip\Sch-QWA60_USB_Port.SchDoc

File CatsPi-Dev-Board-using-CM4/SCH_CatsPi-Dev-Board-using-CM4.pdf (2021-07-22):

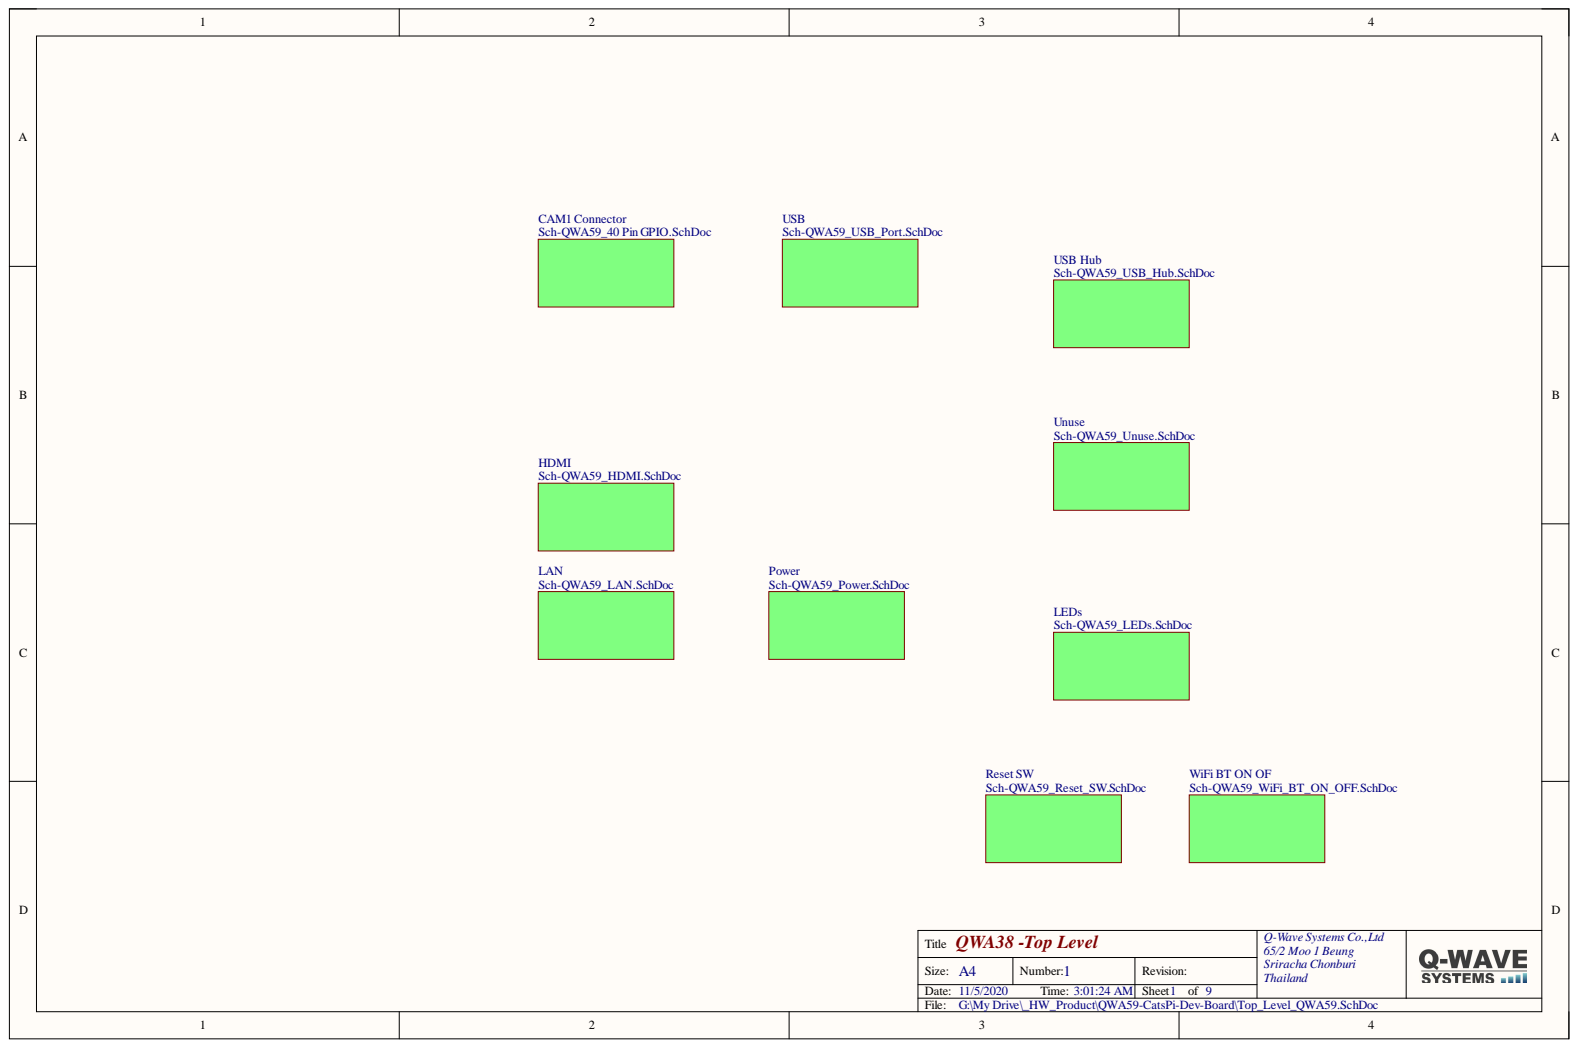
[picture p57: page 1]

CAM1 Connector
Sch-QWA59_40 Pin GPIO.SchDoc

WiFi BT ON OF
Sch-QWA59_WiFi_BT_ON_OFF.SchDoc

QWA38 -Top Level Title | Q-Wave Systems Co.,Ltd 65/2 Moo 1 Beung Sriracha Chonburi Thailand

A4 Size: | 1 Number: | Revision:

Date: 11/5/2020 Time: 3:01:24 AM | | Sheet 1 of 9

G:\My Drive\_HW_Product\QWA59-CatsPi-Dev-Board\Top_Level_QWA59.SchDoc


ane of 1Gbit/s. CM4F Raspberry PiCompute Modul

a sensors supported by the offi

es to use these

rna
iting to the on boa

The
switch to turn on powe

Q WA38-CAM Titl e | Q-Wav e Systems Co. , L td 65/2 Moo 1 Beung Sriracha Chonb u ri Thaila n d

A4 S i z e : | 2 Numbe r : | R e vision:

Date : 11/5/202 0 Time : 3:01:24 AM | | She e t 2 of 9


GPIO 40 pin
GND GND GND GND GND

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

A4 S i z e : | 2 Numbe r : | R e vision:

Date : 11/5/202 0 Time : 3:01:24 AM | | She e t 2 of 9


ine p15 https://th.mouse

Q Titl e | Q-Wav e Systems Co. , L td 65/2 Moo 1 Beung Sriracha Chonb u ri Thaila n d

A4 S i z e : | Numbe r : | R e vision:

Date : 11/5/202 0 Time : 3:01:24 AM | | She e t 2 of 6


BT_nDisable
Can be left floating if driven low the Bluetooth
interface will be disabled. Internal pulled up
via 1.8K to CM4_3.3V

WL_nDisable
Can be left floating if driven low the wireless
interface will be disabled. Internal pulled up via

QWA38 I2C Cypto Chip Title | Q-Wave Systems Co.,Ltd 65/2 Moo 1 Beung Sriracha Chonburi Thailand

A4 Size: | 4 Number: | Revision:

Date: 11/5/2020 Time: 3:01:25 AM | | Sheet 4 of 9

G:\My Drive\_HW_Product\QWA59-CatsPi-Dev-Board\Sch-QWA59_WiFi_BT_ON_OFF.SchDoc


Input Can be dr

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

A4 S i z e : | Numbe r : | R e vision:

Date : 11/5/202 0 Time : 3:01:25 AM | | She e t 4 of 9


CEC is also supported, an internal 27K pullup
resistor is included in the CM4.

HDMI0_HOTPLUG
Input HDMI1 Hotplug Internally pulled down
with a 100K. 5V tolerant.

HDMI0_SDA,SCL
Bidir HDMI1 SDA Internally pulled up with
a 1.8K. 5V tolerant

HDMI1_HOTPLUG

HDMI1_SDA,SCL

QWA38- HDMI Title | Q-Wave Systems Co.,Ltd 65/2 Moo 1 Beung Sriracha Chonburi Thailand

A4 Size: | 9 Number: | * Revision:

Date: 11/5/2020 Time: 3:01:25 AM | | Sheet 9 of 9

G:\My Drive\_HW_Product\QWA59-CatsPi-Dev-Board\Sch-QWA59_HDMI.SchDoc


A4 S i z e : | * Numbe r : | * R e vision:

Date : 11/5/202 0 Time : 3:01:25 AM | | She e t * of *


ve Output to dr
eds to be buffe

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

A4 S i z e : | * Numbe r : | * R e vision:

Date : 11/5/202 0 Time : 3:01:25 AM | | She e t * of *


eds to be use

XI GND | GND

Q WA38 -LAN Titl e | Q-Wav e Systems Co. , L td 65/2 Moo 1 Beung Sriracha Chonb u ri Thaila n d

A4 S i z e : | * Numbe r : | * R e vision:

Date : 11/5/202 0 Time : 3:01:25 AM | | She e t * of *


QWA38 USB Hub Title | Q-Wave Systems Co.,Ltd 65/2 Moo 1 Beung Sriracha Chonburi Thailand

A4 Size: | * Number: | * Revision:

Date: 11/5/2020 Time: 3:01:25 AM | | Sheet * of *

G:\My Drive\_HW_Product\QWA59-CatsPi-Dev-Board\Sch-QWA59_USB_Port.SchDoc

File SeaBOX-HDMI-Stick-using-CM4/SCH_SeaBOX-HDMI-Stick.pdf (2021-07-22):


Boot,Reset,Power Control

GLOBAL_EN (Input)
Drive low to power off CM4. Internally pulled up with a 100K to +5V

nRPI_BOOT (Input)
During boot if this pin is low booting from eMMC will be stopped and booting will be transferred to rpi boot which is via

nEXTRST (Output)
Driven low during reset
Driven high (CM4_3.3V) once CM4 CPU has started to boot

BT_nDisable
Can be left floating if driven low the Bluetooth
interface will be disabled. Internal pulled up
via 1.8K to CM4_3.3V

Bidirectional pin. Internally pulled up to +3.3V via 10K

>Input
Can be driven low ( via a 220R resistor) to Reset the CM4 CPU.

Ouput >
Output a high signals Power Good and CPU running.

Analog IP0,IP1
Analog input of the MAX7704. Typically connected to CC pin of Type C power connector
Raspberry PiCompute Module 4

WL_nDisable
Can be left floating if driven low the wireless
interface will be disabled. Internal pulled up via

Leaving floating NB internally pulled up to
CM4_3.3V via 100K ( VIL<0.8V) but can be
grounded to prevent writing to the on board
EEPROM which stores the bootcode

* Title | Q-Wave Systems Co.,Ltd 65/2 Moo 1 Beung Sriracha Chonburi Thailand

A4 Size: | * Number: | * Revision:

Date: 11/20/2020 Time: 10:45:43 AM | | Sheet * of *

G:\My Drive\_HW_Product\QWA53-SeaBOX\BT WiFiPower Reset Control.SchDoc


* Title | Q-Wave Systems Co.,Ltd 65/2 Moo 1 Beung Sriracha Chonburi Thailand

A4 Size: | * Number: | * Revision:

Date: 11/20/2020 Time: 10:45:43 AM | | Sheet * of *

G:\My Drive\_HW_Product\QWA53-SeaBOX\Connector.SchDoc


a sensors supported by the offi

es to use these

* Titl e | Q-Wav e Systems Co. , L td 65/2 Moo 1 Beung Sriracha Chonb u ri Thaila n d

A4 S i z e : | * Numbe r : | * R e vision:

Date : 11/20/20 2 0 Time : 10:45:43 AM | | She e t * of *


ane of 1Gbit/s. CM4F Raspberry PiCompute Modul

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

A4 S i z e : | * Numbe r : | * R e vision:

Date : 11/20/20 2 0 Time : 10:45:43 AM | | She e t * of *

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

A4 S i z e : | * Numbe r : | * R e vision:

Date : 11/20/20 2 0 Time : 10:45:43 AM | | She e t * of *


GPIO_VREF Must be connected to CM4_3.3V ( pins 84 and 86 ) for 3.3V GPIO or

CM4_1.8V ( pins 88 and 90) for 1.8V GPIO. This pin cannot be floating or connected to ground

* Title | Q-Wave Systems Co.,Ltd 65/2 Moo 1 Beung Sriracha Chonburi Thailand

A4 Size: | * Number: | * Revision:

Date: 11/20/2020 Time: 10:45:43 AM | | Sheet * of *

G:\My Drive\_HW_Product\QWA53-SeaBOX\GPIO.SchDoc


GND GND GND GND GND

HDM
differential pairs, each sig

uld ideally be matched to better

CEC is also su

ded in the CM

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

A4 S i z e : | * Numbe r : | * R e vision:

Date : 11/20/20 2 0 Time : 10:45:43 AM | | She e t * of *


ve Output to dr
eds to be buffe

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

A4 S i z e : | * Numbe r : | * R e vision:

Date : 11/20/20 2 0 Time : 10:45:43 AM | | She e t * of *

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

A4 S i z e : | * Numbe r : | * R e vision:

Date : 11/20/20 2 0 Time : 10:45:44 AM | | She e t * of *

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

A4 S i z e : | * Numbe r : | * R e vision:

Date : 11/20/20 2 0 Time : 10:45:44 AM | | She e t * of *


When SD_VDD_override is high, this signal is used to force
1.8v signalling on the SDIO interface. Typically this is
used with eMMC memory

SD Card (Lite Version Only)

The SD_PWR_ON signal is used to enable an external power
switch to turn on power to the SDCARD

* Title | Q-Wave Systems Co.,Ltd 65/2 Moo 1 Beung Sriracha Chonburi Thailand

A4 Size: | * Number: | * Revision:

Date: 11/20/2020 Time: 10:45:44 AM | | Sheet * of *

G:\My Drive\_HW_Product\QWA53-SeaBOX\SD Card.SchDoc


The CM4 is a compact 40 × 55mm module. The Module is 4.7mm deep, but when connected
the height will be 5.078 or
6.578 mm depending on the stacking height chosen.
1. 4 × M2.5 Mounting holes (inset 3.5mm from module edge)
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

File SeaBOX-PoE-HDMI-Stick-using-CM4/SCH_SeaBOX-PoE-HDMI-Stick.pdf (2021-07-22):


Boot,Reset,Power Control

GLOBAL_EN (Input)
Drive low to power off CM4. Internally pulled up with a 100K to +5V

nRPI_BOOT (Input)
During boot if this pin is low booting from eMMC will be stopped and booting will be transferred to rpi boot which is via

nEXTRST (Output)
Driven low during reset
Driven high (CM4_3.3V) once CM4 CPU has started to boot

BT_nDisable
Can be left floating if driven low the Bluetooth
interface will be disabled. Internal pulled up
via 1.8K to CM4_3.3V

Bidirectional pin. Internally pulled up to +3.3V via 10K

>Input
Can be driven low ( via a 220R resistor) to Reset the CM4 CPU.

Ouput >
Output a high signals Power Good and CPU running.

Analog IP0,IP1
Analog input of the MAX7704. Typically connected to CC pin of Type C power connector
Raspberry PiCompute Module 4

WL_nDisable
Can be left floating if driven low the wireless
interface will be disabled. Internal pulled up via

Leaving floating NB internally pulled up to
CM4_3.3V via 100K ( VIL<0.8V) but can be
grounded to prevent writing to the on board
EEPROM which stores the bootcode

* Title | Q-Wave Systems Co.,Ltd 65/2 Moo 1 Beung Sriracha Chonburi Thailand

A4 Size: | * Number: | * Revision:

Date: 11/20/2020 Time: 11:34:28 AM | | Sheet * of *

G:\My Drive\_HW_Product\QWA62-SeaBOX-PoE\BT WiFiPower Reset Control.SchDoc


* Title | Q-Wave Systems Co.,Ltd 65/2 Moo 1 Beung Sriracha Chonburi Thailand

A4 Size: | * Number: | * Revision:

Date: 11/20/2020 Time: 11:34:28 AM | | Sheet * of *

G:\My Drive\_HW_Product\QWA62-SeaBOX-PoE\Connector.SchDoc


a sensors supported by the offi

es to use these

* Titl e | Q-Wav e Systems Co. , L td 65/2 Moo 1 Beung Sriracha Chonb u ri Thaila n d

A4 S i z e : | * Numbe r : | * R e vision:

Date : 11/20/20 2 0 Time : 11:34:28 AM | | She e t * of *


ane of 1Gbit/s. CM4F Raspberry PiCompute Modul

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

A4 S i z e : | * Numbe r : | * R e vision:

Date : 11/20/20 2 0 Time : 11:34:28 AM | | She e t * of *

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

A4 S i z e : | * Numbe r : | * R e vision:

Date : 11/20/20 2 0 Time : 11:34:29 AM | | She e t * of *


GPIO_VREF Must be connected to CM4_3.3V ( pins 84 and 86 ) for 3.3V GPIO or

CM4_1.8V ( pins 88 and 90) for 1.8V GPIO. This pin cannot be floating or connected to ground

* Title | Q-Wave Systems Co.,Ltd 65/2 Moo 1 Beung Sriracha Chonburi Thailand

A4 Size: | * Number: | * Revision:

Date: 11/20/2020 Time: 11:34:29 AM | | Sheet * of *

G:\My Drive\_HW_Product\QWA62-SeaBOX-PoE\GPIO.SchDoc


GND GND GND GND GND

HDM
differential pairs, each sig

uld ideally be matched to better

CEC is also su

ded in the CM

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

A4 S i z e : | * Numbe r : | * R e vision:

Date : 11/20/20 2 0 Time : 11:34:29 AM | | She e t * of *


ve Output to dr
eds to be buffe

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

A4 S i z e : | * Numbe r : | * R e vision:

Date : 11/20/20 2 0 Time : 11:34:29 AM | | She e t * of *

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

A4 S i z e : | * Numbe r : | * R e vision:

Date : 11/20/20 2 0 Time : 11:34:29 AM | | She e t * of *


WR PWR 5V micro USB

S 3 | | R aspbe r ry P i Compute Modul

WRi PWRi PWR i PWR

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

A4 S i z e : | * Numbe r : | * R e vision:

Date : 11/20/20 2 0 Time : 11:34:29 AM | | She e t * of *


When SD_VDD_override is high, this signal is used to force
1.8v signalling on the SDIO interface. Typically this is
used with eMMC memory

SD Card (Lite Version Only)

The SD_PWR_ON signal is used to enable an external power
switch to turn on power to the SDCARD

* Title | Q-Wave Systems Co.,Ltd 65/2 Moo 1 Beung Sriracha Chonburi Thailand

A4 Size: | * Number: | * Revision:

Date: 11/20/2020 Time: 11:34:29 AM | | Sheet * of *

G:\My Drive\_HW_Product\QWA62-SeaBOX-PoE\SD Card.SchDoc

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

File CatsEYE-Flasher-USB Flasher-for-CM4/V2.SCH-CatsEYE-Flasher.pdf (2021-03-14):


Boot,Reset,Power Control

GLOBAL_EN (Input)
Drive low to power off CM4. Internally pulled up with a 100K to +5V

nRPI_BOOT (Input)
During boot if this pin is low booting from eMMC will be stopped and booting will be transferred to rpi boot which is via

nEXTRST (Output)
Driven low during reset
Driven high (CM4_3.3V) once CM4 CPU has started to boot

Bidirectional pin. Internally pulled up to +3.3V via 10K

>Input
Can be driven low ( via a 220R resistor) to Reset the CM4 CPU.

Ouput >
Output a high signals Power Good and CPU running.

Analog IP0,IP1
Analog input ofthe MAX7704. Typically connected to CCpin of TypeCpower connector
Raspberry Pi Compute Module 4

BT_nDisable
Can be left floating if driven low the Bluetooth
interface will be disabled.Internal pulled up
via 1.8K to CM4_3.3V

Leaving floating NB internally pulled up to
CM4_3.3V via 100K ( VIL <0.8V) but can be
grounded to prevent writing to the on board
EEPROM which stores the bootcode

WL_nDisable
Can be left floating if driven low the wireless
interface will be disabled.Internal pulled up via
1.8Kto CM4_3.3V

* Title | Q-Wave Systems Co.,Ltd 65/2 Moo 1 Beung Sriracha Chonburi Thailand

A4 Size: | * Number: | * Revision:

Date: 1/15/2021 Time: 4:53:36 PM | | Sheet * of *

G:\My Drive\_HW_Product\QWA56-CatsEYE-Flasher\BT WiFi Power Reset Control.SchDoc


* Title | Q-Wave Systems Co.,Ltd 65/2 Moo 1 Beung Sriracha Chonburi Thailand

A4 Size: | * Number: | * Revision:

Date: 1/15/2021 Time: 4:53:37 PM | | Sheet * of *

G:\My Drive\_HW_Product\QWA56-CatsEYE-Flasher\Connector.SchDoc


a sensors supported by the official

curity devic
es to use these

* Titl e | Q-Wav e Systems Co. , Ltd 65/2 Moo 1 Beung Sriracha Chonbur i Thailan d

A4 Siz e : | * Numbe r : | * R evision :

Da te : 1/15/202 1 Time : 4:53:37 P M | | She e t * o f *


lane of 1Gbit/s. CM4F Raspberry Pi Compute Module

CM4 supports two display ports; DI
a maximum of data

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

A4 Siz e : | * Numbe r : | * R evision :

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

A4 Siz e : | * Numbe r : | * R evision :

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


GPIO_VREF Must be connected to CM4_3.3V ( pins 84
and 86 ) for 3.3V GPIO or

CM4_1.8V ( pins 88 and 90) for 1.8V GPIO. This pin
cannot be floating or connected to ground

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

A4 Siz e : | * Numbe r : | * R evision :

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


also supported,
esistor is included in the

rnally pulled up with

HDMI sig
differential pairs, each sig

uld ideally be matched to better

nly have to be

CEC is also su

ded in the CM

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

A4 Siz e : | * Numbe r : | * R evision :

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


Pi Activity LED. 20mAMax 5V tole
en LED on the

( this is the signal that drive

ctive Output to drive

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

A4 Siz e : | * Numbe r : | * R evision :

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

A4 Siz e : | * Numbe r : | * R evision :

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


600mA. This will be powe
wn during powe

r off or GLOBAL_EN being set low

Compute Module

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

A4 Siz e : | * Numbe r : | * R evision :

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


When SD_VDD_override is high, this signal is used to force
1.8v signalling on the SDIO interface. Typically this is
used with eMMCmemory

SD Card (Lite Version Only)

The SD_PWR_ON signal is used to enable an external power
switch to turn on power to the SDCARD

Raspberry Pi Compute Module 4

* Title | Q-Wave Systems Co.,Ltd 65/2 Moo 1 Beung Sriracha Chonburi Thailand

A4 Size: | * Number: | * Revision:

Date: 1/15/2021 Time: 4:53:37 PM | | Sheet * of *
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


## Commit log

2020-10-28 Intial Released
    [3D_Board_View.SchDoc, All Component_0.SchDoc, All Component_1.SchDoc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]
2020-11-05 Update README.md
    Update picture of CatsPi Dev board
2020-11-05 Made some changes in Schlib and PCBlib
    -"CM4.Schlib" - Swap GPIO20 and GPIO21 location.
    -"CM4.Pcblib" - Added CM4 component top overlay to prevent wrong plug CM4 into connector.
    [CM4.PrjPcb, CM4.SchLib, GPIO.SchDoc]
2020-12-04 Add PCB bare board picture
2021-01-02 Create CM4IOv5.PcbDoc
    Official CMIO4 PCB in Altium format
    [CM4IOv5.PcbDoc]
2021-03-14 Update Demo CatEYE_FlasherV2
    [CatsEYE-Flasher_V2.PcbDoc]
2021-07-22 Update PCB file for SeaBox,SeaBox-PoE,CatsPi,CatsPi-HATflip
    Update PCB file and SCH for SeaBox,SeaBox-PoE,CatsPi,CatsPi-HATflip
2021-12-09 Update CM4 Schematic Libs
    [3D_Board_View.SchDoc, All Component_0.SchDoc, All Component_1.SchDoc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]
